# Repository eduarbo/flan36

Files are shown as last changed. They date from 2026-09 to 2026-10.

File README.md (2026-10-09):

# Flan36

**36 keys. Original design. Your keycaps, your frames.**

**[Explore and customize in 3D →](https://eduarbo.github.io/flan36/)** · **[Parts and buying links →](docs/parts.md)** · **[Edit in FreeCAD →](docs/freecad.md)**

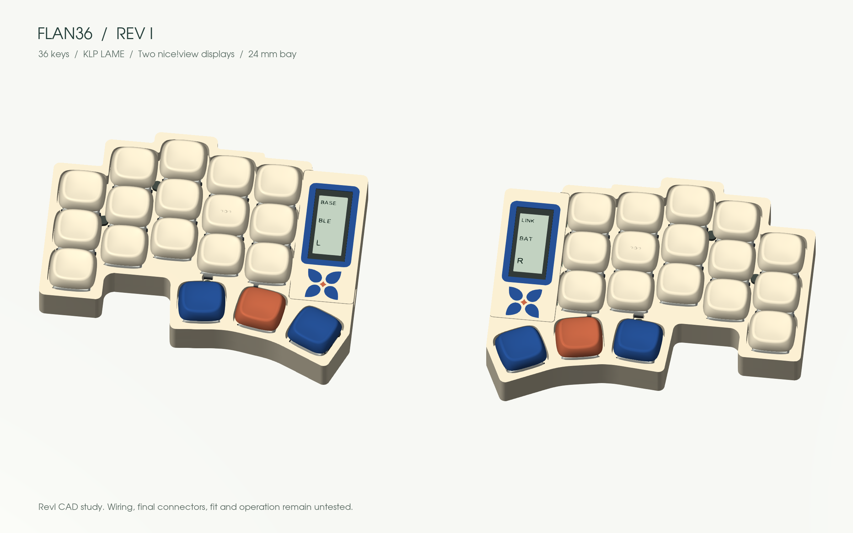
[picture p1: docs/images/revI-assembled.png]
Flan36 revI with interchangeable display frames and original KLP Lamé keycaps


*RevI: key-aligned local curves, four interchangeable cases, optional exposed display stack, magnetic frames and a floor-mounted cell in either battery size. Physical fit untested.*

**[Themes and print kits](docs/themes-printing.md)** — Twenty-eight coordinated themes, personal keycap palettes, linked rim/frame colors and selected STL/3MF parts.

**[Lower, level stack](docs/level-stack.md)** — The frame and removable switch-covering shell reach 13.59 mm; the glass sits 0.20 mm below them. Connector fit remains unqualified.

**[Case variants](docs/cases.md)** — Level, Solid, Color rim and Terrace; actual meshes in the explorer.

Flan36 is a low-profile wireless split keyboard in development by [Eduardo Ruiz](https://github.com/eduarbo). Its original CAD is designed by Eduardo, with five columns and three thumb keys per half.

- **KLP Lamé choices:** all 38 Choc-stem variants catalogued; 28 qualify in at least one position. The viewer checks complete combinations and exports a configuration for FreeCAD.
- **Magnetic frames:** Talavera (default), Game Boy, SNES, 2000s Phone, iPod and Hanafuda. Up to four solid colors in flush inlays, with matching rim and key palettes.
- **Keycap colors:** paint all keys, rows, columns or individual keys; save and share your own palettes.
- **Free tools:** KiCad for electronics, FreeCAD for the case, StepUp for exchange. Editable source, STEP/STL, offline viewer and GLB included.
- **Intended hardware:** Choc v1 hot-swap, two nice!nano controllers and two nice!view displays. One display remains the fallback.

**Status: routed prototype; physical qualification pending.** Both PCBs pass DRC, schematic parity and ERC with no unconnected items. Three [ZMK firmware builds](docs/firmware.md) cover two displays or a left-only display. [Prototype fabrication files and verification](docs/electronics.md) are included. Exact connectors, printed retention, BLE, charging and measured power still need hardware tests.

Measured rim and mirrored case halves

**[Keycaps and frames](docs/customize.md) · [Design](docs/design.md) · [Build](docs/build.md) · [CAD files](docs/cad.md) · [Progress](docs/progress.md)**

[Piantor by beekeeb](https://github.com/beekeeb/piantor) inspired the number of keys. The viewer uses [KLP Lamé by braindefender](https://github.com/braindefender/KLP-Lame-Keycaps). [Credits and licenses](ATTRIBUTION.md). [Contributing](CONTRIBUTING.md).

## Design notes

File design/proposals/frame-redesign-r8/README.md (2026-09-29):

# R8 — historical selected frames + Evangelion

**Subsequent decision:** Evangelion was rejected and removed from the current gallery. [The current selection](../../frame-selection.json) contains only the six approved designs. These frozen R8 sources document the historical proposal, not an active approval request.

Six selected designs retain their exact paths and palettes: Talavera, Game Boy, SNES, Phone, iPod and Hanafuda. The six R7 Mecha/Kumiko candidates were rejected. **E1 / Evangelion Unit 01 is the only new proposal**, retaining M1's exact four-color palette.

`master.json` owns the millimetre paths, HEX values and painter order. SVGs, dimensioned sheets and `Artwork-R8.FCStd` use that same source. The native document contains the seven designs as named, independently visible groups. The E1 top and oblique renders come from actual review meshes.

The existing mechanical blank remains 24 × 56 mm, with a 13.90 × 30.50 mm aperture, 0.10 mm nominal glass clearance, 2.40 mm bezel and Z13.59 mm face. All details are flat color inlays. This is approval geometry, not a print release: slicing, bonding and physical fit are unqualified. No production assembly or main-viewer change is included. Hanafuda integration follows separately; the other five selected designs are already installed.

The reference link is recorded in the master. The Evangelion motif is an original geometric fan-art interpretation; it is not traced commercial artwork or an official collaboration.

## Reproduce

```sh
python3 tools/prepare_frame_redesign_r8.py
python3 tools/render_frame_artwork.py design/proposals/frame-redesign-r8
FLAN36_ARTWORK_REVIEW=frame-redesign-r8 python3 tools/freecad/run_macos.py tools/freecad/prepare_frame_artwork_review.py
FLAN36_ARTWORK_REVIEW=frame-redesign-r8 python3 tools/render_frame_artwork_review.py
python3 tools/build_frame_review_page.py
```

SVG rasterization uses `rsvg-convert`; FreeCAD supplies its runtime; the native renderer uses VTK. Ignored meshes in `build/frame-redesign-r8/geometry/` are reproducible from these commands. Validate exact source hashes, closed geometry, top-face equivalence and saved/reopened native state using `geometry-check.json`, `render-check.json` and `review-check.json`.

After publication: `python3 tools/check_frame_review_public.py --revision R8 --commit <published-commit>` verifies every current public gallery/source file against committed bytes.

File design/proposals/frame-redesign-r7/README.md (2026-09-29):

# R7 — historical Mecha and Kumiko alternatives

**Subsequent decision:** all six R7 candidates were rejected. Hanafuda stays; [R8](../frame-redesign-r8/) contains the current selected collection and one Evangelion proposal. The frozen R7 artwork remains historical.

Hanafuda's R6 paths and palette are retained exactly following the user's selection. **M1–M3 and K1–K3 are proposals, not approved artwork.** Caramelo, Lucha, Cartucho 8 and Terminal were rejected; the old Mecha was rejected for redesign. Their historical files remain in R6, not in the active selection.

| Code | Direction | Family |
| --- | --- | --- |
| H | Hanafuda — selected, unchanged | Retained |
| M1 | Recon — purple scout armor | Mecha |
| M2 | Reactor — pale armor and cyan core | Mecha |
| M3 | Hangar — industrial service hatch | Mecha |
| K1 | Asanoha — radial leaf lattice | Kumiko |
| K2 | Kikko — hexagonal lattice | Kumiko |
| K3 | Kasane — original diagonal lattice | Kumiko |

`master.json` owns millimetre coordinates, solid HEX palettes and painter order. The 1:1 SVGs, dimensioned sheets and `Artwork-R7.FCStd` use these exact paths. Review solids are material partitions of the existing blank: 24 × 56 mm, 13.90 × 30.50 mm opening, 0.10 mm nominal glass clearance, 2.40 mm bezel, face at Z13.59 mm. No mounting, stack, PCB or production viewer change is included.

The native review arranges the six candidates in two rows and selected Hanafuda below. Toggle named groups or material solids to inspect them. `geometry-check.json` validates closed solids, no overlaps or clipping, exact top surfaces and save/reopen. Kumiko strips have 0.80–0.85 mm nominal widths; this is a colored-inlay interpretation, not functional wooden joinery. Slicing and physical fit remain unqualified.

Pattern references are recorded in the master. The geometry is original, not traced from commercial work. Kasane is the name of this original diagonal composition, not a claim that it is a historical pattern.

Reproduce from the repository root:

```sh
python3 tools/prepare_frame_redesign_r7.py
python3 tools/render_frame_artwork.py design/proposals/frame-redesign-r7
FLAN36_ARTWORK_REVIEW=frame-redesign-r7 python3 tools/freecad/run_macos.py tools/freecad/prepare_frame_artwork_review.py
FLAN36_ARTWORK_REVIEW=frame-redesign-r7 python3 tools/render_frame_artwork_review.py
FLAN36_ARTWORK_REVIEW=frame-redesign-r7 python3 tools/build_frame_review_page.py
```

SVG rasterization needs `rsvg-convert`, FreeCAD supplies its runtime, and native rendering needs VTK. Ignored review meshes under `build/frame-redesign-r7/geometry/` are reproduced by these commands. Validate with the geometry receipt, master hashes and visual comparison. After publication, run `python3 tools/check_frame_review_public.py --revision R7 --commit <published-commit>` for exact public readback.

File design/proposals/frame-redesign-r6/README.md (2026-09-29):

# R6 — six new directions

**Historical proposal.** The user selected Hanafuda unchanged, rejected Caramelo, Lucha, Cartucho 8 and Terminal, and requested another Mecha redesign. [R7](../frame-redesign-r7/) retains Hanafuda and presents the new Mecha and Kumiko choices. The original R6 artwork and geometry remain frozen here.

| Proposed design | Deferred slot | Reference |
| --- | --- | --- |
| Caramelo | Flan | Caramel glaze and the existing outline logo |
| Lucha | Tape | Mexican wrestling mask |
| Hanafuda | Orbit | Japanese card landscape, sun and mountain |
| Mecha | Manga | Original robot faceplate |
| Cartucho 8 | NES | Retro game cartridge |
| Terminal | Walkman | Compact terminal and return key |

The 24 × 56 mm blank, 13.90 × 30.50 mm display opening, 0.10 mm nominal glass clearance, 2.40 mm screen bezel and Z13.59 mm face remain fixed. No stack, mounting, assembly, theme or main viewer change is included.

`master.json` owns literal millimetre paths, painter order and HEX colors. The 1:1 SVGs, dimensioned sheets and `Artwork-R6.FCStd` use those exact paths. Each material is a complementary volume with a flush top face. The FreeCAD document arranges six named groups in a grid; each has hidden planar sources and visible review solids. `geometry-check.json` records exact source-to-solid agreement, clipping, save/reopen and display clearance. Native images use actual review meshes. LCD text in flat previews is illustrative.

Approval fixes these shapes and palettes. These files are not a print release: 0.4 mm nozzle / 0.2 mm layers remain a target, with thin tips, bonding, toolpaths and physical fit unqualified.

[Historical public readback](../../../validation/revI-frame-redesign-r6-public.json) verified the then-current gallery and native source against committed bytes. The stable gallery now shows R7.

To reproduce the original R6 gallery, use repository commit `2d4b87a`. The current gallery builder targets R7. Historical commands from the repository root:

```sh
python3 tools/prepare_frame_redesign_r6.py
python3 tools/render_frame_artwork.py design/proposals/frame-redesign-r6
python3 tools/freecad/run_macos.py tools/freecad/prepare_frame_artwork_review.py
python3 tools/render_frame_artwork_review.py
python3 tools/build_frame_review_page.py
```

SVG rasterization needs `rsvg-convert`; FreeCAD supplies its own Python; native image rendering needs VTK. The ignored `build/frame-redesign-r6/geometry/` meshes are reproducible from the committed source using the commands above. Validate regeneration through the geometry receipt, the master binding and visual comparison of the images. Proposal derivation requires the production source hash recorded in `master.json`.

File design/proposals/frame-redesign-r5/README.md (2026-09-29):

# R5 — rejected proposal

This artwork was not approved and was never installed in the main assembly. The user requested different designs. The original files remain frozen as history; see [R6](../frame-redesign-r6/) for the new exact proposals.

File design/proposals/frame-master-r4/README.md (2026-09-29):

# Frame artwork R4

> Historical approval record. The contextual R4 drawings incorrectly filled the entire display opening dark, hiding 0.25 mm beyond the PCB on each side. Use the separate [seam correction](../display-seam-r1/) and [actual-geometry comparison](../display-seam-r1/comparison.png). The six rejected designs now have [R5 proposals](../frame-redesign-r5/). The original proposal text below is preserved as history.

**Revised approval drawings.** The +0.20 mm frame/case height is selected. Artwork and display centering await approval; production CAD, PCB and viewer are unchanged.

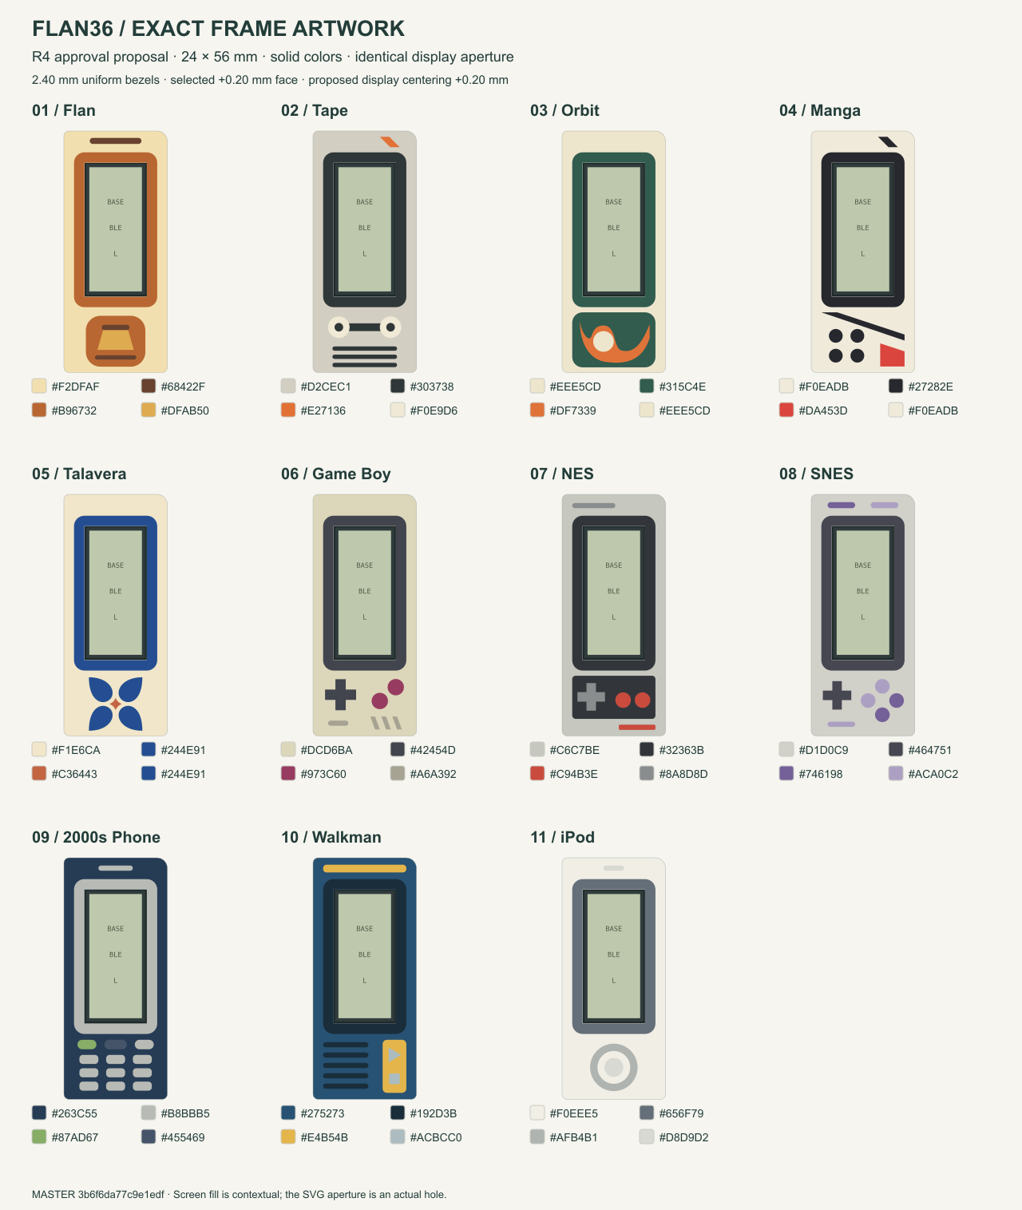
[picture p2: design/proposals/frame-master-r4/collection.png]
Eleven exact frame proposals


## What changed

- All eleven bezels are **2.40 mm wide**: the exact outward offset of the 14.50 × 31.10 mm aperture, including R2.40 outer corners. Decorative features cannot overlap this ring.
- The proposed screen center is **X12.00 mm**, giving **2.35 mm** exterior side margins. This requires moving the **whole display mating chain +0.20 mm X on the left, mirrored on the right**: module, glass, both contacts, relief, service well and PCB header footprint. The battery, MCU and mounting datums stay put. This is a visible proposal, not an already-verified hardware change.
- Talavera has a **12.40 × 12.40 mm** mirrored flower. The other designs use aligned panels, regular spacing, centered controls and separate headers. Nothing is scaled or clipped during transfer.
- Colors are solid sRGB HEX targets. All decoration is flush; no gradients or raised details. Physical filament colors require samples.

The old Talavera bezel was **3.35 / 3.75 / 6.15 / 3.05 mm** on left/right/top/bottom. Exact coordinates alone did not make its composition consistent. R4 adds an explicit equal-width and no-overlap check for every style.

The existing **24 × 56 mm mating envelope** remains: outer shell corners TL/BL/BR R1.20 and TR R2.40. These mechanical corners are distinct from the uniform decorative bezel. Making the shell corners identical would require a separate mating-geometry change; this proposal does not conceal that asymmetry.

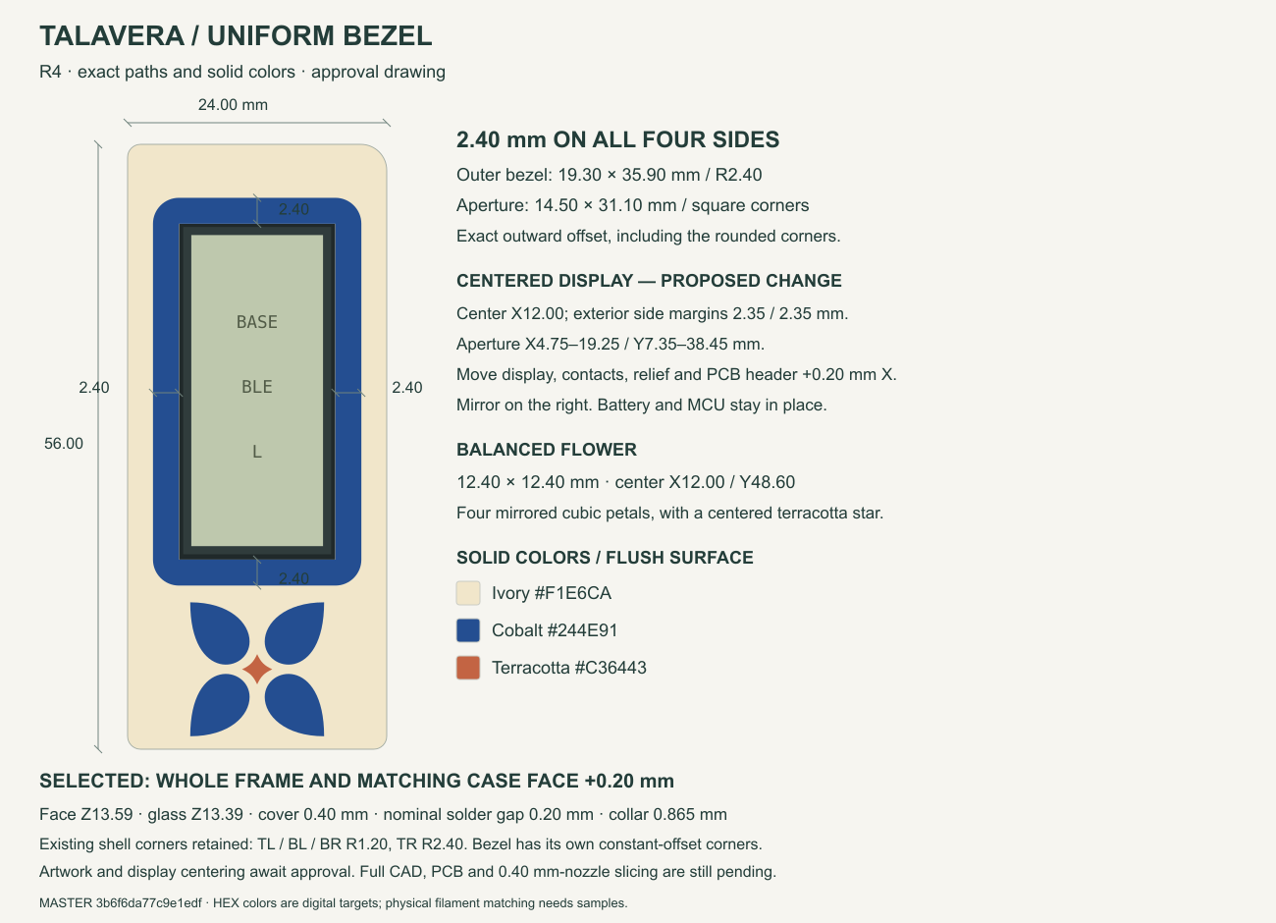
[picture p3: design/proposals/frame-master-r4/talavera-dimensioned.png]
Talavera with four equal bezel dimensions


## Selected height and 0.40 mm nozzle target

| Feature | Proposed value |
|---|---:|
| Whole frame and matching case top | Z13.59 mm (+0.20 mm) |
| Glass top | Z13.39 mm (0.20 mm recessed) |
| Pin cover | Z13.19–13.59 mm, 0.40 mm thick |
| Gap above nominal solder reserve | 0.20 mm |
| Ordinary face inlay | Z13.19–13.59 mm |
| Minimum ordinary backing | 1.00 mm |
| Through-color PCB collar | Z12.725–13.59 mm, 0.865 mm thick |

The target is a **0.40 mm nozzle and 0.20 mm layers**, with the colored frame face down. The cover then occupies two nominal layers. Nozzle diameter controls extrusion in XY; it is not the Z layer height or an exact wall-width rule. See [Prusa's nozzle-profile guidance](https://help.prusa3d.com/article/creating-profiles-for-different-nozzles_127540).

This height increase does **not** establish that every case wall, tapered motif, gap or support prints correctly. Full solids, 0.40 mm-nozzle slicing and a fit coupon remain required. The display translation also needs complete assembly collision checks and PCB route/DRC validation before release.

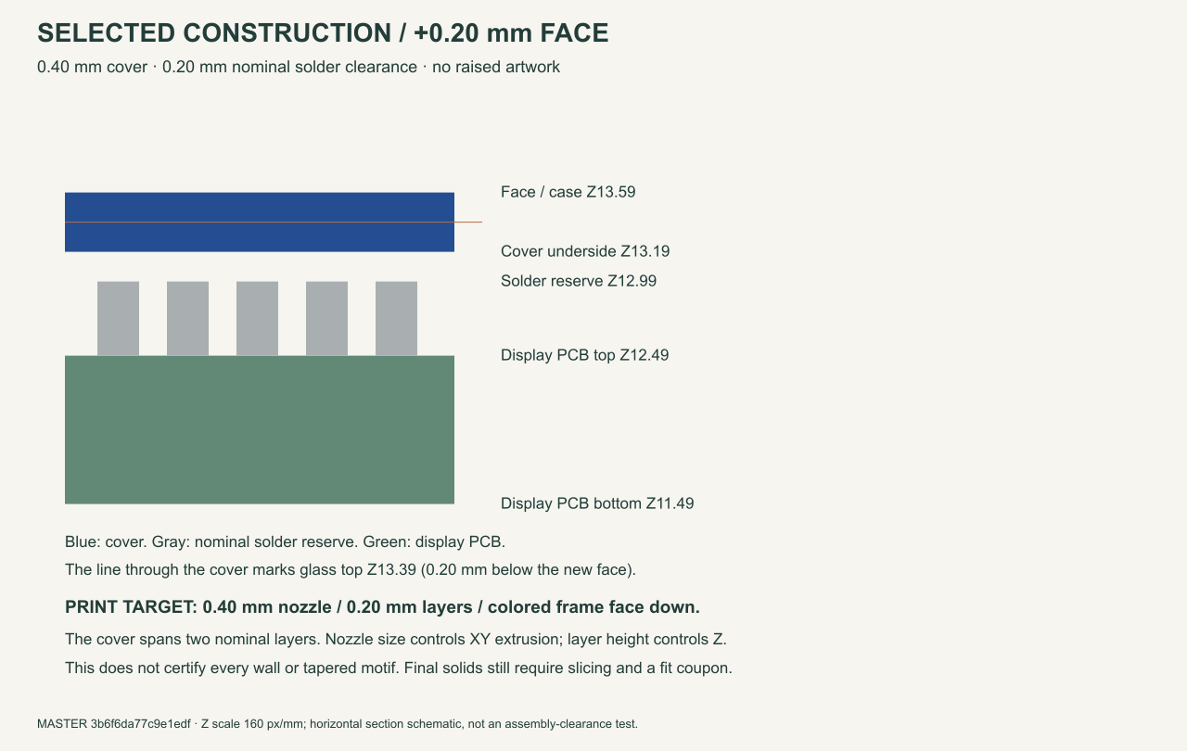
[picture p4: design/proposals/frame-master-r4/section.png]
Selected nominal section


## Exact editable files

- [Master JSON](master.json): millimetre paths, colors, order, aperture, mechanical deltas and Z intervals. This is the transfer source.
- [FreeCAD artwork](Artwork-R4.FCStd): 43 planar color regions in eleven groups, **not printable solids**. Open in FreeCAD, choose Top view and Fit all. Hide other groups with Space. Local geometry is 24 × 56 mm; group placement only lays out the collection.
- [Geometry checks](geometry-check.json): native baseline readback, equal bezel widths/offset area, no decorative overlap, exact SVG paths/colors, disjoint planar regions, complete right-side curve reflection and saved/reopened faces.
- [Review receipt](review.json): scope, findings and remaining acceptance.

| Style | 1:1 SVG | Dimensioned drawing |
|---|---|---|
| Flan | [SVG](flan.svg) | [Drawing](flan-dimensioned.png) |
| Tape | [SVG](tape.svg) | [Drawing](tape-dimensioned.png) |
| Orbit | [SVG](orbit.svg) | [Drawing](orbit-dimensioned.png) |
| Manga | [SVG](manga.svg) | [Drawing](manga-dimensioned.png) |
| Talavera | [SVG](talavera.svg) | [Drawing](talavera-dimensioned.png) |
| Game Boy | [SVG](gameboy.svg) | [Drawing](gameboy-dimensioned.png) |
| NES | [SVG](nes.svg) | [Drawing](nes-dimensioned.png) |
| SNES | [SVG](snes.svg) | [Drawing](snes-dimensioned.png) |
| 2000s Phone | [SVG](phone.svg) | [Drawing](phone-dimensioned.png) |
| Walkman | [SVG](walkman.svg) | [Drawing](walkman-dimensioned.png) |
| iPod | [SVG](ipod.svg) | [Drawing](ipod-dimensioned.png) |

Print SVGs at 100% / actual size; screen millimetres depend on display scaling.

## Transfer after artwork approval

Freeze the approved master SHA-256. Consume its paths directly, subtract the aperture and resolve the stated color order. Extrude the three explicit face domains: ordinary roof, through-color collar and pin cover. Do not trace PNGs, scale motifs, alter colors or clip to the old support mask.

Verify the exported top-face color partitions against the approved master: symmetric difference below **0.002 mm² per stable role**, bounds within **0.01 mm**, no disappearing features and exact digest provenance. Then verify the entire assembly, PCB and print files. If geometry cannot preserve the approved design, return a dimensioned revision rather than silently modifying it.

## Reproduce

From the repository root, using the existing FreeCAD installation and `rsvg-convert`:

```sh
python3 tools/prepare_frame_master_r4.py
python3 tools/freecad/run_macos.py tools/freecad/prepare_frame_master.py --revision R4
python3 tools/render_frame_master_dimensions.py --revision R4
```

The native production file is read but never saved. FreeCAD archive metadata can change its binary hash on regeneration; geometry and color checks verify the regenerated content. R3 remains as historical evidence and is not regenerated by these commands.

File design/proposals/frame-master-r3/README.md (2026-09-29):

# Frame artwork R3 — approval proposal

Superseded by [R4](../frame-master-r4/README.md). Historical correction: R3's mirror check covered the merged envelope and area, not individual decorative roles. R4 verifies each reflected color partition against independently transformed paths. The original R3 artifacts and receipt are retained below.

These are dimensioned vector designs, not generated concept renders. **Proposed, not approved.** Production CAD, PCB, frame recipes and viewer remain unchanged.

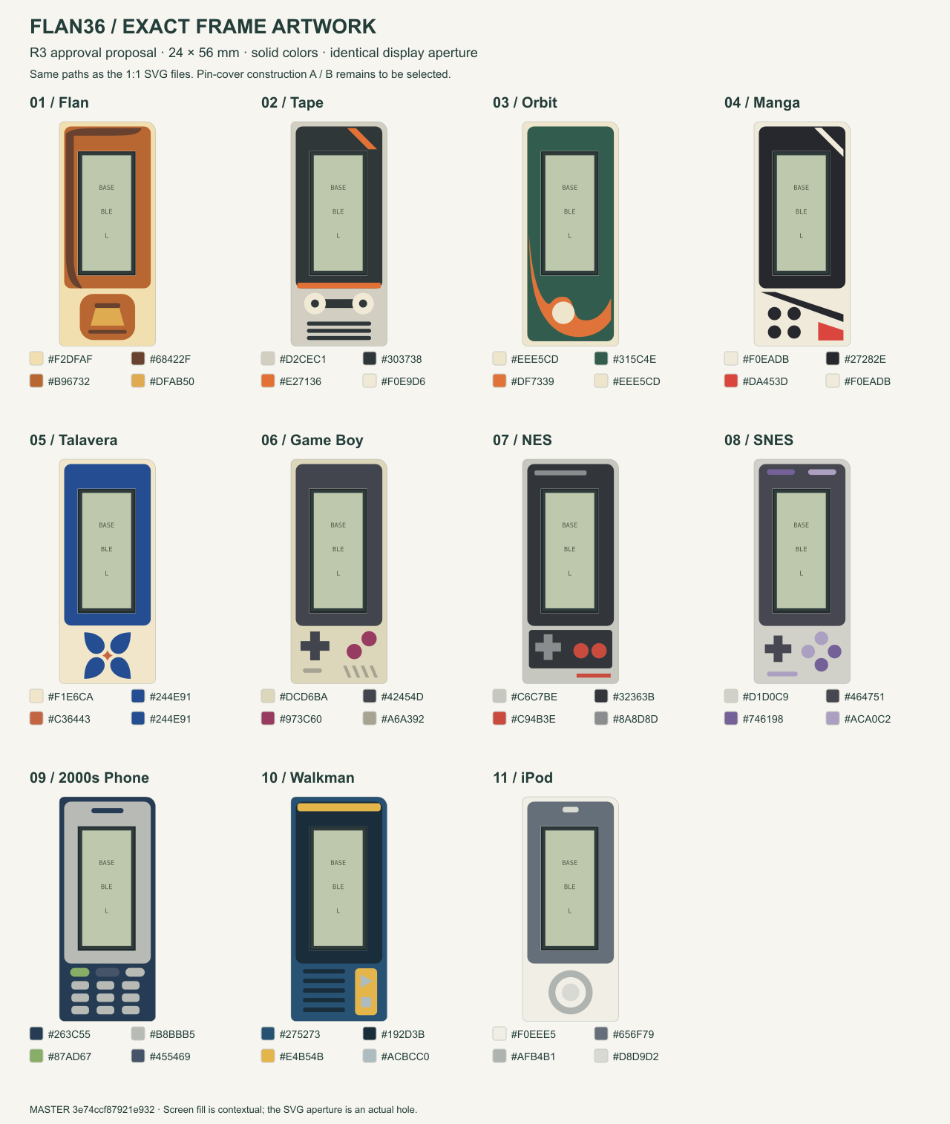
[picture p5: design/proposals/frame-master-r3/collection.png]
Eleven frame designs with exact palettes


## Files

- [Editable FreeCAD artwork](Artwork-R3.FCStd): 44 planar color regions in eleven groups. These are **2D faces, not printable frame solids**. Open in FreeCAD, choose **Top view**, then **Fit all**. Select a group or hide the others with Space. Group placements only arrange the review sheet; each part's local geometry is 24 × 56 mm.
- [Exact master](master.json): millimetre paths, Bézier control points, corner radii, color assignments, color priority and construction alternatives.
- [Talavera drawing](talavera-dimensioned.svg) and [pin-cover sections](section.svg).
- Other dimensioned sheets: [Flan](flan-dimensioned.svg), [Tape](tape-dimensioned.svg), [Orbit](orbit-dimensioned.svg), [Manga](manga-dimensioned.svg), [Game Boy](gameboy-dimensioned.svg), [NES](nes-dimensioned.svg), [SNES](snes-dimensioned.svg), [2000s Phone](phone-dimensioned.svg), [Walkman](walkman-dimensioned.svg), [iPod](ipod-dimensioned.svg). Each includes a feature-by-feature bounds table; exact curves remain in the master.
- Individual 1:1 SVGs: [Flan](flan.svg), [Tape](tape.svg), [Orbit](orbit.svg), [Manga](manga.svg), [Talavera](talavera.svg), [Game Boy](gameboy.svg), [NES](nes.svg), [SNES](snes.svg), [2000s Phone](phone.svg), [Walkman](walkman.svg), [iPod](ipod.svg).
- [Geometry check](geometry-check.json): native source readback, exact SVG paths/colors, feature bounds, disjoint color regions, complete face coverage and saved/reopened FreeCAD checks.

Print SVGs at **100% / actual size**, with no fit-to-page scaling. On-screen millimetres depend on the display; the SVG document units are millimetres.

## Geometry and color

Every design uses the existing **24 × 56 mm** frame perimeter and **14.50 × 31.10 mm** aperture. Local origin is the top-left envelope corner, X right and Y down. The actual existing outer radii are R1.20 at three corners and R2.40 at the upper-right; this proposal does not silently replace the outline.

The Talavera blue region ends exactly at the aperture. The narrow dark line in the contextual preview is the display and open clearance, not an ivory inlay. The 1:1 SVG has a real hole and no decorative screen fill.

The Talavera motif occupies an **11.60 × 11.60 mm square**, centered at **X12.00, Y49.00**. Its four mirrored cubic petals are not squashed to fill the frame width. This is the explicit, compact adaptation to the real lower space; the earlier concept image did not establish usable dimensions. Approve this actual geometry, not the earlier photograph's proportions.

Colors are solid **sRGB HEX** values. They are design targets, not claims of an exact physical filament match. All graphics are flush color regions; controls and motifs add no relief.

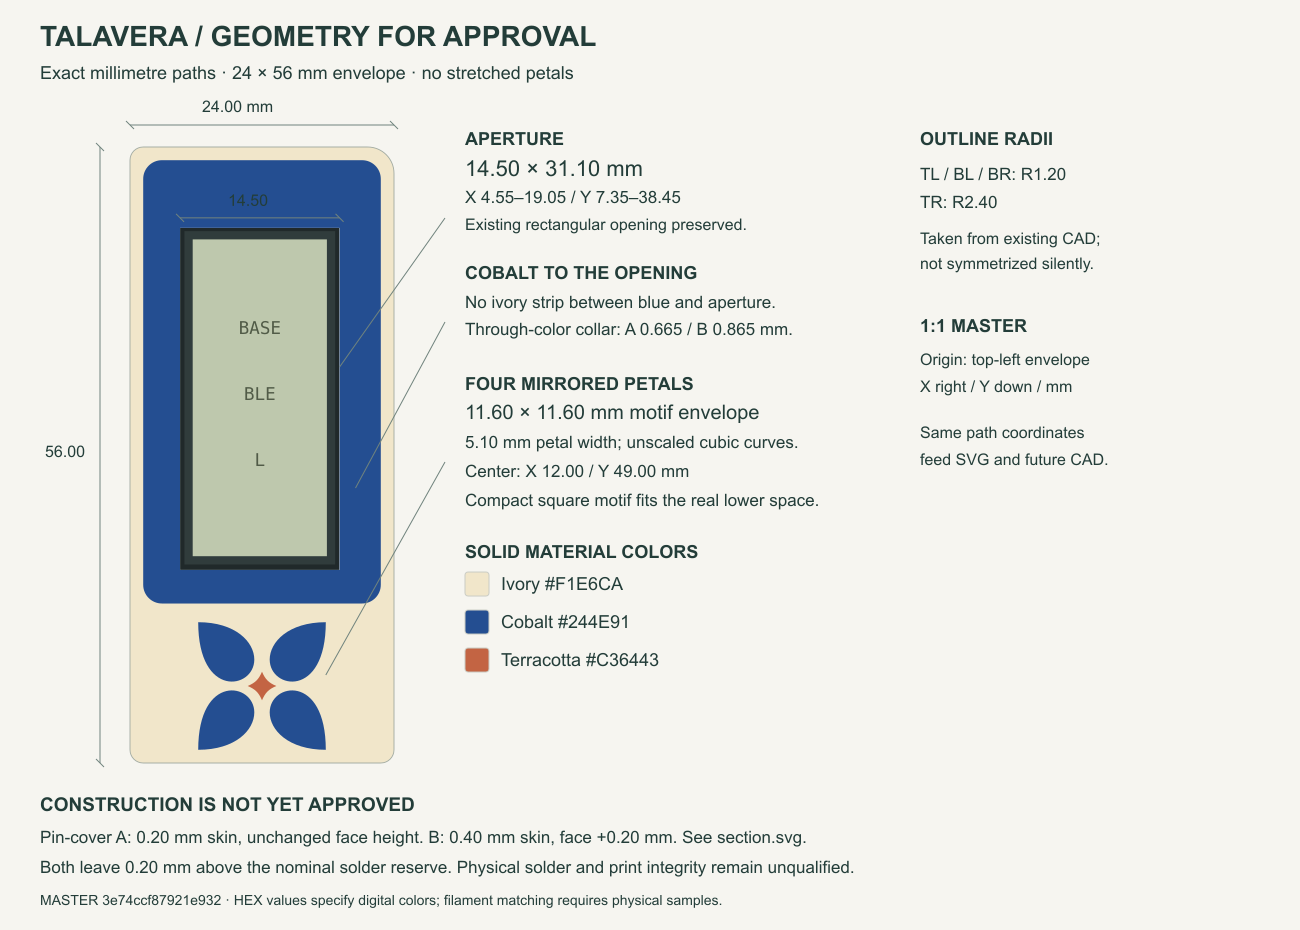
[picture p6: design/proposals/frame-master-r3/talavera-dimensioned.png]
Talavera dimensions


## Cover construction remains a separate choice

The current model puts the face and glass top at **Z13.39 mm**, the nominal solder reserve at **Z12.99 mm**, and the pin tips at **Z12.79 mm**. There is only **0.40 mm** above the solder reserve.

| Option | Cover thickness | Nominal solder clearance | Face height | Consequence |
|---|---:|---:|---:|---|
| A | 0.20 mm | 0.20 mm | 13.39 mm | Experimental thin membrane; frame height unchanged. |
| B | 0.40 mm | 0.20 mm | 13.59 mm | Face rises 0.20 mm; glass recesses 0.20 mm. Matching case height would also need approval. |

Neither option has been selected, printed or qualified on real solder joints. The drawings hide the pins **conditionally on one of these covers**. They do not claim that the current open service well is already covered. The cover is removed with the frame for service.

The proposal colors the PCB collar through its whole depth instead of cutting another recess into it. The master explicitly partitions the face into three disjoint XY domains: ordinary roof, PCB collar, and header cover. The current relief and ordinary roof undersides remain fixed in both options. **B raises the entire face and the matching case top**, not just the cover.

| Domain | Option A Z range | Option B Z range |
|---|---|---|
| Ordinary color inlay | 12.99–13.39 mm | 13.19–13.59 mm |
| Ordinary minimum backing | 0.80 mm | 1.00 mm |
| Through-color PCB collar | 12.725–13.39 mm (0.665 mm) | 12.725–13.59 mm (0.865 mm) |
| Through-color header cover | 13.19–13.39 mm | 13.19–13.59 mm |
| Matching case face | 13.39 mm | 13.59 mm |

These named exceptions must be implemented explicitly and verified after approval; the old support mask must not silently erase the design. Underlying frame walls and mounting datums remain as in the native baseline.

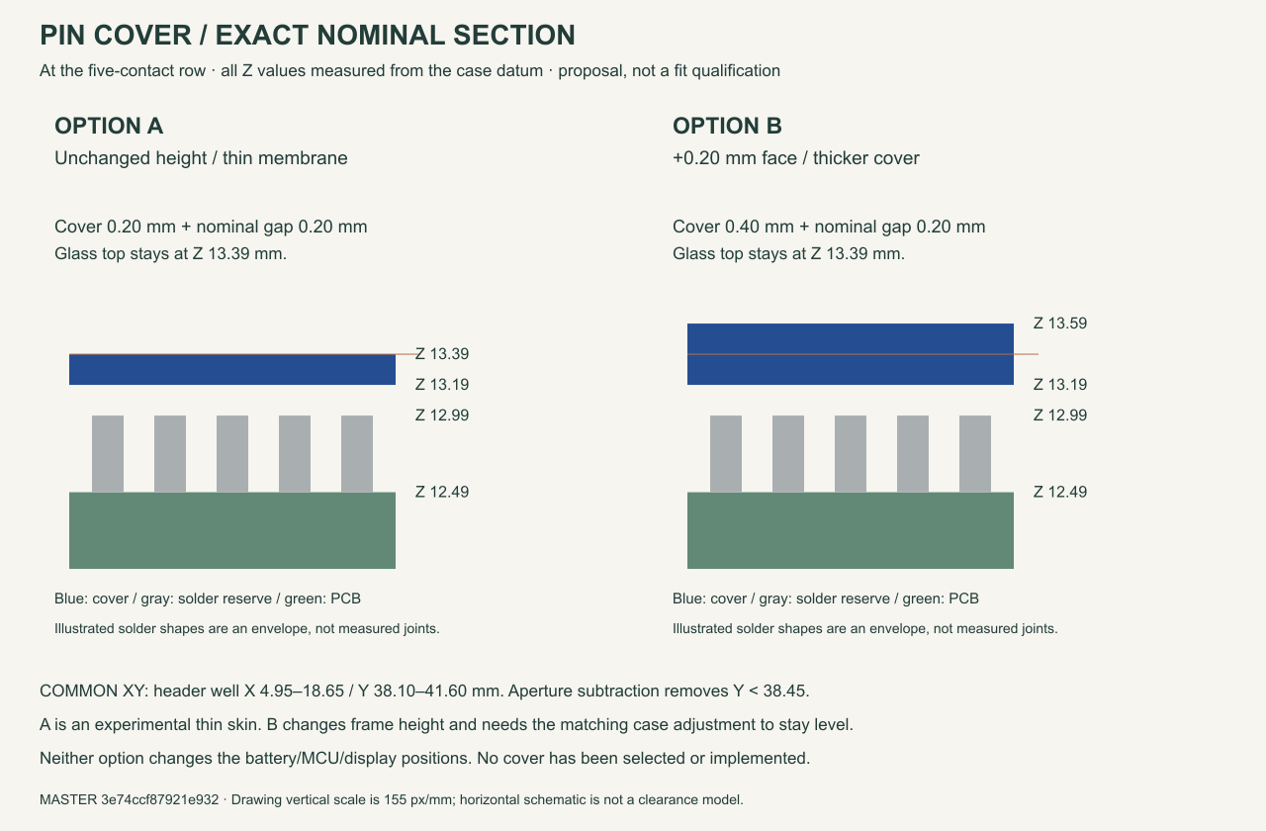
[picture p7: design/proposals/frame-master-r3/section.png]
Pin-cover alternatives


## Literal transfer after approval

1. Record the approved `master.json` SHA-256 and selected cover option. Approval of artwork alone does not approve a height or construction change.
2. Consume its closed M/L/A/C/Z paths directly, in millimetres. Apply the stated aperture subtraction and painter order. The supplied FreeCAD faces demonstrate this exact conversion.
3. Use those disjoint color regions for the approved roof construction. Preserve assembly datums, mounting interfaces and all unrelated components.
4. Compare actual CAD top-face regions against the approved regions. Maximum symmetric-difference area: **0.002 mm² per stable material role**, even when roles share a HEX value. Bound deviations: **0.01 mm**. Transform complete curves on the right half. No disappearing features, fit scaling, repositioning or support-mask clipping.
5. Check complete 3D intersections, minimum local thickness, bridge attachment and service removal. Then verify the exported files and actual viewer against the same approved digest.

If a constraint cannot preserve the approved design, stop that conversion and return a dimensioned change for approval. Do not improvise a different composition.

## Reproduce this proposal

From the repository root, with the existing FreeCAD installation and `rsvg-convert`:

```sh
python3 tools/prepare_frame_master.py
python3 tools/freecad/run_macos.py tools/freecad/prepare_frame_master.py
python3 tools/render_frame_master_dimensions.py
```

The native document is opened read-only for dimension checks and never saved. The proposal document contains no solids. Its archive hash can change on regeneration because FreeCAD stores document metadata; geometry, source digest and color checks establish reproducibility. `geometry-check.json` records the hash of the specific delivered file.

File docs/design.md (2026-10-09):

# Design

Keep Flan36’s key arrangement, a thin key area and serviceable electronics.

| Choice | Reason |
|---|---|
| 3 × 5 + 3 keys per half | Remove the unused outer column without changing the remaining centers or angles |
| Choc v1 hot-swap | Low-profile, replaceable switches |
| Two nice!nano controllers, intended ZMK firmware | Wireless halves and host connection; USB-C for charging/programming |
| Battery below controller, display above | Concentrate electronics in the existing 24 mm bay |
| Independent internal supports | Neither the battery pouch nor display glass carries the stack |
| Interchangeable opaque display frames | Hide the stack and customize its appearance without moving keys |

## The stack

The insulating saddle stays below the PCB. The cell and a narrow removable cage pass through a **12.5 × 34.4 mm opening with a local rear lead notch**. One cavity accepts the nominal Adafruit 1570 and 301230 envelopes; select either in the viewer or FreeCAD. Each battery profile has two continuous nominal 105 mm lead paths with its own cell-end transition. Supplier terminal positions, wire diameter and strain relief still need measurement. [Battery dimensions and sources](parts.md#battery).

The case is **116.75 × 94.57 mm per half**. Five stepped column tops, an orthogonal pinky foot and a shallow rounded recess follow the reference. Straight lower faces remain parallel to each thumb key, joined by **local tangent arcs**. The outside thumb flank stops at the LCD panel edge. The 21 control corners use locally bounded radii, including R2.4 finger corners where space permits. Checked exposed faces retain a **4.75 mm** margin from the switch opening to the plate edge. Fasteners stay within existing material. Both halves are exact mirrors; all 36 switch centers and angles remain unchanged.

Choose [Solid, Color rim or Terrace](cases.md). These are different base/plate geometries, compatible with the same stack and ten display frames. The printed display cover can be omitted while retaining the display and structural supports.

Measured exterior rim

The key plate stays at **7.6 mm**. Plain and decorated frames share one roof height, with no raised decoration. See [current stack dimensions](slim-flush.md). The electronics bay remains **24 mm wide**; illustrative feet add 1.2 mm. The frame ends at Y=67 mm while the low base/plate continue to the thumb. The power-switch reference is now recessed 0.1 mm inside the straight X=135 mm flank.

The frame now shares the case's **R2.4 north/outside corner** beside USB, including its tangency points. The former independent R1.2 frame corner projected about **0.497 mm** beyond that curve. The cavity, plate clearance and beveled lips follow the corrected corner; the case and PCB outlines stay unchanged.

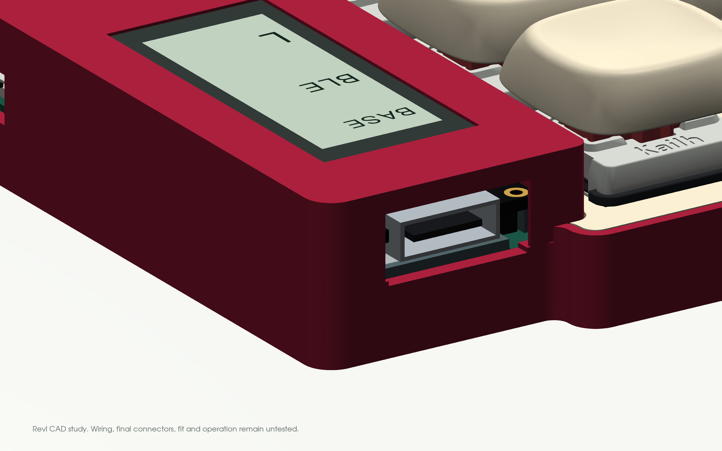
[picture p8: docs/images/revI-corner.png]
Shared corner on the actual Color rim and Smooth frame meshes


### Can the stack be thinner?

The [slim, flush redesign](slim-flush.md) lowers the display and replaces the tall generic battery-connector reserve with a dimensioned side-entry JST PH pair. It also reroutes the leads and moves reset to a recessed underside access.

All decorative colors finish at the same roof height. The selected KLP Lamé caps still reach **17.87 mm**, excluding feet; this update lowers the electronics enclosure rather than the keycap tops. Exact connector engagement, printed fits and real cable behavior remain to be measured.

The [historical support study](slim-mount-study.md) retains its original rejected candidates. Integrating washers or saddles reduces loose parts but gave **zero height reduction**. The current design keeps these supports independently replaceable.

### Magnetic frame, independent structure

Three captive **Ø2 × 3 mm magnets** in the base attract three captive **Ø2 × 4 mm steel pins** in each frame. Shallow guides locate the cover; it lifts vertically. The frame carries no battery or display load. Five internal M2 fasteners per half retain the plate/PCB independently, with no added perimeter lobes. Three use 6 mm shafts; the two hidden under the frame use 4 mm shafts.

The inserts are enclosed by a pause-and-insert print sequence. Force through the nominal **0.9 mm gap**, north-edge peel, print capture and magnet temperature remain physical tests. [Assembly sequence and coupons](build.md#magnetic-frame-and-service).

## One or two displays

The CAD shows two nice!view displays; one on the left remains the fallback if integration becomes impractical. The intended central display shows primary keyboard state. A peripheral display may show its own battery/link state; mirrored layer information is not promised. [nice!view setup](https://nicekeyboards.com/docs/nice-view/getting-started/).

nice!view is a reflective memory LCD. OLED improves dark-room visibility but uses more power; e-paper favors mostly static images and needs different mounting and firmware. These are alternatives to redesign around, not drop-in replacements. [Display specifications](https://nicekeyboards.com/docs/nice-view/).

## Modularity

Switch sockets, removable controller/display connectors, a battery connector, magnetic covers and independent screws allow servicing after initial soldering. The frames are separate from the display support. Service electronics with power off and USB disconnected; removable connectors are not a proposal for live module hot-plugging.

## CAD views

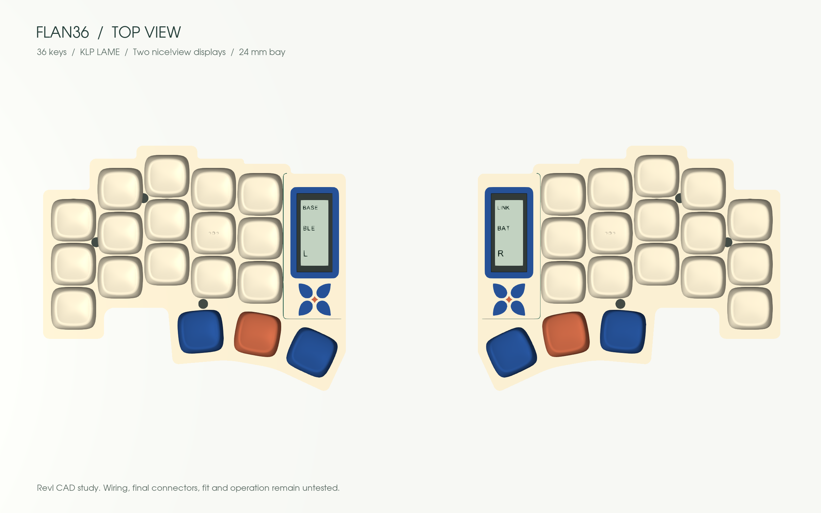
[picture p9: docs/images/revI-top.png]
RevI top view with 36 KLP Lamé keycaps and two display frames


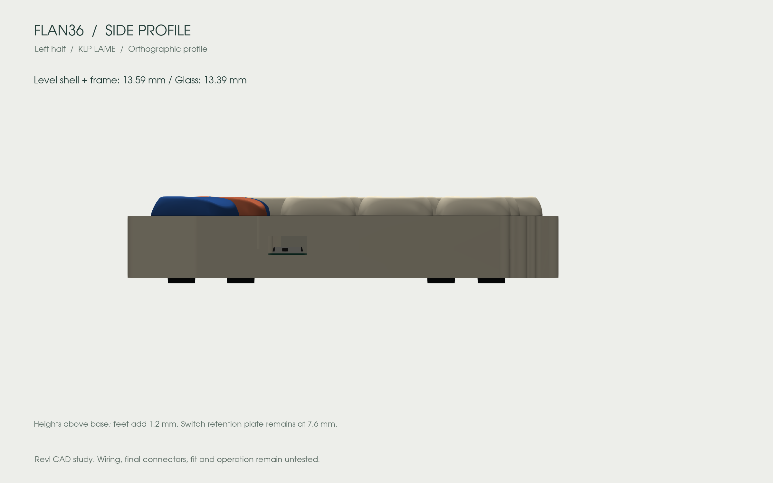
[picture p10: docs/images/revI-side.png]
RevI side profile


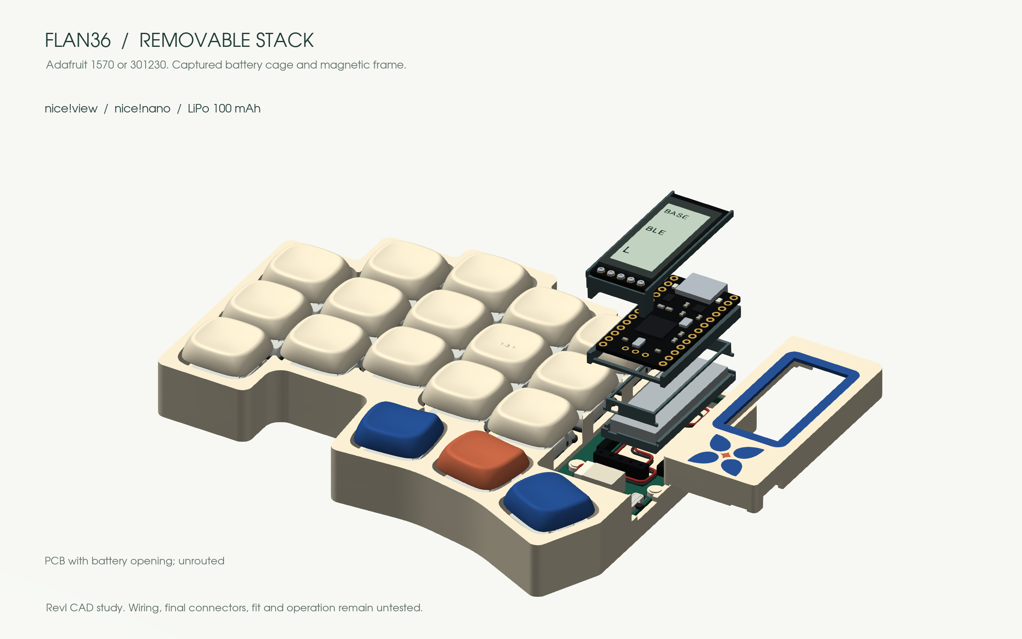
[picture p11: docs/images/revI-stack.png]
RevI exploded stack with removable opaque cover


These views come from the exported geometry. Electronics, switch bodies, keycap seating, screws and feet are nominal references. No physical assembly or functioning keyboard is established by the renders. [Source files and remaining work](cad.md).

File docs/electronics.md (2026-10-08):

# Routed electronics

Both revI boards are now routed. KiCad 10.0.6 reports **0 DRC violations, 0 unconnected items, 0 schematic parity issues and 0 ERC violations** on each serialized board and schematic. All 247 physical pads per half were checked, including duplicate pad numbers in the hot-swap footprints.

These are prototype candidates. Exact connectors, supplied cell fit, printed retention, radio performance and electrical operation remain untested. Use the [parts guide](parts.md), [assembly sequence](build.md) and [firmware](firmware.md) together.

| Half | Editable project | Prototype Gerbers and drills |
|---|---|---|
| Left | [KiCad project](../hardware/revI/flan36-left.kicad_pro) | [Left ZIP](../hardware/revI/fabrication/flan36-left-revI-prototype.zip) |
| Right | [KiCad project](../hardware/revI/flan36-right.kicad_pro) | [Right ZIP](../hardware/revI/fabrication/flan36-right-revI-prototype.zip) |

Download the repository to retain the relative libraries and 3D models. In KiCad, open the project, then PCB Editor; use **Alt+3** for the assembly view. The [FreeCAD workflow](freecad.md) remains the editable mechanical source.

Left PCB — actual copper and contour
Right PCB — actual copper and contour

## Fabrication candidate

- Two copper layers; **1.6 mm FR4**, nominal **1 oz copper**.
- Minimum routed track **0.20 mm**; netclass clearance **0.20 mm**; copper-to-edge **0.50 mm**.
- ZIPs include both copper, mask and silkscreen layers, Edge.Cuts, separate plated/non-plated drills, drill maps, source hashes and a prototype notice. Internal battery/station openings belong to Edge.Cuts.
- Inspect the fabricator's Gerber and drill preview, including internal cutouts and the narrow north bridge. No panelization or assembly service is specified here.

The exact original key angles, all footprint/pad geometry, holes, model references and outer/internal contours were preserved against `fe8c7fd`. The FreeCAD case did not change. The router's sub-micron coordinate rounding was restored before the final checks.

The right MCU uses different GPIOs so signals can escape toward the keys. Its rows use **D21/D20/D19/D18**, and column 0 uses **D15**. The left keeps D2/D3/D4/D5 and D6. All other columns and display pins are unchanged. The same [pin map](../design/pinmap.json) is checked against schematic, every PCB pad and compiled firmware. Do not flash the left file onto the right board.

## Power and assembly checks

Before installing controllers, check BAT+ to GND for shorts and verify J1 polarity against the supplied pack. J1 pin 1 is BAT+; pin 2 is GND. SW1 connects BAT+ to the controller's RAW/B+ input. Opening SW1 disconnects the cell, including from charging; USB can still power the controller. Reset connects RST to GND.

Keep the nice!nano **BOOST jumper open**. The Adafruit reference allows at most 100 mA charging; obtain the actual 301230 pack's permitted charge rate before using that alternative. A matching pouch dimension does not establish charging compatibility.

Check diode cathodes toward row nets, socket solder joints and every key before installing the case. The pin map and zero ERC result do not prove the actual modules, charging, BLE, sleep current or display wake work. Record those observations in the [hardware acceptance checklist](build.md#hardware-acceptance).

## Reproduce the checks and exports

Run from the repository root with KiCad 10.0.6 and its Python module. On macOS:

```sh
KICAD_PY=/Applications/KiCad/KiCad.app/Contents/Frameworks/Python.framework/Versions/Current/bin/python3
"$KICAD_PY" tools/check_routed_pcb.py
python3 tools/export_fabrication.py
python3 tools/check_layout.py
```

On other systems, use a Python runtime that can import `pcbnew`, and pass `--cli /path/to/kicad-cli` when needed. The geometry comparison needs the baseline commit in local Git history; use a full clone. The checker rejects unrouted boards, altered geometry, mismatched physical pads and failed DRC/ERC/parity. It writes [routing evidence](../validation/revI-routing.json); the exporter refuses stale evidence and records [package hashes](../validation/revI-fabrication.json).

`build/routing-validation/` and `build/fabrication/` are ignored, reproducible outputs of these commands. Export timestamps can differ; the receipt identifies the actual generated bytes. The editable routed KiCad boards are the source for future edits. The earlier `prepare_routing.py`, `remap_right_mcu.py` and `complete_pcb_routes.py` are migration helpers, not required to rebuild the fabrication package. Do not run an old placement generator over routed work.

The routing history used Freerouting 2.4.1 with internal cutout routing reserves, followed by local clearance repair and independent KiCad checks. Approval and bounds are recorded in the [build continuation](reviews/2026-10-08-build-continuation.md).

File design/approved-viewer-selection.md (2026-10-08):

# Approved viewer selection

The gallery withdrawal did not update the main viewer's separate frame catalog.
Flan, Tape, Orbit, Manga, NES and Walkman therefore remained selectable, and Flan
remained the fallback. Tape still had its old border; it was not repaired.

The active viewer now derives its catalog from `frame-selection.json`. It delivers
only Talavera (default), Game Boy, SNES, Phone, iPod and Hanafuda, including
previews and print assets. Hanafuda uses its approved R8 paths; the other five
retain their approved R4 artwork. Current geometry and acceptance are recorded
in the [October correction report](../docs/reviews/2026-10-07-corrections.md).

Saved and imported retired shapes resolve directly to Talavera. Explicit colors,
implicit old accent palettes, cases, batteries and caps are preserved. Startup
does not rewrite storage; the first subsequent edit preserves the original saved
JSON before migration. Camera, layer and visibility behavior is unchanged.

The native CAD, its source catalog and historical receipts retain the earlier
collection as provenance. Viewer exports materialize all colors and remain valid
inputs to the native configuration reader. Old hashed print payloads remain for
cached historical pages; the new viewer references only its approved payload.

Two independent read-only reviews agreed on this scope: derive the active catalog,
preserve original configuration bytes and colors, and require actual browser and
print-export readback. Their shared baseline was clean commit
`3e2554982e4dbd80dbc93d65aa09b246d43943b0`; all enumerated file hashes remained
unchanged after review. Their migration, fallback, stale-preset and public-delivery
concerns are covered by the checks below. No material objection remained.

## Reproduce

Use the Python rendering dependencies and the viewer's pinned npm dependencies.
Set `FLAN36_PLAYWRIGHT_MODULE` and `FLAN36_BROWSER` if reusing an installed browser
runtime.

```sh
python tools/build_viewer_revI.py
node viewer/build.mjs
node viewer/config-contract-check.cjs
node viewer/frame-collection-check.cjs
node viewer/reliability-check.cjs
# After publication:
node viewer/public-check.cjs <published-commit>
```

Ignored scenes, screenshots, 3MF/GLB/ZIP examples and test receipts under `build/`
are reproducible with those commands. Validate against the hashes and acceptance
results in [the selection receipt](../validation/revI-approved-selection.json).
The original collection and R4 delivery receipts describe their historical
snapshots and are not acceptance of the current viewer.

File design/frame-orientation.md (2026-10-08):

# Frame artwork orientation

Request: `user:20260929:no-invertir-frames-derechos`.

Both halves must show each installed frame design in the same reading direction.
The right-hand shell, corner radii, window, underside, magnets and mounting geometry
retain their existing handedness. Colors, height, keycaps and the rest of the
assembly remain unchanged.

The correction translates left artwork by −86 mm on X into the right bay. It does
not reflect the artwork or move the shell. The native document records this policy
so earlier documents without the marker still reproduce their original geometry.

Acceptance covers the saved/reopened native source, exact material regions,
STL/STEP exports, the online/offline viewer and its downloaded print kit. Asymmetric
Game Boy and SNES features must match by translation and reject the former mirrored
arrangement. Hanafuda uses the same reading direction; retired shapes stay excluded.

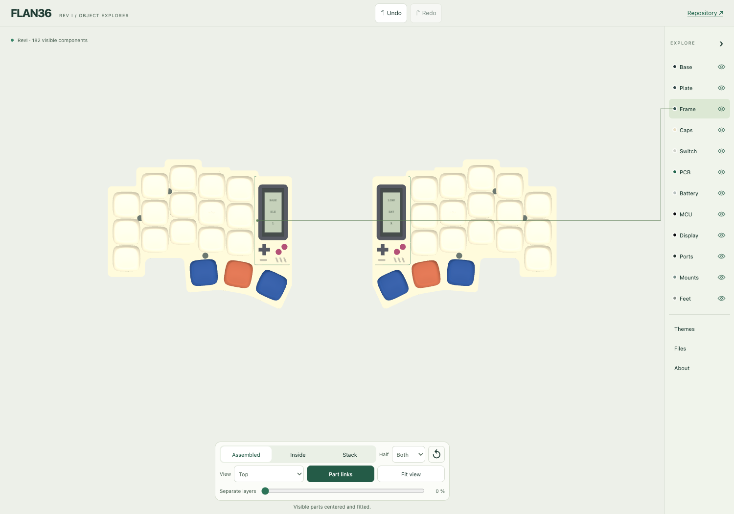
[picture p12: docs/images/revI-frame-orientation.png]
Both Game Boy frames read in the same direction


[Digital acceptance](../validation/revI-frame-orientation.json) includes the
reopened native comparison, unchanged parts, exact material exports and a real
viewer download. Physical fit qualification remains separate.

## Reproduce

Use the source from commit `4b59c1d8cfae7248a2109666ec81350c4c3b0f0c`
in a separate directory. The installer refuses to overwrite an existing candidate.

```sh
mkdir -p build/frame-orientation/source
git show 4b59c1d8cfae7248a2109666ec81350c4c3b0f0c:mechanical/revI/Flan36.FCStd > build/frame-orientation/source/Flan36.FCStd
python3 tools/freecad/run_macos.py tools/freecad/install_frame_orientation.py \
  --source build/frame-orientation/source/Flan36.FCStd \
  --output build/frame-orientation/candidate/Flan36.FCStd
FLAN36_EXPORT_OUT=build/frame-orientation/candidate \
FLAN36_EXPORT_METADATA=build/frame-orientation/candidate/revI.json \
FLAN36_EXPORT_REPORT=build/frame-orientation/candidate/mechanical.json \
python3 tools/freecad/run_macos.py tools/freecad/export_revI.py
python3 tools/adopt_frame_orientation.py build/frame-orientation/candidate
```

Once the accepted candidate and its attributable exports are adopted:

```sh
python tools/build_viewer_revI.py
node viewer/build.mjs
node viewer/finishes-check.cjs
node viewer/frame-collection-check.cjs
node viewer/frame-orientation-check.cjs
```

Browser checks use Playwright and Chromium as described in the CAD guide.
Set `FLAN36_VIEWER_URL` on the orientation check for public readback. The ignored
`build/frame-orientation/` CAD candidates, exports, screenshots and downloaded
print/GLB samples are reproducible with these commands. Historical CAD and STEP
archive metadata may differ; compare actual geometry and recorded mesh hashes.

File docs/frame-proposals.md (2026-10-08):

# Selected frames

[Open the mobile gallery](https://eduarbo.github.io/flan36/frame-proposals/).

The collection contains only **Talavera, Game Boy, SNES, Phone, iPod and Hanafuda**. Their artwork and palettes remain unchanged. No new proposals await approval.

Each gallery card includes an enlarged preview, dimensions and a 1:1 SVG. All designs use solid colors and flush details on the current 24 × 56 mm frame.

All six designs are installed in the current assembly, explorer and print exports. The native archive retains earlier geometry. [Current selection record](../design/frame-selection.json).

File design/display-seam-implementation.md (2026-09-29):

# Display seam correction

The R4 opening was 14.50 mm wide while the modeled PCB is 14.00 mm wide. Each side exposed a 0.25 mm band beyond the PCB. The approval drawing incorrectly painted the whole opening dark, hiding that geometry. Its north/south glass gaps were also unequal: 0.30 / 0.50 mm.

The seam-only correction uses local aperture **[5.05, 7.55, 18.95, 38.05] mm**: 13.90 × 30.50 mm, centered on the existing glass, with 0.10 mm nominal clearance. The five approved ScreenField paths use an exact 2.40 mm outward offset, bounds **[2.65, 5.15, 21.35, 40.45] mm**, R2.40. Every other approved motif and HEX value remains unchanged. The display, PCB, connector chain, battery, MCU, case height and mounting datums do not move.

The original R4 master remains immutable. The [correction master](proposals/display-seam-r1/master.json) records the separate delta. Its old display translation is explicitly historical and already applied. The installer changes only WindowMargin and the glass-window Y datum, then rebuilds the approved color partitions. The six R5 designs remain proposals.

Two independent reviews agreed to the bounded nominal correction after inspecting exact candidate geometry, source hashes and actual mesh renders. Both retained the limitation that 0.10 mm assembly clearance and 0.05 mm projected PCB coverage are not measured manufacturing tolerances or a guarantee of invisibility at every oblique corner. The second-round production checks are acceptance requirements, not worker-certified completion.

The prevention change is a real-footprint display preview plus candidate geometry that rejects clipping, glass interference and color partition drift. The current-versus-candidate render includes normal, 30°, 45° and 60° views. No opaque plane is painted over missing physical material.

## Reproduce

Use the pre-correction source from commit `04e1b4637645c2529e35a5e8c1727a4df1578059`. Do not overwrite production files to reconstruct proposals.

```sh
mkdir -p build/display-seam/source
git show 04e1b4637645c2529e35a5e8c1727a4df1578059:mechanical/revI/Flan36.FCStd > build/display-seam/source/Flan36.FCStd
export FLAN36_REVIEW_SOURCE="$PWD/build/display-seam/source/Flan36.FCStd"
python3 tools/prepare_display_seam_proposal.py
python3 tools/prepare_frame_redesign_r5.py
python3 tools/freecad/run_macos.py tools/freecad/prepare_frame_reviews.py
python tools/render_frame_reviews.py
python3 tools/build_frame_review_page.py
python3 tools/freecad/run_macos.py tools/freecad/install_display_seam.py \
  --source build/display-seam/source/Flan36.FCStd \
  --output build/display-seam/reproduced/Flan36.FCStd
FLAN36_EXPORT_OUT=build/display-seam/reproduced \
FLAN36_EXPORT_METADATA=build/display-seam/reproduced/revI.json \
FLAN36_EXPORT_REPORT=build/display-seam/reproduced/mechanical.json \
python3 tools/freecad/run_macos.py tools/freecad/export_revI.py
python3 tools/freecad/run_macos.py tools/freecad/check_approved_frames.py \
  --source build/display-seam/reproduced/Flan36.FCStd \
  --report build/display-seam/reproduced/geometry.json
```

FreeCAD, VTK and the SVG renderer are required as documented in the CAD workflow. Generated review meshes, logs and candidate exports in ignored `build/display-seam/` are reproducible with these commands. Current review evidence and final delivery receipts live in `design/proposals/` and `validation/`; rebuilding a frozen proposal should be done in a disposable checkout and compared geometrically because native archive metadata can vary.

After exporting the current assembly and rebuilding the viewer, run `node viewer/display-seam-check.cjs` with the Playwright settings in the [CAD guide](../docs/cad.md). It captures the actual frame, glass and support ledges from the front and an oblique angle, and checks the proposal link. Inspect both images in `build/display-seam/viewer/`; the script does not substitute a pixel assertion for visual or physical fit acceptance. Run the collection and 3MF checks in the [frame guide](../docs/frames-extra.md) for camera/configuration continuity and registered print volumes.

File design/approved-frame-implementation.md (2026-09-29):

# Approved R4 implementation

The owner approved Talavera, Game Boy, SNES, 2000s Phone and iPod. Flan, Tape, Orbit, Manga, NES and Walkman remain deferred. Their existing artwork and palettes stay available.

The [scope contract](approved-frame-master-r4.json) binds the exact approved master. The shared shell gains 0.20 mm height and a 0.40 mm pin cover; the glass stays at Z13.39. The whole display mating chain moves 0.20 mm toward the frame center on each half. The native configuration, cap placement, battery, MCU and mount datums remain unchanged.

## Why the transfer changed

The previous generator fitted artwork to a backed-roof mask and resolved overlaps by color-role priority. That could cut motifs and could not represent the approved through-color collar or covered pins. The R4 builder consumes the original curves and painter order directly, with separate ordinary, collar and cover thickness domains. It compares finished material faces against both the JSON and the saved planar approval file.

Inspection also found that the old installer reset configuration. This migration captures the original selection and colors before editing and compares them after saving and reopening. Browser tests separately verify camera and view continuity.

A failed isolated candidate caught a wrong assumption that left and right native drill indices matched. No production CAD was changed by that candidate. J2 drills are now found by their physical centers and radius, and checked against the translated socket pins and the actual KiCad STEP export. Repeating the migration on an already migrated source is rejected before edits.

The final review also caught a stale viewer checker that still required every color volume to fit a uniform 0.4 mm band. Its replacement checks the approved ordinary, collar and cover domains, includes negative controls below each permitted floor, and samples the new motifs. The native geometry and viewer bytes did not change for this checker correction.

## Acceptance boundary

Current receipts cover exact approved faces, preservation of deferred artwork, native save/reopen, nominal assembly collisions, conservative cap travel, registered STEP/STL/3MF geometry, PCB placement and viewer state transitions. Digital acceptance does not establish a working keyboard, physical print fit, connector tolerances or PCB fabrication readiness. Public delivery is checked separately against the published commit.

The earlier proposal and installation receipts retain their original snapshots. They are not rewritten to claim acceptance of the current files.

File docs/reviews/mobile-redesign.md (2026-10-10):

# Mobile viewer redesign and CAD authorship correction

> Historical review: the user subsequently rejected this layout for its small canvas and permanent controls. The [canvas workspace correction](canvas-workspace.md) supersedes its spatial design; earlier technical evidence retains its original scope.

Request: the original 2026-10-09 responsive/design audit, followed by Eduardo's explicit rejection of the first delivery as saturated, hard to navigate and insufficiently redesigned. The second request also corrects CAD authorship. Baseline: `e5c7e0833582fab0f4f55b332cc163cec097f8d2`, clean main.

The original objective remains in scope: usable responsive viewing, a coherent design, preserved functionality and verified delivery. The first responsive measurements remain historical evidence; they did not establish acceptable mobile information architecture.

## Design findings and resolution

| Finding | User-visible result | Acceptance |
| --- | --- | --- |
| Twelve component groups, visibility tools and page navigation competed above every editor. | Persistent **Customize / Parts / Files / About** navigation. Only Parts displays the component directory. | All destinations checked at seven sizes; active destination, heading and navigation remain identifiable. |
| Inspection and editing were conflated. | Customize has Case, Frame, Keys, Colors and Battery categories. Parts shows information, visibility and an explicit **Customize this part** action. | Touch all twelve groups; select, hide, solo, restore and edit; camera and configuration preserved. |
| A long mobile page separated edits from their preview. | Model stays visible while the editor scrolls. **Hide 3D / Show 3D** expands the editor; a short viewport with a focused text field hides the preview until explicitly restored. | One-half color change, short keyboard-sized viewport, navigation and preview restoration. |
| Every setting demanded attention at once. | Style previews lead; colors, finishes, per-key shape and recovery expand on demand. | Review entry states and expanded color/key forms. |
| Files mixed recovery, save and manufacturing into one long disclosure. | Separate Save your design, Print your parts, 3D & offline cards; recovery remains available below them. | JSON, recovery bytes, assembled GLB and exact native print-kit contents. |
| About inherited a parts directory, an editing status and run-together links. | Dedicated authored-product introduction, specifications, original-design credit, optional technical status and separate resource rows. | About after a selection; no editing status, selected-part controls or directory leak into the page. |
| Licenses opened every full text and scrolled away the close button. | Separate source summaries, individually collapsed full texts, persistent title/Close and focus restoration. | Scroll an expanded GPL text, close via button/Escape, return to opener. |
| Blanket “CAD derived from Piantor” misattributed Eduardo's work. | Original CAD credited to Eduardo in About, credits, README, attribution and exported GLB. Piantor is inspiration for key count. | Generated viewer and GLB wording checked; third-party notices and historical coordinate metadata retained. |

The same scene, camera, configuration and history survive navigation; no duplicate canvas or controls were introduced. On mobile, Files/About use the full workspace. On desktop the model and content remain side by side. Borders, spacing, headings and active states distinguish navigation, model, editor categories, previews and supplementary information.

## Independent review and corrections

Two independent read-only reviewers used constructive design and adversarial reliability lenses. Both recommended the same four-destination information architecture and a bounded authorship correction preserving source notices. They inspected the implementation and screenshots across phone, landscape and desktop, including every editor. Both found the new View dialog exposed an old Escape handler that cleared selection; one also identified the residual selected-row attribute. Both are corrected and covered by state assertions. The scrolling directory now clips its links to the inspector viewport as well as the directory; hiding the 3D preview suppresses the link. Stale component instructions were aligned with the explicit Customize action.

Known root edits were compared against recorded before/after hashes; neither reviewer mutated files. Their review was advisory. Screenshots and browser assertions do not represent Eduardo's design approval or testing on a physical iPhone.

## Verification and reproduction

```sh
node viewer/build.mjs
node viewer/config-contract-check.cjs
node viewer/rebrand-check.cjs
FLAN36_PLAYWRIGHT_MODULE=/path/to/playwright FLAN36_BROWSER=/path/to/full-chromium node viewer/responsive-check.cjs
FLAN36_ENGINE=webkit FLAN36_PLAYWRIGHT_MODULE=/path/to/playwright node viewer/responsive-check.cjs
FLAN36_PLAYWRIGHT_MODULE=/path/to/playwright FLAN36_BROWSER=/path/to/full-chromium node viewer/reliability-check.cjs
```

Use full Chromium headless, not the separate headless shell on this Mac. Existing test runtime versions: Chromium 151.0.7922.34 and WebKit 26.5; no project dependencies were changed. If preparing additional Playwright browsers, preserve existing caches with `PLAYWRIGHT_SKIP_BROWSER_GC=1`.

The responsive matrix is 320×568, 390×690, 430×820, 768×1024, 844×390, 1024×768 and 1440×960. It covers 28 destination layouts plus the model after gestures; captures every destination, both dialogs and the five editors, including expanded forms. It checks actual rendered model bounds, persistent navigation, section scroll, camera and saved design invariants, twelve visibility controls, one-half color editing, history, selection, dialog Escape/focus and clipping of links. Keyboard space is simulated by viewport reduction; a physical iOS keyboard was not tested.

`validation/revI-mobile-redesign.json` binds source hashes and results. Generated scene geometry, imported sources, layout metadata and print payload remain unchanged. Browser downloads, logs and full screenshot matrices in ignored `build/mobile-redesign/` and `build/reliability-fix/` are regenerated with these commands. Selected public screenshots under `docs/images/viewer-mobile-*.png` are copied from the 390 px WebKit capture. No user screenshots or browser profiles enter Git.

## Bounded retrospective

The prior audit emphasized framing, overflow and target dimensions while under-sampling information architecture and full user journeys. That allowed a technically responsive but crowded interface, a misleading About page and an unusable license presentation to pass. The prevention is a finite four-destination visual matrix plus editor, dialog and selection flows, not another blanket “responsive passed” claim. Historical receipts are preserved and explicitly superseded for design acceptance. CAD authorship was corrected across current user-facing descriptions and exports without rewriting geometry or third-party provenance.

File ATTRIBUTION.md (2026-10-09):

# Credits and licenses

Flan36 and its CAD are an original design by Eduardo Ruiz. Piantor by beekeeb was an inspiration for the number of keys. Imported reference files and third-party component meshes are credited individually below; their provenance does not make the complete Flan36 CAD a derivative of Piantor. There is no implied affiliation or certification by beekeeb or component manufacturers.

| Material | Author / source | License and changes |
|---|---|---|
| `sources/piantor/*.kicad_pcb` | beekeeb / Leo, [Piantor](https://github.com/beekeeb/piantor), commit `cd847afb4f9a86e8c1c8e36f243140644013afb2` | GPL-3.0; unchanged original copies |
| Choc footprint `keyswitches:Kailh_socket_PG1350_optional` | daprice, [keyswitches.pretty](https://github.com/daprice/keyswitches.pretty) | CC-BY-SA-4.0; notice in [LICENSES/Keyswitches.md](LICENSES/Keyswitches.md) |
| `Keebio-Parts:TRRS-PJ-320A` footprint | [Keebio](https://github.com/keebio/Keebio-Parts.pretty), commit `063565dcba9a8ee807d49772de0ed75ecaedcc26` | MIT; copyright/permission in [LICENSES/Keebio-MIT.txt](LICENSES/Keebio-MIT.txt) |
| `RPi_Pico:RPi_Pico_SMD_TH` footprint | [TPCWare / Nicola Carandini](https://github.com/ncarandini/KiCad-RP-Pico), commit `dc6f9b9f213dc36eebce626aa9ee72a333fa0db3` | [TPCWare license](LICENSES/TPCWare-KiCad.txt): CC-BY-SA-4.0 with design exception |
| Standard KiCad footprints, including `Resistor_SMD:R_1206_3216Metric_Pad1.30x1.75mm_HandSolder` | [KiCad libraries](https://www.kicad.org/libraries/license/) | [CC-BY-SA-4.0 with design exception](LICENSES/KiCad-Libraries.md) |
| `design/layout.json`, layout diagram | Archived coordinate-reference provenance: Piantor source commit and source-coordinate fields | GPL-3.0; existing reference metadata retained unchanged. This is file-level historical provenance, not attribution of the complete CAD |
| `keycaps/*.stl`, `keycaps/variants/*.stl`, KLP meshes in FCStd/viewer/GLB | [KLP Lamé by braindefender](https://github.com/braindefender/KLP-Lame-Keycaps), commit `4a67a824232d3054c61599ea047c56a340faaba2` | CC-BY-SA-4.0; unchanged meshes, placed and colored. RevG catalogs all 38 Choc-stem files, Choc/MX body sizes. [Original three sources](keycaps/sources.json), [complete pinned sources](keycaps/variants-source.json) |
| `docs/images/revE-*.png` through `revI-*.png`, including case screenshots, and `docs/images/viewer-*.png` | Original Flan36 CAD renders incorporating credited KLP Lamé meshes | CC-BY-SA-4.0; calculated from attributed meshes, no image retouching |
| Original CAD, project tools and original documentation | Eduardo Ruiz / Flan36 contributors | GPL-3.0-or-later, except identified materials above |
| Embedded 3D engine | [Three.js](https://github.com/mrdoob/three.js), 0.180.0 | MIT; full [notice](LICENSES/Three-MIT.txt) also embedded in offline HTML |
| External product photos in the parts guide | Typeractive, Adafruit and respective rights holders | Linked/embedded from supplier listings; not copied into the asset tree or relicensed under the repository license |

The viewer retains source notices; exported GLB includes attribution and source/license links. Viewer code is under GPL-3.0-or-later; esbuild is a pinned build dependency. Gzip packaging does not alter the underlying geometry.

The three `docs/images/branding/flan36-*-concept.png` boards were generated with OpenAI's built-in image generation tool for Eduardo's Flan36 identity exploration. They are concept art, not renders of the measured CAD. Four additional Caramel refinements (`flan36-caramel-soft.png`, `flan36-caramel-drop.png`, `flan36-caramel-bold.png`, `flan36-caramel-outline.png`) use the selected Caramel board as their reference. Prompts and provenance are retained in `design/branding-prompts.json`, `design/branding-caramel-prompts.json` and `design/branding.json`; their reuse follows the repository's GPL-3.0-or-later terms to the extent applicable.

Full texts: [GPL](LICENSE), [CC-BY-SA-4.0](LICENSES/CC-BY-SA-4.0.txt). Original upstream hashes: [sources/manifest.json](sources/manifest.json).

Libraries under `hardware/revF/libraries` contain KiCad sources with the design exception, daprice’s Choc footprint under CC-BY-SA-4.0, and Flan36 symbols/footprints. STEP files under `hardware/revF/models` are original nominal envelopes, not manufacturer-certified models.

FreeCAD, StepUp, ZMK, Zephyr, nice!nano and nice!view retain their own names/licenses. FreeCAD/StepUp are installed separately; firmware candidates are distributed with pinned sources and [dependency notices](firmware/NOTICE.md). Supplier links do not imply sponsorship.

## Commercial component representations

KiSwitch Choc v1 source CAD is used under its MIT option (copyright 2019–2022 keyswitch-kicad-library contributors). KiCad PCM12, TL3342 and SOD-123 assets use CC-BY-SA-4.0 with the KiCad library exception. See [per-file sources, transformations and limits](components/README.md) and [asset hashes](components/sources.json). nice!nano v2 is an original nominal reconstruction referenced to official photographs and the Woovie community drawing; no official photograph is embedded or relicensed.

The `docs/branding/outline/flan36-*.svg` artwork is a deterministic vector conversion of the selected Outline board’s monochrome reference. Letterforms are traced paths, not a bundled or substituted font. Source, reference hash and contour checks are recorded in `tools/build_outline_logo.py`, `validation/branding-outline-trace.json` and `design/branding-outline-vectors.json`. The preview and SVG kit follow GPL-3.0-or-later to the extent applicable.

## CAD authorship correction · 2026-10-09

Earlier viewer credits, GLB metadata and project descriptions incorrectly described the whole CAD as derived from Piantor. Eduardo Ruiz clarified that the CAD is his original design and Piantor inspired the key count. Current descriptions and exports reflect that correction. Historical coordinate-reference metadata, archived upstream copies and third-party license notices are preserved; no geometry or license terms changed.

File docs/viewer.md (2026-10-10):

# Using the viewer

[Open Flan36](https://eduarbo.github.io/flan36/) · [Download the complete offline viewer](https://eduarbo.github.io/flan36/offline.html)

Drag to orbit, scroll or pinch to zoom, and right-drag or use two fingers to pan. **Fit view** recenters the visible parts. Open **View** for angle, half, layer separation, part links and reset. Changing a case, frame, keycap, color or battery keeps your camera, hidden parts and layer separation. Resizing or rotating the screen preserves your viewing angle, pan and zoom; the projection adapts to the available canvas so a fitted model stays framed.

The viewer opens with the editor closed. The canvas occupies the workspace above one compact bottom tool strip; there is no header or floating toolbar.

- **Design** opens the editor. Choose Case, Frame, Keys, Colors or Battery from its category selector. **Expand / Compact** changes its size, the grip lets you resize it, and **×** closes it. On portrait screens it opens as a compact bottom panel; on wider screens it opens as a narrow side panel. Secondary colors, finishes and key-shape controls expand on demand.
- **Parts** opens the twelve component groups and visibility controls. Select a part for details, then use **Customize this part** to edit it. Tapping an editable part directly in the model while in Design opens its editor and targets that half/key.
- **View** contains Assembled, Inside and Stack presets, viewing angles, half selection, layer separation, part links and reset. **Fit** is directly available on the tool strip.
- **Files** opens JSON, print kit, GLB, offline download and recovery. **About** contains original design and CAD by Eduardo Ruiz, dimensions, resources and credits. Full license texts expand individually; their close button remains visible.

Selecting the already-open destination closes its panel. Closing and reopening preserves the current category, scroll position and panel size for this session. Destinations, resizing and orientation changes preserve the camera, design, visibility and history. Files and About initially open larger on portrait screens and can be compacted or closed. A short text-entry viewport temporarily enlarges the editor while retaining the canvas.

The resize grip also works with arrow keys and Home/End. Escape first dismisses an open dialog, then closes an open editor while preserving selection; with both closed it clears selection. Closing restores focus to the opener. Hover or focus a component in Parts to highlight it; its connection line hides when its entry is clipped or its panel is closed.

The eye controls affect visibility. Open **Individual parts** to toggle one piece. **Show all** restores the assembly. **Solo** isolates the selected component. Case, frame and battery controls have explicit **Both / Left / Right** targets; the battery target follows the component you select.

**Undo / Redo** keeps 40 design steps during the current session. Ctrl/Cmd Z and Ctrl/Cmd Shift Z work outside text fields. One continuous color gesture is one step. View changes are separate from design history.

In **Files**, give your design a name and save its JSON. Load that file to return to the same shapes, per-key colors, frames and batteries. JSON also transfers selections to FreeCAD.

## Saved data and recovery

Opening the viewer never overwrites saved data. If an older or damaged value cannot be read, it stays intact and a **Save warning** links to recovery.

Two current viewer tabs cannot silently replace one another's changes. A stale tab keeps a separate recovery draft. **Files → Saved data & recovery** lets you download the original values and those drafts. You can load the saved version, export your current design separately, or explicitly use it as the saved version; replacement keeps a recovery copy first. Palette conflicts use the same protection. Import recovered palette files through **My palettes**.

If browser storage is unavailable, the design remains editable and exportable in that tab. Export before closing. Session undo does not survive a reload.

## Online and offline

The online viewer loads print files only when you request a print kit. A failed download can be retried without changing the design. Files are matched to the viewer version before use.

Use the **Download offline viewer** link for a complete, single-file copy. It opens without a server or network and includes configuration, GLB and print-kit export. The smaller online `index.html` alone is not the offline download.

GLB exports all installed parts assembled, regardless of hidden layers or exploded offsets. Its units are meters; use FreeCAD/STEP for solid editing.

Both use the same full-resolution geometry. Print kits preserve the exact native STL files; 3MF retains the registered material volumes. These checks do not qualify physical fit, electronics or a print process.

## Reproduce the checks

With the locked viewer dependencies installed:

```sh
node viewer/build.mjs
node viewer/config-contract-check.cjs
node viewer/rebrand-check.cjs
FLAN36_PLAYWRIGHT_MODULE=/path/to/playwright FLAN36_BROWSER=/path/to/chromium node viewer/responsive-check.cjs
FLAN36_ENGINE=webkit FLAN36_PLAYWRIGHT_MODULE=/path/to/playwright node viewer/responsive-check.cjs
FLAN36_PLAYWRIGHT_MODULE=/path/to/playwright FLAN36_BROWSER=/path/to/chromium node viewer/reliability-check.cjs
FLAN36_PLAYWRIGHT_MODULE=/path/to/playwright FLAN36_BROWSER=/path/to/chromium node viewer/loading-check.cjs
```

Outputs under `build/reliability-fix/` are ignored, reproducible test artifacts. The [execution plan](reviews/reliability-plan.md) and [reliability receipt](../validation/revI-reliability.json) record scope and results at their stated revision. Historical delivery receipts retain their original hashes and scope.

After publication, pass the exact published commit to both readbacks:

```sh
python3 tools/check_public_delivery.py <published-commit>
FLAN36_PLAYWRIGHT_MODULE=/path/to/playwright FLAN36_BROWSER=/path/to/chromium node viewer/public-check.cjs <published-commit>
```

The first matches the anonymous source archive and served viewer assets against Git. The second checks the actual public scene, camera continuity, configuration export and native print-kit hashes in a disposable browser profile. `python3 tools/restore_reliability_review.py` restores the ignored advisory review artifacts from their committed receipt.

Save serialization uses the browser [Web Locks API](https://developer.mozilla.org/en-US/docs/Web/API/Web_Locks_API). Without it, the viewer preserves a separate recovery draft and offers JSON export instead of overwriting shared saved state.

## Responsive design verification

The [canvas workspace audit](reviews/canvas-workspace.md) supersedes the earlier mobile layout, which the user rejected for reserving too little space for the model. `responsive-check.cjs` measures unobstructed canvas area and rendered model pixels, panel close/reopen/resize, focus and scroll continuity, five editor categories, dialogs, editing, visibility, undo/redo and touch gestures through seven viewport sizes. Outputs under `build/canvas-review/` and `build/reliability-fix/` are ignored and reproducible with the commands above. Browser emulation is not a physical iPhone test.

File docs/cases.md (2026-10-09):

# Pick a case

[Open the 3D explorer](https://eduarbo.github.io/flan36/) → **Base** or **Plate** → choose a thumbnail. Apply a design to both halves or mix them.

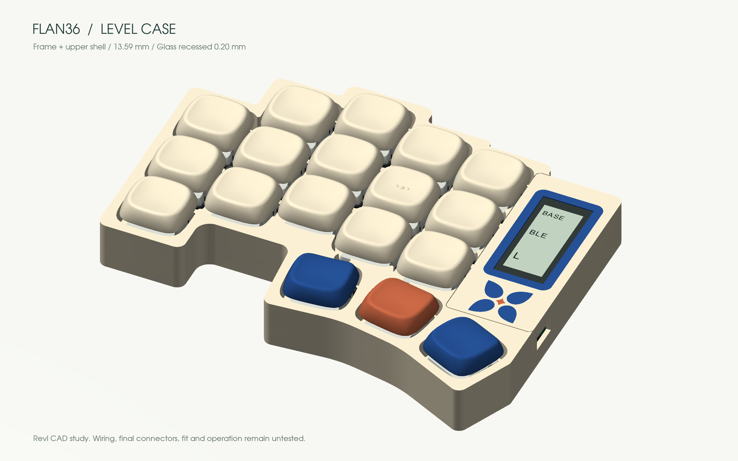
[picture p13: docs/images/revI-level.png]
Level case with flush glass and frame


| Solid | Color rim | Terrace |
|---|---|---|
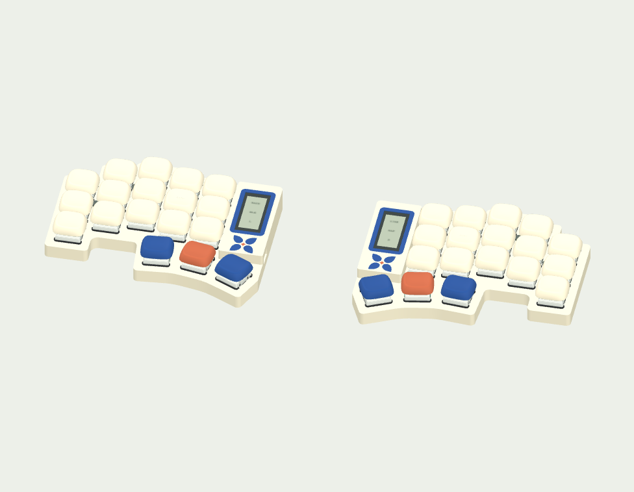
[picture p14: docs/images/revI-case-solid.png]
Solid
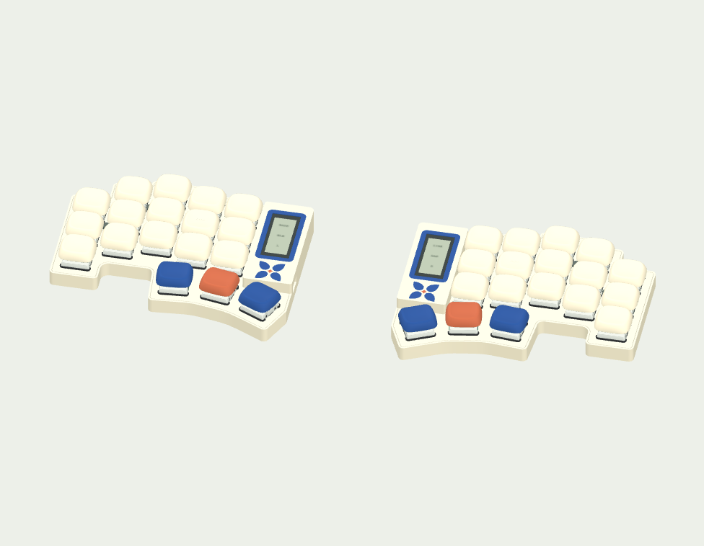
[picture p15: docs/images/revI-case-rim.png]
Color rim
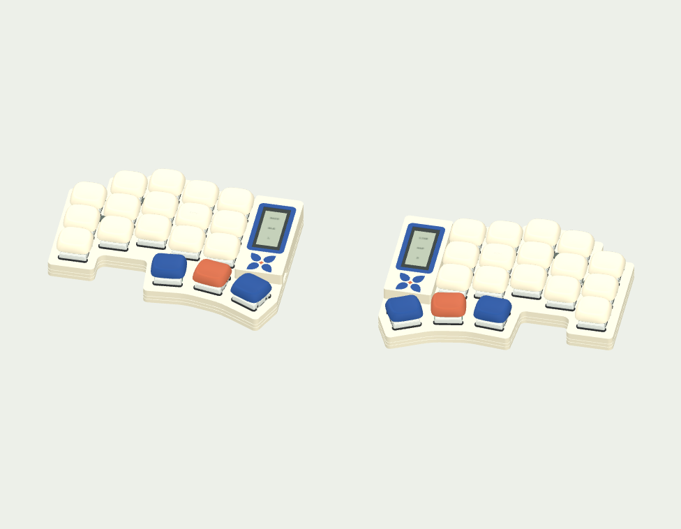
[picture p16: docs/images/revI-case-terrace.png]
Terrace
|  |  |  |

| Design | Geometry | Suggested finish |
|---|---|---|
| **Level** | Switch-covering removable upper shell at the 13.39 mm frame plane | Match upper shell and frame |
| **Solid** | Full plate over a continuous sidewall | Deep teal |
| **Color rim** | 0.9 mm wide rim flush with the plate, 1.1 mm plate inset, 0.2 mm joint | Red base + black plate |
| **Terrace** | Two 0.25 mm deep, 0.6 mm high recessed side bands | Sage base + dark plate |

All four follow the same Flan36 key positions. Straight thumb faces stay parallel to their keys; tangent arcs soften their joins. Finger corners use up to R2.4, reduced locally at short steps. The pinky backbone remains 90°. No screw adds an outward bulge, and the thumb flank stays within the display-panel edge.

The shared outline is **116.75 × 94.57 mm per half**. Its 4.75 mm straight-face allowance protects the existing pads on both boards. The Color rim changes the visible plate edge without reducing that PCB budget. Terrace leaves at least 1.05 mm nominal sidewall away from intentional service openings; the 1.4 mm floor stays unchanged.

The **Level** upper shell, frame and display glass share the **13.39 mm** plane. Its original 1.3 mm switch-retaining plate is incorporated into the same removable part, using the three existing screws. Remove the caps to reach them. Upper openings are sized from the admitted KLP travel envelopes; the selected caps still reach about 17.87 mm. [Stack dimensions and connector qualification](level-stack.md).

## Open or covered

Uncheck **Printed display cover** to expose the current stack. The display, controller, battery and structural supports remain; the printed cover and its three steel targets are omitted. Choose any display frame to reinstall it. This is the wireless nice!nano/nice!view stack, not the Raspberry Pi Pico arrangement in the inspiration photo.

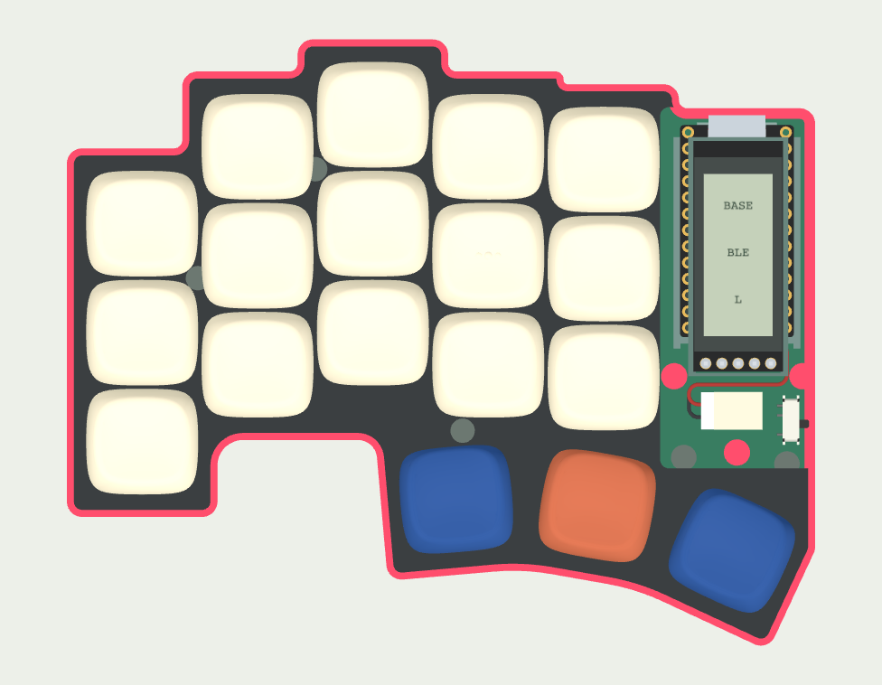
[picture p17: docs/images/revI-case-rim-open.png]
Color rim with the display stack exposed


**Eye / Solo** only change visibility. **Printed display cover** changes the saved assembly. Both choices are reversible, but only the assembly choice affects exported GLB and FreeCAD configuration.

## Edit and print

Download [Flan36.FCStd](../mechanical/revI/Flan36.FCStd) and use the [FreeCAD guide](freecad.md). `ActiveTray` and `ActivePlate` link to native `Case_solid`, `Case_rim`, `Case_terrace` or `Case_level` bodies. Edit their source sketches and boolean operations under **Construction**. No custom Python proxy is needed to reopen the document.

[All case parts](../mechanical/revI) use `left-case-{solid,rim,terrace,level}-{base,plate}.{step,stl}` and matching `right-` names. Exported parts retain assembly coordinates. The viewer saves per-half case and cover choices in JSON; import that JSON with the configuration macro. JSON without case settings inherits the current default with covers installed. The assembled GLB includes the selected meshes, including when view layers are hidden.

Print the base and plate separately for contrasting colors; a multicolor printer is optional. Use the existing [fit coupons and rebuilding commands](cad.md) before a full shell. The raised rim and recessed bands are real geometry. Nominal CAD checks do not qualify their printed strength, snap or thread fit, magnetic holding force or actual electronics clearances.

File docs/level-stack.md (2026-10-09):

# Floor-mounted battery and level case

**Current R4 adjustment:** the frame and Level upper shell now reach **13.59 mm**. Glass remains at **13.39 mm**, recessed **0.20 mm**. A **0.40 mm** cover hides the display pins; the whole display mating chain moves 0.20 mm toward the frame center. [Approved frames and current verification](frames-extra.md).

The following dimensions describe the earlier Level installation and are retained as its history.
This prototype brings the **frame, display glass and Level upper shell to the same 13.39 mm plane**, lowering the frame by **1.41 mm** from the previous 14.8 mm design. Heights start at the case underside and exclude feet. The selected flat KLP caps still reach about **17.87 mm**, so overall keyboard height is unchanged; the switches and key positions have not moved.

Current R4 Level assembly; historical dimensions follow below

| Part | Previous Z | New Z |
|---|---:|---:|
| Battery underside | 2.00 mm | 1.40 mm, directly on the case floor |
| Battery cage roof | 6.20–6.80 mm | 5.60–6.20 mm |
| nice!nano PCB underside | 8.80 mm | 8.20 mm |
| nice!view PCB underside | 12.40 mm | 11.49 mm |
| Display glass top | 14.30 mm | 13.39 mm |
| Frame and Level upper shell | 14.80 mm frame | 13.39 mm |
| Selected flat KLP keycap top | 17.87 mm | 17.87 mm, unchanged |

The battery locator now has an open bottom. Its walls locate the cell; they add no layer below it. The cage feet stay captured under the PCB. Both Adafruit 1570 and 301230 retain their own cell and cable geometry. The stored cable loops descend with the cell and rise back to the unchanged battery connector.

## Level case

Choose **Level** in the case explorer. Its upper shell hides the switch housings from the sides and meets the display frame at the same height. The Flan36 key centers, angles and outer silhouette remain unchanged.

The shell and original 1.3 mm switch-retaining plate form one removable part. It uses the same three plate screws, reached from above after removing the caps. The magnetic display frame remains independently removable. There are no new perimeter bosses or raised decorations.

The upper openings reserve all 28 currently admitted KLP variants and their allowed rotations over the full 3.5 mm travel envelope. The configurator still checks the chosen cap-to-cap and cap-to-frame arrangement. Thin intervening webs are merged into larger openings.

When **Match frame** is enabled, the Level upper shell, base and frame share a color. Turn it off to color them separately. Existing Solid, Color rim and Terrace options remain available.

## What makes the lower display possible

The nominal connector pair is **Samtec SLW-105-01-L-S + TLW-105-06-G-S**: a 4.57 mm socket and 1.52 mm header insulator create 6.09 mm board separation. The 2.67 mm mating post falls within the socket's published 2.16–2.92 mm insertion range. See the [SLW drawing](https://suddendocs.samtec.com/catalog_english/slw.pdf) and [TLW drawing](https://suddendocs.samtec.com/catalog_english/tlw_th.pdf).

The display's solder tails are modeled trimmed to 0.3 mm above its PCB, with a 0.5 mm solder envelope. A small open service well exposes that recessed contact row; it avoids a fragile roof directly over the joints. Local underside relief clears the display PCB. Decorative inlays retain their original backing requirement and stop where that backing is unavailable.

The [nice!view drawing](https://nicekeyboards.com/docs/nice-view/pinout-schematic/) places the contact row 1.3 mm from the end. The model now uses that datum, correcting the previous 2.4 mm misalignment with the socket.

**This is not a hardware-qualified connector substitution.** The finished nice!view hole diameter is not dimensioned in the available drawing. CAD retains its explicitly unmeasured 0.9 mm hole; the nominal 0.025-inch square post has a 0.898 mm diagonal, leaving no useful tolerance allowance. Measure actual hole and pin tolerances before choosing this pair. Do not enlarge or drill a purchased display based on this model. The stock 7 mm connector pair belongs to the previous taller stack.

13.39 mm was the initial Level prototype target, not a claim of an absolute physical minimum. Further reductions require a different qualified connector or module arrangement. Actual socket engagement, soldering, printed strength, battery insulation, cable flex and service forces still need a physical prototype. The [current PCBs are routed](electronics.md); this geometry is still not a physically qualified build kit.

[Level geometry delivery](../validation/revI-level-delivery.json) is a historical receipt for the floor/Level installation. Its hashes identify that historical snapshot; the R4 adjustment supersedes its native and derived files. [Cap direction checks](../validation/revI-cap-rows.json) cover the subsequent orientation fix. [Earlier viewer reliability checks](../validation/revI-reliability.json) retain their original HTML hashes; the [approved-frame delivery](../validation/revI-approved-frames.json) binds the current viewer. Openings preserve cap travel, so parts of the switches can still be visible from above between keys; the Level perimeter conceals their bodies from the sides.

## Reproduce

Start from the preserved pre-level source at commit `9ab4b181f77d0f3ffc28bda0cb3c059006713c89`. Export that file into an ignored build directory, then run:

```sh
python3 tools/freecad/run_macos.py tools/freecad/install_level_stack.py \
  --source build/level-case/source/Flan36.FCStd \
  --output build/level-case/candidate/Flan36.FCStd
python3 tools/freecad/run_macos.py tools/freecad/check_level_stack.py \
  --source build/level-case/candidate/Flan36.FCStd \
  --output build/level-case/candidate/geometry-check.json
```

Use a new output directory. The installer preserves the input and checks native save/reopen, unchanged key meshes and transforms, and idempotence. A saved candidate alone is not acceptance. The delivery receipt records the subsequent collision, travel, service, export and viewer checks.

Follow the [CAD export and viewer commands](cad.md#rebuild-the-reference) after adopting an accepted candidate. Run `node viewer/level-check.cjs` before `python tools/check_print_kit.py` to include the Level shell kit alongside the nine existing kit checks. `python tools/check_level_delivery.py` reproduces the historical Level delivery binding only at that snapshot; newer viewer changes require their own scoped receipt. Use `node viewer/reliability-check.cjs` for the current viewer state transitions. After publication, `python tools/check_public_delivery.py COMMIT` checks the anonymous source archive and live viewer against that exact commit.

`build/level-case/` holds ignored, reproducible candidates, diagnostic logs and browser test output. The committed installer/checkers above recreate the delivery artifacts; the installation and review receipts preserve the decisions and superseded candidate findings.

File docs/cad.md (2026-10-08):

# Editable CAD and 3D files

**[Editing guide](freecad.md)** · **[3D configurator](https://eduarbo.github.io/flan36/)** · **[Configuration format and examples](customize.md)**

The current mechanical source is [`mechanical/revI/Flan36.FCStd`](../mechanical/revI/Flan36.FCStd). It contains both halves, native sketches/operations, editable parameters and 36 original KLP meshes. Commercial modules use [nominal component models](../components/README.md); some connectors remain dimensional reserves. The matching revI KiCad studies use the chosen contour and internal battery/magnet clearances. The specified auxiliary/mounting footprints move, J1 uses a 2 mm side-entry PH footprint, and SW2 moves to the underside; all key transforms and nets are preserved.

| Nominal measure | Revision I |
|---|---:|
| Frame and Level shell height | 13.59 mm, including flush decoration |
| Display glass | 13.39 mm; recessed 0.20 mm |
| Display opening | 13.90 × 30.50 mm; 0.10 mm nominal glass clearance |
| Battery underside / case floor top | 1.4 mm |
| Selected flat KLP keycap top | About 17.87 mm, unchanged |
| Key plate top | 7.6 mm |
| Electronics bay | 24 mm |
| Case width × depth, each half | 116.75 × 94.57 mm |
| Case control corners / radius | 21 / locally bounded tangent arcs |
| Exposed finger switch-to-rim margin | 4.75 mm |
| Battery aperture | 12.5 × 34.4 mm plus local rear lead notch |
| North overhang past adjacent cap | 0 mm nominal |

The frame is **1.21 mm lower** than the previous 14.8 mm design; this does not reduce the selected keycaps' overall height. The [Samtec display connection](level-stack.md#what-makes-the-lower-display-possible) remains a dimensional candidate with unmeasured nice!view hole tolerances. Heights exclude the illustrative 1.2 mm feet. USB is only 0.045 mm behind the adjacent keycap’s north edge: this is a nominal alignment, not a physical tolerance guarantee.

The local H3 support relief provides **0.25 mm nominal K30 socket clearance** on both halves while preserving the outer contour, floor and stack height. Remaining pilot material measures **1.336 mm left / 1.248 mm right**. [Saved/reopened geometry evidence](../validation/revI-socket-clearance.json); physical fit remains unqualified.

## Files

- `mechanical/revI/Flan36.FCStd`: editable assembly.
- `mechanical/revI/*-case-{solid,rim,terrace,level}-{base,plate}.{step,stl}`: [four real case variants](cases.md).
- `mechanical/revI/*-assembly.step`: installed solid parts per half; no KLP mesh bodies.
- `mechanical/revI/*-frame-{talavera,gameboy,snes,phone,ipod,hanafuda}.{step,stl}`: the six selected cover styles. Retired native exports remain historical evidence and are excluded from the current configurator and print kits.
- `mechanical/revI/*-frame-*-{body,detail,accent,secondary}.{step,stl}`: registered flush color volumes.
- `mechanical/revI/*.step`, `*.stl`: individual prototype parts and identified envelopes.
- `mechanical/revI/*-battery-{adafruit-1570,301230}.stl`: selectable nominal cell envelopes.
- `mechanical/revI/coupon-*.{step,stl}`: actual magnetic/thread interface samples.
- `keycaps/variants/`: all 38 unchanged Choc-stem KLP files, including unqualified study variants.
- `keycaps/catalog.json`: provenance, actual stem axes, convex envelopes and qualification.
- `design/configurations/`: default and two sculpted preset examples.
- `hardware/revI/`: two routed KiCad projects, matching schematics, local libraries and models.
- `docs/images/revI-*.png`: renders calculated from exported meshes.
- Viewer: lighter online page, complete self-contained offline HTML, active-configuration GLB and JSON downloads. See the [viewer guide](viewer.md).

Parts retain assembly coordinates. Screw envelopes and nominal engagement are modeled; physical fits, printing orientation and final slicing settings are not qualified. Historical revE/revF/revG/revH sources and receipts remain available for comparison. To rebuild an older viewer, use its historical Git commit; the current shared viewer code targets revI.

## Rebuild the reference

For the isolated migration from the preserved source, use the [floor/level reproduction commands](level-stack.md#reproduce). This keeps manual edits and the published source intact.

For the current parametric repairs, component registration, local H3 socket relief and approved Hanafuda integration, use the [October correction recipe](reviews/2026-10-07-corrections.md#reproduce). Its staged installer chain preserves the baseline and validates the final `clearance/` candidate before adoption. All six current designs are selected; historical proposals remain provenance.

To refresh exports from the saved reference without rebuilding or overwriting its FCStd, run `python3 tools/freecad/run_macos.py tools/freecad/export_revI.py`, then rebuild the renders and viewer below. The exporter records current provenance separately from the preserved historical export record.

These commands overwrite generated revI reference files. **Do not run them over a source you edited by hand.** Use a separate checkout for reconstruction and keep custom FCStd files elsewhere.

Tested tooling: FreeCAD 1.1.3, KiCad 10.0.6, StepUp 13.1.7 (package metadata 11.09.6), Python with `tools/requirements-render.txt`, and Node dependencies fixed in `viewer/package-lock.json`.

```sh
python -m pip install -r tools/requirements-render.txt
npm ci --prefix viewer
python3 tools/freecad/run_macos.py tools/freecad/export_revI.py
python3 tools/freecad/run_macos.py tools/freecad/export_hotswap_visual.py --directory mechanical/revI
python3 tools/freecad/run_macos.py tools/freecad/check_audit_repairs.py \
  --source mechanical/revI/Flan36.FCStd --report build/current-parameters/result.json
python3 tools/freecad/run_macos.py tools/freecad/check_revI.py
python tools/render_revI.py
python tools/render_frames.py
python tools/build_viewer_revI.py
node viewer/build.mjs
node viewer/config-contract-check.cjs
node viewer/finishes-check.cjs
node viewer/flush-print-check.cjs
node viewer/frame-collection-check.cjs
node viewer/reliability-check.cjs
```

Browser checks need Playwright and its Chromium runtime; set `FLAN36_PLAYWRIGHT_MODULE` and `FLAN36_BROWSER` when using an existing installation. The resulting ignored `build/frame-collection/` files are reproducible with the commands above. Checks must pass and their recorded source hashes must match the generated artifacts. The active viewer is filtered by `design/frame-selection.json`; its frame check verifies six designs and twelve multipart assemblies. `tools/check_approved_3mf.py` and `tools/check_approved_frames.py` bind the earlier eleven-design delivery. Historical delivery scripts and receipts describe their pinned snapshots, not the current collection.

To reconstruct the pre-R4 PCB without replacing existing work, use `python3 tools/build_revI_pcb.py --output build/lcd-curve/hardware` with a new empty destination and compare its two PCB files. The source remains the immutable revH placement. The approved R4 J2 translation is a separate guarded migration in `tools/update_approved_display_pcb.py`; its receipt records the final coordinates.

For a fresh PCB reconstruction, run `python3 tools/build_revI_pcb.py` only when `hardware/revI/` does not exist. Run KiCad CLI DRC for both boards with JSON outputs at `build/revI/drc-left.json` and `drc-right.json`, then run `tools/check_revI_pcb.py` with KiCad Python on that historical unrouted reconstruction. Use `tools/check_routed_pcb.py` for the current routed boards. It checks the explicitly allowed footprint changes, preserved keys/nets and exact new outline, and writes the actual pad polygons. Then run `python tools/check_revI_outline.py` to measure every pad-to-edge clearance. Run these PCB checks before the final delivery check.

The macOS helper uses an existing FreeCAD installation. It disables optional `flatmesh` only in its subprocess because that installed extension crashes on import; it does not modify application preferences. The helper defaults to offscreen Qt. Current checks use offscreen GUI support to preserve native appearance without showing a window. On other systems, run the scripts through the equivalent installed FreeCAD Python environment.

After an authorized publication, `python3 tools/check_public_delivery.py COMMIT_SHA` checks an anonymous full source ZIP against every Git blob and compares public Pages with that commit. Its ZIP and receipt are reproducible under `build/revI/`; it does not publish anything.

The current parameter check inspects twelve approved frame assemblies at reference, moved-display, expanded-window, raised-roof and combined settings, including save/reopen and unsupported-edit rejection. The exporter also checks retained historical frame bodies. The earlier height and service studies retain their historical scope. The R4 readback checks the translated contacts, PCB drills and guides; the exporter checks nominal assembled collisions and cap travel. Neither study qualifies a physical assembly. `build/corner-stack/` contains ignored regenerable logs and staging for these commands.

The browser check needs Playwright and a Chromium-compatible browser. Set `FLAN36_PLAYWRIGHT_MODULE` and `FLAN36_BROWSER` if they are not on the usual path. It tests the generated file with HTTP(S) requests blocked; `FLAN36_VIEWER_URL` instead selects the published URL.

The native configuration test also uses the scoped subprocess exit after its assertions, file writes and save/reopen readback to avoid the same Qt teardown crash. It does not suppress failed assertions or change installed FreeCAD.

The catalog build verifies SHA-256 and Git blob hashes of every pinned upstream STL. The geometry exporter checks closed printable solids, pair intersections, all four case pairs, both cell variants and the six active cover variants and retained historical covers against components and a nominal USB plug corridor. The case checker measures the actual saved solids at the side bands, floor and raised-rim joint. The separate keycap checker includes complete-configuration envelopes and a travel/plate bound. The service checker samples frame lift, checks closed insert capture, cage capture and the cell-motion bound against lead paths. These tests do not measure force or print tolerances. Source hashes and results are under `validation/revI-*`.

`build/` is ignored and reproducible: native save/reopen trials come from `check_revI.py`; screenshots, test GLB/JSON and UI receipts from `viewer/check.cjs`; the viewer scene from `build_viewer_revI.py`. Source generations should be compared geometrically because STEP/FCStd metadata may vary. DRC JSON and pad polygons regenerate with the PCB checks above; service coupons regenerate with `check_revI_service.py`. The rim checker rejects the retained former contour, measures 216 preserved finger/outer-thumb normal samples, verifies native local tangent arcs and LCD-aligned flanks in the actual plate solids, and compares mirrored tray/plate volumes. `tools/check_revI_fasteners.py` clips actual KLP triangles to each screw-height travel slab for all 756 qualified reference choices. `build/case-variants/`, `build/lcd-curve/` and `build/uniform-contour/` contain reproducible logs/staging from these commands; review decisions are retained in the public receipt. The disposable contour study and reference copy in `build/case-variants/` are removed after acceptance; case screenshots and selected JSON/GLB regenerate with `viewer/check.cjs`. `viewer/performance.cjs` regenerates the current interaction timing receipt under `build/viewer-sidebar/`; `viewer/finishes-check.cjs` checks triangle/material identity. The native finish checker saves its current readback under `build/viewer-multicolor/freecad.json`. On macOS offscreen Qt, it verifies native face colors and save/reopen without calling OpenGL screenshot capture; the receipt marks that capture as unavailable. VTK renders and browser material checks provide separate visual QA.

## PCB exchange

The relative STEP references in `hardware/revI/models/` use the current nominal nano, display, connector, power/reset switch, Choc switch, diode and hot-swap socket geometry. The original 11 models retain their export/reimport check; the added 36 diodes and 36 sockets have separate actual KiCad STEP registration checks in the [audit evidence](reviews/2026-10-07-corrections.md#evidence). The bottom reset uses an explicitly flipped component transform, verified against actual KiCad CLI assembly exports. [Bottom-side registration](../validation/revI-bottom-reset-step.json) · [Model readback](../validation/revI-pcb-component-models.json).

RevI updates the board contour, battery opening and magnetic-station cutouts. `tools/build_revI_pcb.py` copies the historical unrouted source and refuses to overwrite existing work. Readback permits the specified H1/H3/H4/H5, J1, SW1 and SW2 changes, including the explicit PH pad geometry and bottom reset flip. It checks preserved nets, UUIDs, relative model references and all 36 locked keys. The verified StepUp procedure and coordinate alignment are described in [the editing guide](freecad.md#3-inspect-the-pcb-with-stepup). To rerun the historical exchange test on temporary copies:

```sh
python3 tools/freecad/run_macos.py tools/freecad/check_stepup.py
```

Then run `tools/check_stepup_readback.py` with KiCad’s Python. The StepUp harness exits its own GUI subprocess after saving because that runtime crashes during Qt teardown; independent KiCad readback is required. The test must change only the example opening edge, without altering key positions, pads, connectivity or the outer contour.

`tools/sync_pcb_study.py` resets reference placement; it is not an automatic synchronizer for hand-edited designs. Never use it to discard routing. The current routed-board receipt is [revI-routing.json](../validation/revI-routing.json). The pre-routing contour receipt remains historical [revI-electrical.json](../validation/revI-electrical.json); the full schematic/netlist validation is retained as historical [revF-electrical.json](../validation/revF-electrical.json).

## Remaining hardware work

The routed boards pass the configured 0.5 mm copper-to-edge rule. Both have **zero DRC/ERC/parity violations and zero unconnected items**. The [prototype fabrication guide](electronics.md) explains the per-half GPIO map and remaining hardware acceptance.

Exact cable terminals, sockets/contact lengths, magnetic retention, printed fits, keycap insertion, screw access with real tools, RF, charging and consumption still need verification. [Revision review](revI-review.md).

The historical `tools/check_rebrand.py` command applies only to its identity-only snapshot. The September 23 identity migration preserves the original geometry. Native metadata and current filenames use Flan36; previous generation receipts keep their original source hashes. [Rename checks](../validation/rebrand-file-map.json) bind the previous snapshot to the current files.

## Color and frame update checks

The isolated [floor/Level installer](level-stack.md#reproduce) preserves its source and verifies the permitted changes before adoption. The color and print checks run after rebuilding the viewer:

```sh
node viewer/keycolors-check.cjs
node viewer/capture-customization.cjs
node viewer/customize-check.cjs
node viewer/hex-check.cjs
node viewer/finishes-check.cjs
node viewer/battery-leads-check.cjs
node viewer/flush-print-check.cjs
node viewer/performance.cjs --smoke
python3 tools/freecad/run_macos.py tools/freecad/check_keycolors.py
python3 tools/freecad/run_macos.py tools/freecad/export_hotswap_visual.py --directory mechanical/revI
python3 tools/freecad/run_macos.py tools/freecad/check_audit_repairs.py \
  --source mechanical/revI/Flan36.FCStd --report build/current-parameters/result.json
python3 tools/freecad/run_macos.py tools/freecad/check_revI.py
```

`build/keycolors/` and `build/themes-print/` are ignored, reproducible test outputs: JSON/GLB downloads, palette collections, print ZIPs, screenshots and a native save/reopen copy. Native frame comparisons are included in `install_level_stack.py`; the earlier slim/flush installer and raised-frame sources are historical. The [mount study](slim-mount-study.md) produces separately named experimental geometry and a measured report under `build/`.

The [approved R4 frame implementation](frames-extra.md) supersedes the 13.39 mm shared-roof snapshot. The [slim/flush delivery receipt](../validation/revI-slim-flush.json) records the previous 14.8 mm stack and its nine print kits. It does not establish acceptance of the current 13.59 mm R4 update; use the current installation, geometry and export/viewer readbacks in the [approved-frame guide](frames-extra.md). The older `check_frame_collection.py`, `check_level_stack.py` and `check_print_kit.py` describe their historical geometries and palettes. Previous [customization](../validation/revI-customization.json) and [Label-only identity](../validation/revI-document-label.json) receipts retain their historical hashes. These digital checks do not qualify the keyboard for manufacturing.

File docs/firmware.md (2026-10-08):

# Firmware

Flan36 uses **ZMK v0.3.0**, pinned to `edf5c0814fd3ea202e43aad2d68fd32e882a518c`, on genuine **nice!nano v2** controllers with the standard UF2 bootloader. These files have been compiled and checked against the electrical matrix; flashing, radio operation and power use still need hardware tests.

| Download | Role | Display |
|---|---|---|
| [Left UF2](../firmware/uf2/flan36-left.uf2) | Central: connects to the computer | nice!view |
| [Right UF2](../firmware/uf2/flan36-right.uf2) | Peripheral: connects to the left half | nice!view |
| [Right UF2 without display](../firmware/uf2/flan36-right-no-display.uf2) | Peripheral, optional single-screen build | None |

Use one right-hand file. Both right variants use the same PCB pinout. USB on the right supports charging and bootloader access; the left half provides the keyboard's USB connection to the computer.

## Keymap

The [editable keymap](../firmware/config/flan36.keymap) has four layers. The physical order is left-to-right across the complete keyboard, including the six thumb keys. F and J correspond to the homing caps in the CAD.

- **Base:** QWERTY; left thumbs Ctrl/Esc, Numbers, Shift/Space; right thumbs Shift/Enter, Symbols, GUI/Backspace. Slash-separated keys tap the second function and hold the first.
- **Numbers:** digits, navigation, F1–F10.
- **Symbols:** punctuation, Alt/Delete, F11/F12 and volume.
- **Settings:** hold Symbols, then the Numbers thumb. Top row selects Bluetooth profiles 1–5, clears the active profile, selects BLE or USB, enters bootloader, or resets.

Sleep starts after 15 minutes; idle begins after 30 seconds. The scan matrix uses interrupts and supports waking by keypress. RGB, backlight and USB logging are disabled. Each display uses ZMK's official nice!view driver and status widget. The right display reports its local peripheral status; the left is not configured to proxy the right battery level.

## Wiring contract

| Function | Pro Micro labels | nRF52840 pins |
|---|---|---|
| Left rows 0–3 | D2, D3, D4, D5 | P0.17, P0.20, P0.22, P0.24 |
| Right rows 0–3 | D21, D20, D19, D18 | P0.31, P0.29, P0.02, P1.15 |
| Left column 0 / right column 0 | D6 / D15 | P1.00 / P1.13 |
| Both columns 1–5 | D7, D8, D9, D10, D16 | P0.11, P1.04, P1.06, P0.09, P0.10 |
| Display MOSI / SCK / CS | D1 / D0 / D14 | P0.06 / P0.08 / P1.11 |

The matrix has 18 populated positions per half. Electrical column 0 holds one thumb; it is not a sixth physical finger column. Diode cathodes connect to rows (`col2row`). The halves use different MCU pins to route around the battery opening without changing the case. The right transform reverses the visual key order. The [per-half pin map](../design/pinmap.json) is checked against both compiled firmware and PCB pads.

Flan36 defines its own `nice_view_spi`; **do not add `nice_view_adapter`**, whose default pins conflict with this matrix. Display CS is active high. UART and competing I²C/SPI controllers are disabled. The standard nice!nano bootloader configures the two NFC-capable pins used by columns 4/5 as GPIO; a clone or different bootloader must establish that independently.

## Build locally

The verified environment uses west 1.5, CMake, Ninja, Python build dependencies and the existing macOS GCC ARM 15.2.0 toolchain. The builder requires the compiler SHA-256 `7528680ad6078c1d2dd67a414fca656e5d78e56e7bc31f422a849bb15a7db04a`; another platform/compiler needs separate qualification. [west-frozen.yml](../firmware/west-frozen.yml) fixes all dependency revisions. Binary identity across different paths or machines is not promised.

The build expects the ZMK checkout **at the workspace root**, with its `app/` and the dependency `zephyr/` beside it. For a new, empty workspace, use this layout:

```sh
export FLAN36_REPO=/absolute/path/to/flan36
export FLAN36_ZMK_WORKSPACE=/absolute/path/to/new-zmk-workspace
git clone --no-checkout https://github.com/zmkfirmware/zmk.git "$FLAN36_ZMK_WORKSPACE"
git -C "$FLAN36_ZMK_WORKSPACE" checkout --detach edf5c0814fd3ea202e43aad2d68fd32e882a518c
west init -l "$FLAN36_ZMK_WORKSPACE/app"
cd "$FLAN36_ZMK_WORKSPACE"
west config manifest.file "$FLAN36_REPO/firmware/west-frozen.yml"
west manifest --validate
west update
west zephyr-export
cd "$FLAN36_REPO"
```

The external frozen-manifest selection and resolved paths were checked with west 1.5; builds reused an existing clean pinned workspace. The three binaries were rebuilt there with all 39 active dependency repositories checked. The conventional config-repository manifest in `firmware/config/west.yml` uses a different directory layout; it is not the initialization recipe for this builder.

```sh
export FLAN36_ZMK_WORKSPACE=/absolute/path/to/west-workspace
export CROSS_COMPILE=/absolute/path/to/arm-none-eabi-
# Activate the Python environment with west and Ninja on PATH.
# Optional: FLAN36_WEST=/absolute/path/to/venv/bin/west
sh tools/build_firmware.sh
python3 tools/check_firmware.py --zephyr "$FLAN36_ZMK_WORKSPACE/zephyr" --publish
```

The script expects the pinned ZMK checkout at `app/` and Zephyr at `zephyr/`, both clean. All active dependencies must match the pinned list and be clean. This version uses target `nice_nano_v2`; newer ZMK targets differ. The checker reads the actual compiled devicetrees, all 36 mappings, GPIO assignments, roles, sleep settings and every UF2 block. Before and after each build, the script records and compares sources, dependencies and compiler inputs. The checker requires that build-time attestation and verifies every output hash before copying any file. It records [source and binary hashes](../validation/revI-firmware.json).

`python3 tools/test_firmware_binding.py --zephyr "$FLAN36_ZMK_WORKSPACE/zephyr"` checks, in an isolated copy, that a changed key binding or altered binary is rejected without changing published files. Build products in `build/firmware-*` regenerate with these commands. [Dependency notices](../firmware/NOTICE.md).

## First hardware test

1. Verify battery connector polarity and inspect the assembled PCB for shorts before applying power. Keep the nice!nano **BOOST jumper open**: the selected small cells must not use its 500 mA charge mode.
2. Connect a USB data cable, double-tap reset and copy the matching UF2 to the bootloader drive. Do each half separately.
3. Power both halves, select profile 1 and pair **Flan36** with the computer. Verify all 36 keys and layer/thumb functions, including simultaneous presses and releases.
4. Check both displays, reset recovery, BLE reconnection, sleep/wake and measured current with the final assembled case. Repeat wake testing with both displays installed.
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

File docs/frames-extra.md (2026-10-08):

# Frame collection

Choose **Frame** in the [3D explorer](https://eduarbo.github.io/flan36/) and click a preview. Each thumbnail uses the actual native material geometry. **Talavera** is the default; switching designs preserves the camera, colors and other selections.

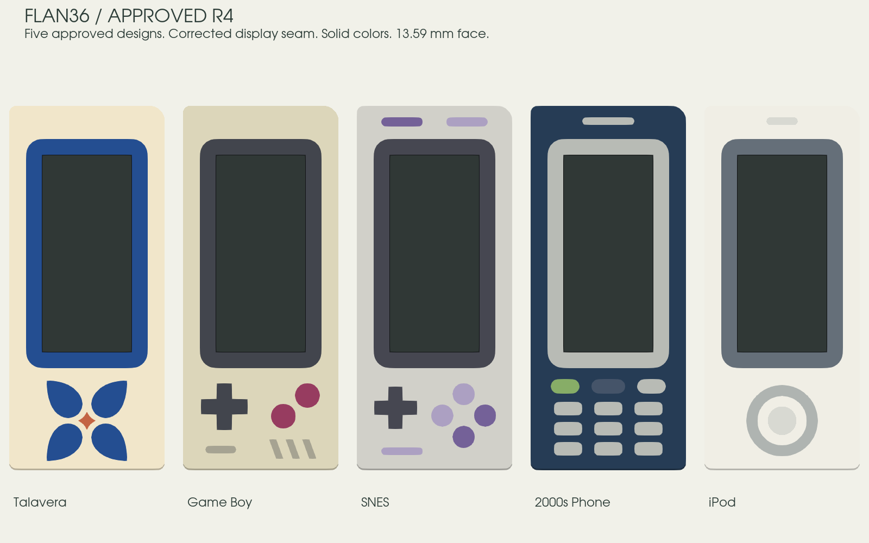
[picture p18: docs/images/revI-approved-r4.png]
Approved native frame designs rendered from native meshes

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

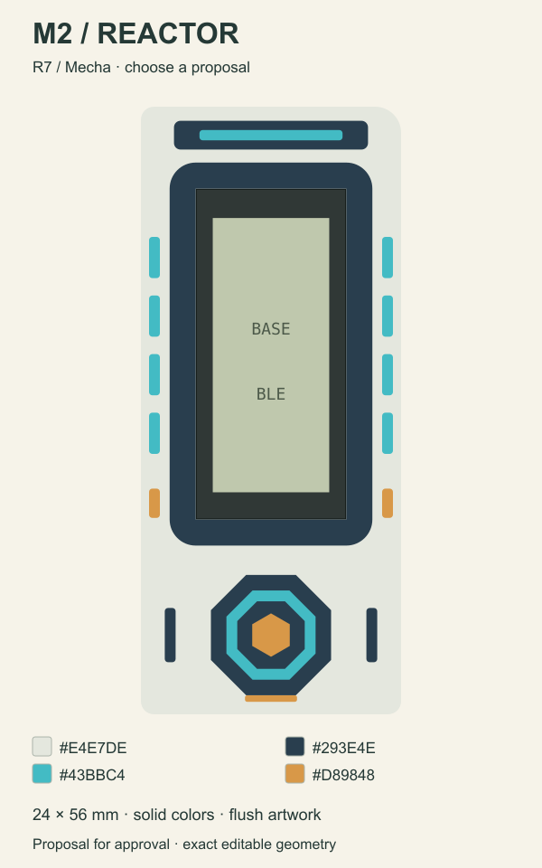
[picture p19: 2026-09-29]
docs/frame-proposals/r7/mecha-reactor-card.png

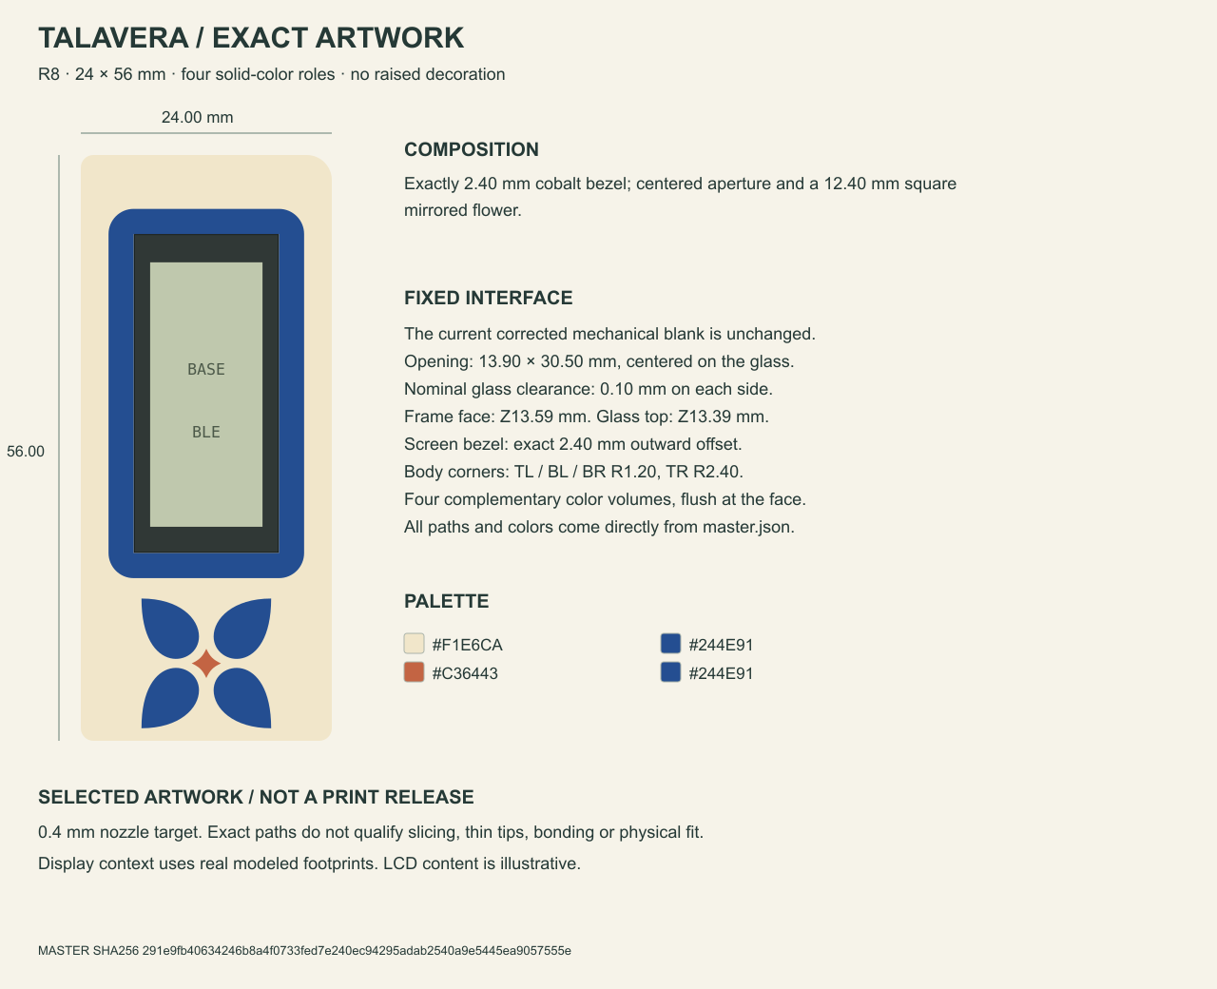
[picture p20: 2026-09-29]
docs/frame-proposals/r8/talavera-dimensioned.png

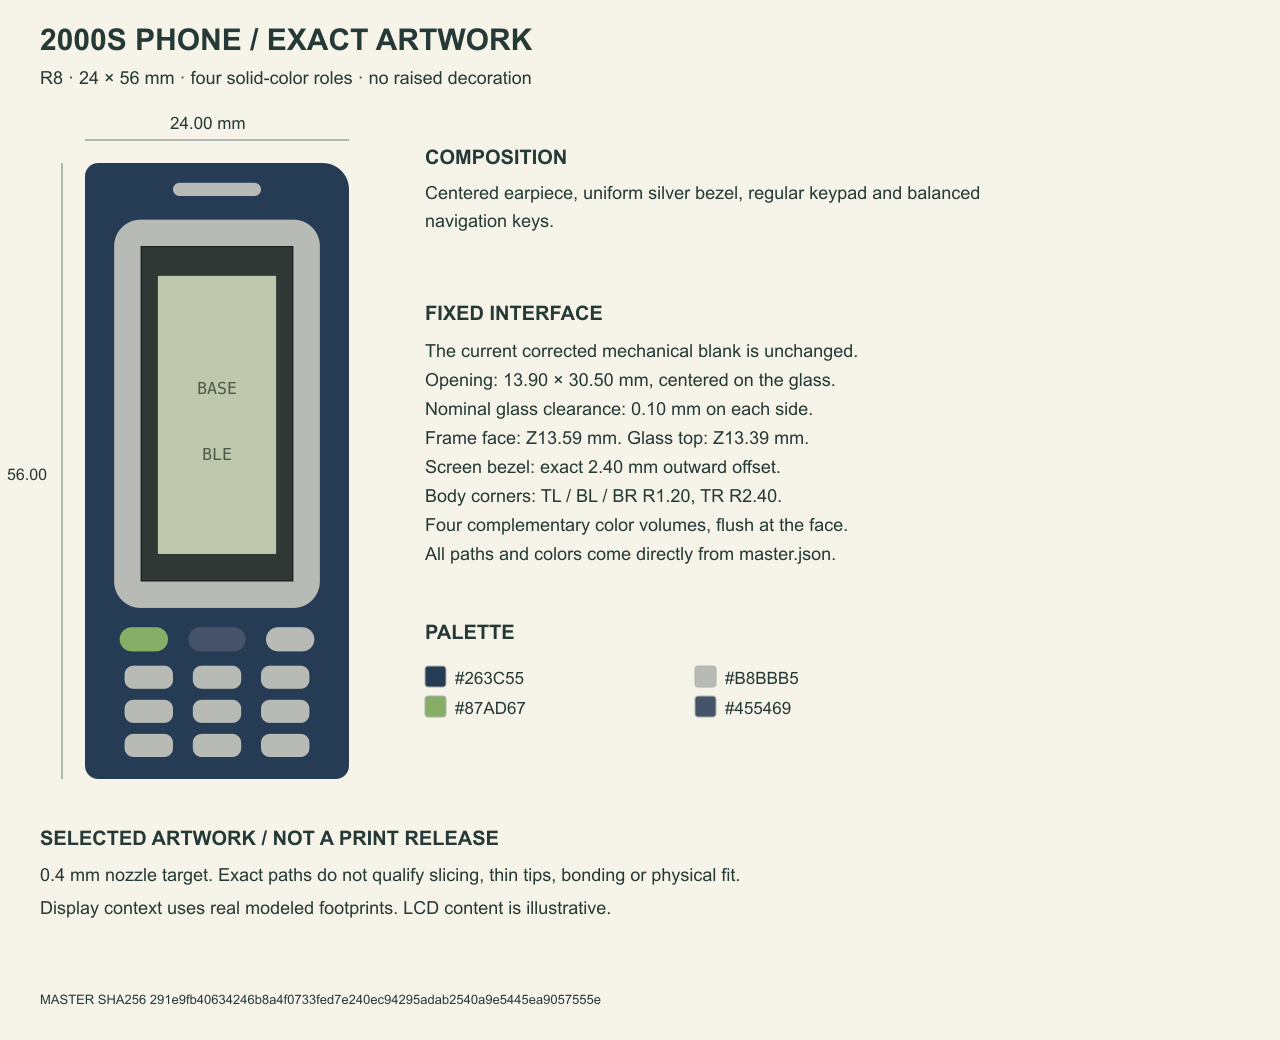
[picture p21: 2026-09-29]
docs/frame-proposals/r8/phone-dimensioned.png

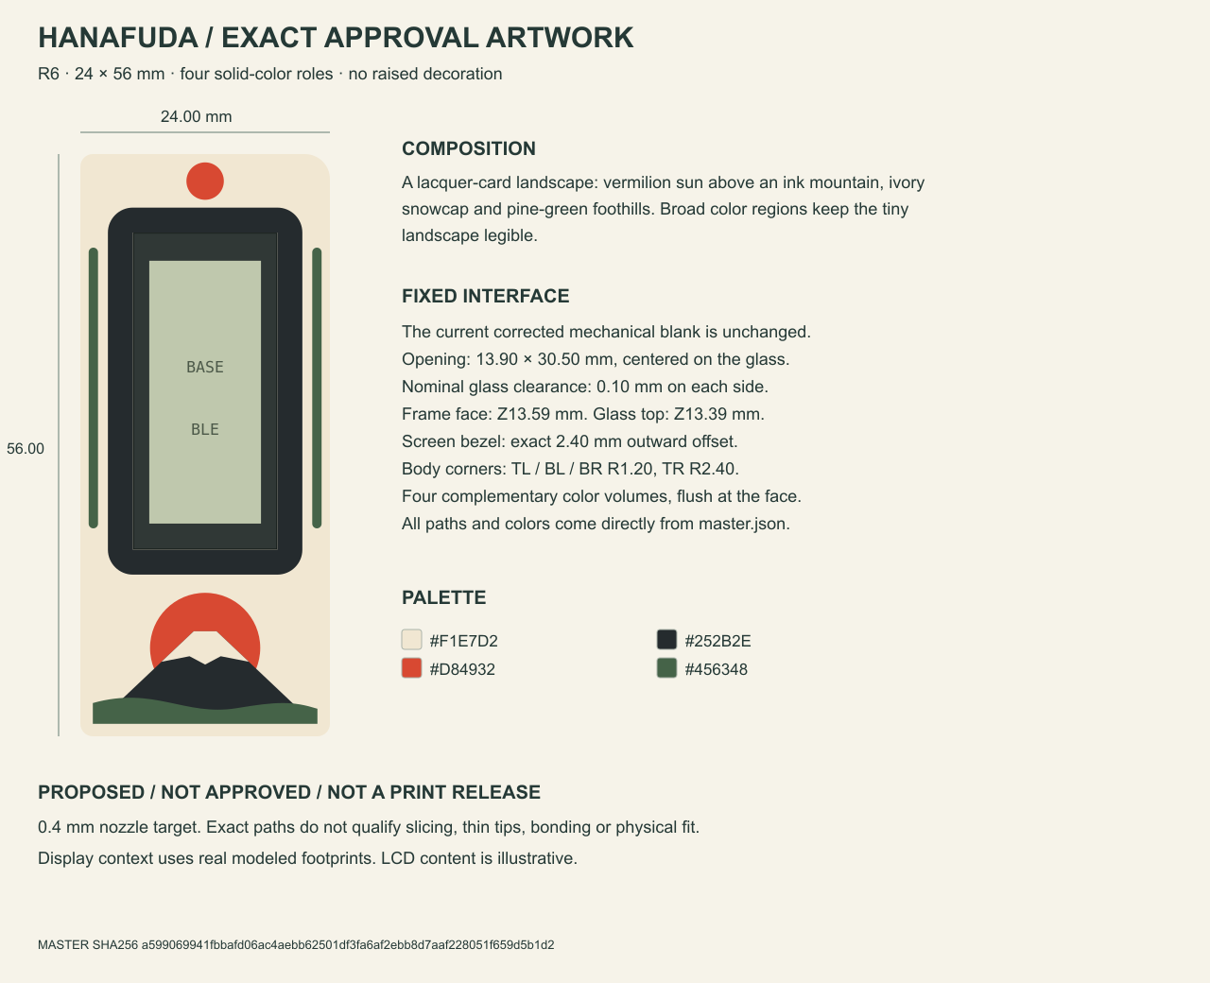
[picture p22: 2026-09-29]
docs/frame-proposals/orbit-dimensioned.png

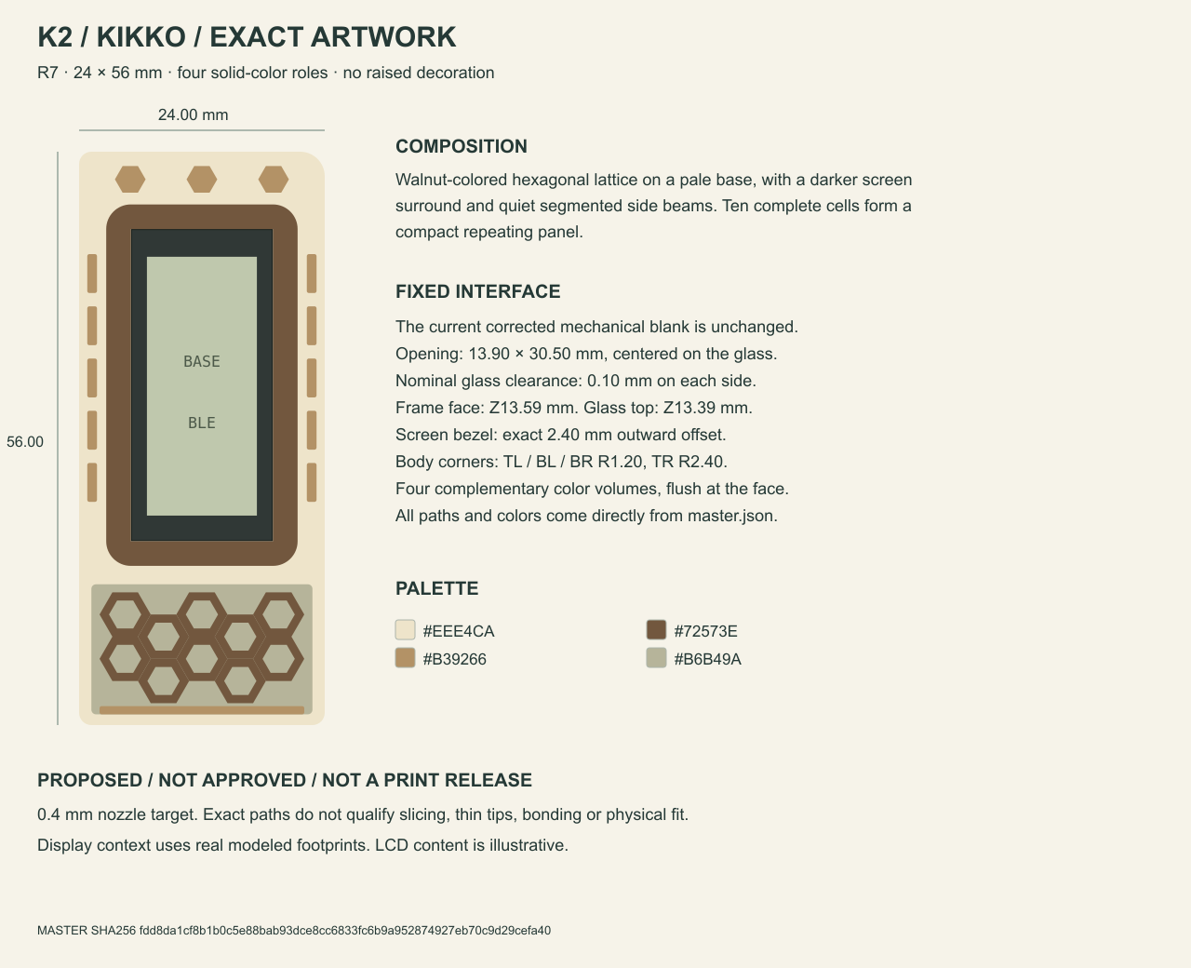
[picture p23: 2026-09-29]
docs/frame-proposals/r7/kumiko-kikko-dimensioned.png

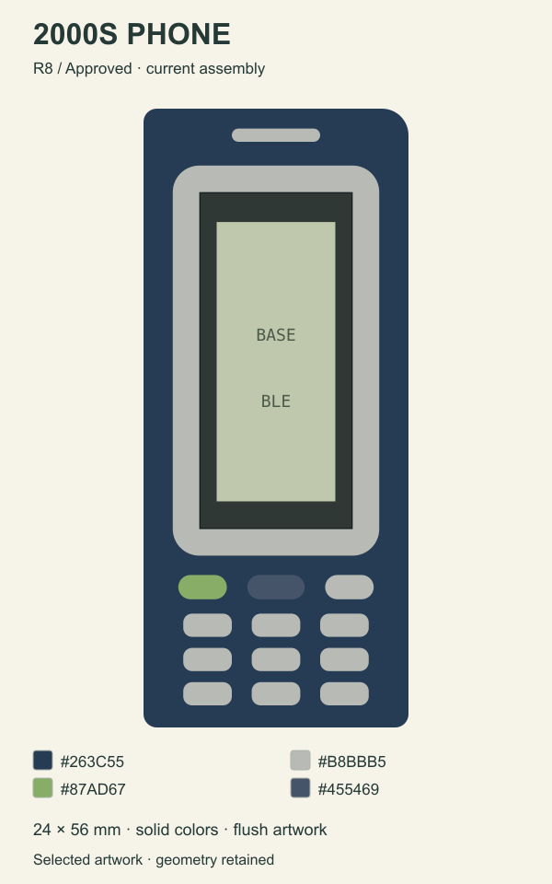
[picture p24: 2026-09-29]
docs/frame-proposals/r8/phone-card.png

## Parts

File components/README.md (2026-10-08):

# Component models

These models make the assembly easier to inspect. They are **nominal representations**, not a claim of measured fit or manufacturer CAD.

| Part | Geometry and appearance | Evidence / remaining limit |
| --- | --- | --- |
| nice!nano v2 | Black rounded PCB, ENIG contacts, mid-mount USB-C shell and tongue, separate ICs, crystals, passives and LEDs | Official identity, 3.2 mm overall thickness and mid-mount USB. PCB 17.78 × 33.1 mm and total length 34.624 mm use a community drawing. Individual package placement/heights are reconstructed from photographs. |
| nice!view | 14 × 36 × 2.9 mm stack, five contacts, glass and backing; 10.744 × 25.28 mm active image | Official module drawing and Sharp panel specification. Preserve the 14.2 × 36.2 mm V-cut reserve for fit. Glass/flex assembly positions remain nominal. |
| Choc v1 | KiSwitch housing, pins and moving stem; original geometry, recolored | Generic Choc v1 community CAD; not a measured Pro Red specimen. KLP insertion and travel are not physically verified. |
| 36 SOD-123 diodes | Pinned KiCad source geometry, 18 per underside at the actual footprint poses | Nominal package dimensions; solder thickness remains unmeasured. |
| PCM12 / TL3342 | KiCad STEP geometry and original face materials | Registered to the existing KiCad footprints. Library models, not toleranced manufacturer assemblies. |
| Choc hotswap socket | 36 pinned KiSwitch sockets, registered to the actual footprint bores and solder-contact planes | Nominal bottom Z1.95 mm, 0.55 mm above the floor. The relieved internal H3 support has a measured K30 gap of 0.2500001 mm on both halves; minimum material around its pilot is 1.336281 mm left / 1.247739 mm right. [Clearance evidence](../validation/revI-socket-clearance.json). Actual KiCad STEP registration and native collisions are checked. Purchased variant, solder thickness and physical fit remain unqualified. |
| Batteries, MCU sockets and leads | Nominal cell profiles, socket reserves and continuous lead routes | Finished pouch seams, contacts, solder, wire diameter, terminations and strain relief still require measurement. |
| JST PH connector | Dimensioned side-entry header and mated housing envelope | Original reconstruction from the public catalog; internal mating and supplied plug dimensions are unmeasured. |

The right half uses the **same** commercial nano/display geometry, translated into place. The power switch is rotated to its footprint. Neither module is mirrored.

FreeCAD, the web viewer and the revI KiCad relative STEP models share this nominal geometry. The STEP export is reimported and compared with the native solids at each existing footprint datum; relative model references are preserved. The slim update changes J1 and moves the reset to the underside; actual KiCad STEP exports verify the resulting registration. [Readback](../validation/revI-pcb-component-models.json).

The controller support has scalloped upper ledges. These keep clear of a 1.05 mm radius reserve around the underside pads. They do not establish solder tolerance or retention force.

The lowest modeled nice!view PCB sits 6.09 mm above the main PCB using a nominal Samtec SLW/TLW pair. The row follows the official 1.3 mm end offset. Commercial finished-hole/post fit, actual mating and solder tolerances remain unqualified. The stock 7 mm pair belongs to the preceding taller reference. [Stack dimensions and limits](../docs/level-stack.md).

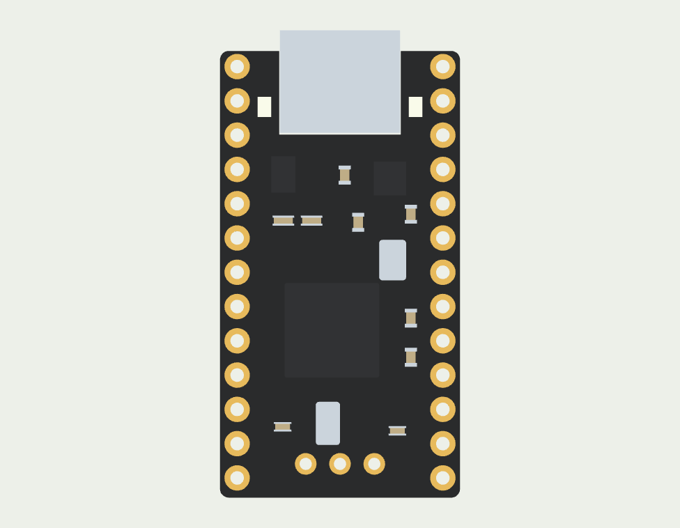
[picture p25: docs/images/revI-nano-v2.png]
Nominal nice!nano v2 reconstruction in the explorer


## Sources

- [nice!nano product specifications](https://nicekeyboards.com/nice-nano/) and [official v2 pinout, both faces](https://nicekeyboards.com/docs/nice-nano/pinout-schematic/).
- [Jordan Banasik / Woovie nominal v2 drawing](https://github.com/Woovie/nicenano-v2-model/tree/88099bcecdf2b60a0ec73131b132a182da03302b), CC0. Used as a dimensional reference; no recolored Pro Micro model is used.
- [nice!view mechanical drawing](https://nicekeyboards.com/docs/nice-view/pinout-schematic/) and [Sharp LS011B7DH03 catalogue](https://global.sharp/products/device/catalog/pdf/sharp_device202109_e.pdf).
- [KiSwitch source revision](https://github.com/kiswitch/kiswitch/tree/aefcf65038d48d2666ff14530d482be3c350fa6e), under its [MIT option](sources/KiSwitch-MIT.txt).
- [KiCad library license and exception](https://www.kicad.org/libraries/license/). Imported STEP files are CC-BY-SA-4.0 with the library exception. Original colors are preserved; only placement changes.

Exact asset URLs, hashes and licenses: [sources.json](sources.json). Official photographs are references, not images relicensed by this project. Parametric reconstruction: [components.py](../tools/freecad/components.py).

### PH battery connector

The slim stack uses an original nominal reconstruction of a **JST S2B-PH-K-S**
side-entry header and **PHR-2** housing. The public [JST PH catalog](https://www.jst-mfg.com/product/pdf/eng/ePH.pdf)
gives the side-entry mated assembly reserve as **9.6 mm long × 4.8 mm high**, with
2 mm pin pitch. The header body is 5.9 × 7.6 × 4.8 mm and the housing is
5.8 × 6.85 × 4.5 mm. Internal engagement, wire-port positions, plastic tolerances
and the purchased battery polarity remain unmeasured. No downloaded JST CAD is
redistributed. See `tools/freecad/slim_stack.py` and the bundled original footprint.

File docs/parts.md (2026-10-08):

# Parts and buying guide

**One complete 36-key split. Quantities cover both halves.**

This is a planning BOM for the revI mechanical study and PCB outline. **It is not a verified build kit:** the PCBs are routed and digitally checked, but exact connectors, magnetic retention and printed threads still need physical tests. Store links identify actual products; they do not certify interchangeability.

[Custom PCBs](electronics.md) · [Typeractive shopping list](#typeractive-shopping-list) · [Controllers](#controllers) · [Displays](#displays) · [Switches](#switches-and-hot-swap) · [Battery](#battery) · [Connectors](#removable-connectors) · [Small parts](#small-electrical-parts) · [Printed parts](#printed-parts)

**Custom PCBs: 1 left + 1 right**, two layers, 1.6 mm FR4, nominal 1 oz copper. Use the [matched prototype fabrication packages](electronics.md), after checking the exact connector and battery fit. The supplied pin maps differ between halves; neither board is interchangeable with Piantor or the historical placement studies.

## Typeractive shopping list

| Item | Quantity / store selection | Fit status |
|---|---|---|
| [nice!nano v2](https://typeractive.xyz/products/nice-nano) | **2 units** | Selected controller; final socket height pending |
| [nice!view](https://typeractive.xyz/products/nice-view) | **2 units**, or 1 for the fallback | Selected display; included connector does not establish stack fit |
| [Choc v1 switches](https://typeractive.xyz/products/choc-switches) | **4 packs of 10**; Pro Red baseline | 36 required, 4 spares |
| [Kailh hot-swap sockets](https://typeractive.xyz/products/hotswap-sockets) | **4 packs of 10; select Choc** | Do not select MX |
| [1N4148W SMD diodes](https://typeractive.xyz/products/smd-diodes) | **4 packs of 10** | SOD-123 family; verify supplied marking/footprint |
| [Machine sockets and pins](https://typeractive.xyz/products/machine-sockets-and-pins) | **2 kits** | Store uses Mill-Max **310**, study references **315**; substitution needs height/pin check |
| [EZ-Solder sockets/headers](https://typeractive.xyz/products/ez-machine-sockets-and-headers) | **2 kits**, instead of the preceding kits | Easier header handling; taller, not qualified in this stack |
| [5-pin sockets](https://typeractive.xyz/products/5-pin-sockets) | Optional **1 pack of 2** | Extras; nice!view includes sockets/pins. Stock alternative for the previous taller stack; the current prototype uses the Samtec candidate below |
| [110 mAh battery](https://typeractive.xyz/products/lithium-battery-110mah) | **2**, connector variant to resolve | Supported nominal envelope in the shared 12.5 mm aperture; physical pack fit pending |
| [Battery jack](https://typeractive.xyz/products/battery-jack) | **1 pack of 2** | JST S2B-PH-K-S side-entry reference; 2 mm nominal footprint |
| [Power switch](https://typeractive.xyz/products/power-switch) | **1 pack of 2** | Alps part differs from the C&K reference; footprint change/check required |
| [Reset button](https://typeractive.xyz/products/reset-button) | **1 pack of 2** | Panasonic part differs from the E-Switch reference; not a drop-in approval |

The selected Adafruit battery, custom PCB and printed parts are outside this store list. Prices, stock and shipping eligibility can change; check the selected variant and delivery destination at checkout. No purchases have been made.

## Controllers

<a href="https://typeractive.xyz/products/nice-nano">nice!nano v2.0 — supplier product photo</a>

**2 × nice!nano v2.** nRF52840 wireless controllers with USB-C and battery charging. They provide the intended BLE link between halves and to the host.

**Technical reference:** [v2 pinout and schematic](https://nicekeyboards.com/docs/nice-nano/pinout-schematic/). **Full documentation:** [nice!nano](https://nicekeyboards.com/docs/nice-nano/). **Buy:** [Typeractive](https://typeractive.xyz/products/nice-nano).

Alternatives: clones require independent pinout, charger and idle-current checks. XIAO or other controller formats require a PCB and mounting redesign. No alternative is approved as a direct replacement.

## Displays

<a href="https://typeractive.xyz/products/nice-view">nice!view — supplier product photo</a>

**2 × nice!view**, with a single left display as the fallback. Reflective memory LCD; selected for low power. Each cover leaves the glass visible and hides the surrounding electronics.

**Technical reference:** [dimensions, pinout and schematic](https://nicekeyboards.com/docs/nice-view/pinout-schematic/). **Full specifications/setup:** [nice!view documentation](https://nicekeyboards.com/docs/nice-view/). **Buy:** [Typeractive](https://typeractive.xyz/products/nice-view).

A separate board PDF datasheet is not linked by the manufacturer; its dimensioned drawings and schematic are the authoritative board references. OLED offers dark-room visibility at a power cost. E-paper needs a different mount and firmware. Neither fits this design as a drop-in alternative.

## Switches and hot-swap

<a href="https://typeractive.xyz/products/choc-switches">Kailh Choc v1 Low Profile Switches — supplier product photo</a>

**36 × Kailh Choc v1; 40 provides spares.** Pro Red 35 gf is the baseline; Pink 20 gf is lighter, Red 50 gf firmer, Brown tactile and White clicky. Silent Ambients are another Choc-family option to measure before adopting.

**Technical information:** [Kailh PG1350 family](https://www.kailhswitch.com/info/kailh-kl-switches-pg1350-series-23772219.html). **Variant specifications and purchase:** [Typeractive Choc v1](https://typeractive.xyz/products/choc-switches). **Silent alternative:** [LowproKB Ambients](https://lowprokb.ca/products/ambients-silent-choc-switches).

An exact Pro Red manufacturer PDF has not been verified here; the family page is not a substitute for a variant-specific drawing. Choc v2/MX-stem switches are outside this build.

<a href="https://typeractive.xyz/products/hotswap-sockets">Kailh Hotswap Sockets — supplier product photo</a>

**36 × Kailh CPG135001S30 Choc sockets; 40 provides spares.**

**Datasheet/drawing:** [Kailh CPG135001S30 PDF](https://www.kailhswitch.com/Content/upload/pdf/202115927/CPG135001S30-data-sheet.pdf). **Info and purchase:** [Typeractive — select Choc](https://typeractive.xyz/products/hotswap-sockets). The product photo includes both families; the **MX** variant is incompatible.

All 36 sockets are represented in the nominal assembly and registered to their PCB mounting bores and solder-contact planes. The case includes a local H3 support relief, measured at **0.25 mm nominal clearance** from thumb socket K30 on both halves. [Component geometry and clearance evidence](../components/README.md) do not qualify a purchased variant, solder thickness or printed fit.

## Battery

<a href="https://www.adafruit.com/product/1570">Adafruit 1570 battery — supplier product photo</a>

**CAD reference: 2 × Adafruit 1570, protected 1S LiPo, sold as 100 mAh.** The model uses the product page’s **11.5 × 31 × 3.8 mm** envelope; two continuous nominal 105 mm lead paths include cell-end bends and plug interfaces. Their 0.6 mm insulation diameter and terminal positions remain assumptions.

**Datasheet:** [supplier-linked PKCELL PDF](https://cdn-shop.adafruit.com/product-files/1570/1570datasheet.pdf). **Full information and purchase:** [Adafruit 1570](https://www.adafruit.com/product/1570). The linked PDF names a **401230 / 105 mAh** cell, while the listing says 100 mAh: confirm the actual supplied pack and its dimensions before closing the cradle. The product page limits charging to **100 mA or less**; the nice!nano charger configuration must respect the actual cell’s limit.

<a href="https://typeractive.xyz/products/lithium-battery-110mah">Lithium Battery 110mAh — supplier product photo</a>

**Typeractive alternative: 301230, 110 mAh, 3 × 12 × 30 mm.** [Product and connector variants](https://typeractive.xyz/products/lithium-battery-110mah). The black PH connector version has shorter leads; the white version includes a mating wired jack. No cell-specific datasheet is linked on the listing.

**Both profiles use the same case, PCB opening, open-bottom locator and cage.** The cell rests at **Z = 1.4 mm** on the case floor; there is no printed saddle beneath it. Select the battery in **Battery** in the sidebar in the viewer; configuration JSON and FreeCAD retain the choice per half.

| Profile | Nominal W × L × H | Aperture side gap | Gap below rigid cage roof |
|---|---|---:|---:|
| Adafruit 1570 | 11.5 × 31 × 3.8 mm | 0.50 mm per side | 0.40 mm |
| 301230 | 12 × 30 × 3 mm | 0.25 mm per side | 1.20 mm |

These are nominal clearances, not maximum finished-pack tolerances. Confirm protection-board wrapping, insulation at PCB edges, lead exit, connector polarity and charging limits on the delivered pack. The smaller pack can move within the cage; delivered-pack retention and lead strain still need a physical check. No autonomy estimate is promised.

## Removable connectors

<a href="https://typeractive.xyz/products/machine-sockets-and-pins">Machine Sockets and Pins — supplier product photo</a>

**Controller study reference:** 4 × 12-position Mill-Max **315-43-112-41-003000** strips and 48 compatible round pins, plus spares. [Manufacturer-authored datasheet, distributor mirror](https://static6.arrow.com/aropdfconversion/2e225be7d9212620894362dafa7ce735623fe9ca/315-43-112-41-003000.pdf).

**Store alternative:** [Typeractive machine sockets/pins](https://typeractive.xyz/products/machine-sockets-and-pins), **2 kits**, each for one controller. The listing specifies Mill-Max **310**; do not treat it as the modeled 315 part. [EZ-Solder](https://typeractive.xyz/products/ez-machine-sockets-and-headers) trades loose pins for headers and a slightly taller assembly. Exact mating height and pin selection remain open for both alternatives. Do not force square pins into turned sockets.

<a href="https://typeractive.xyz/products/5-pin-sockets">5-Pin Sockets — supplier product photo</a>

**Current low-stack display connector candidate:** 2 × Samtec **SLW-105-01-L-S** sockets and 2 × **TLW-105-06-G-S** headers. Their 4.57 + 1.52 mm bodies give a nominal **6.09 mm** board separation. Manufacturer drawings: [SLW](https://suddendocs.samtec.com/catalog_english/slw.pdf) and [TLW](https://suddendocs.samtec.com/catalog_english/tlw_th.pdf). This is a dimensional candidate, not a purchasable qualified BOM: stock was not checked, and the toleranced square post must be matched against measured nice!view holes. The display solder tails require trimming. [Exact assumptions and service well](level-stack.md).

**Stock alternative:** [Typeractive 5-pin sockets](https://typeractive.xyz/products/5-pin-sockets), included with nice!view and sold separately in pairs. Their stated 5 + 2 mm installed height belongs to the previous taller stack; they cannot simply replace the Samtec candidate inside the lowered frame.

[No-solder spring headers](https://typeractive.xyz/products/no-solder-spring-headers) require the supplier’s specified **0.8–0.9 mm holes** and different installed heights. They are not qualified for the current Flan36 hole/contact geometry. Do not buy them as an assumed shortcut.

## Small electrical parts

<a href="https://typeractive.xyz/products/smd-diodes">SMD Diodes — supplier product photo</a>

**36 × 1N4148W, SOD-123; four 10-packs give spares.** [Typeractive info/buy](https://typeractive.xyz/products/smd-diodes) · [Semtech datasheet](https://cdn.shopify.com/s/files/1/0618/5674/3655/files/Semtech-1N4148W.pdf?v=1670451309). Match package and cathode orientation to the final PCB.

<a href="https://typeractive.xyz/products/battery-jack">Battery Jack — supplier product photo</a>

**2 × battery jacks.** [Typeractive JST PH 2.0 mm](https://typeractive.xyz/products/battery-jack) · [JST S2B-PH-K drawing](https://cdn.shopify.com/s/files/1/0618/5674/3655/files/JST-S2B-PH-K.pdf?v=1670451309). The PCB study now uses a 2 mm side-entry footprint and the CAD uses a nominal mated header/PHR-2 envelope. Check the purchased pack's polarity and terminal dimensions before assembly.

<a href="https://typeractive.xyz/products/power-switch">Power Switch — supplier product photo</a>

**2 × power switches.** CAD/PCB reference: **C&K PCM12SMTR**, [manufacturer datasheet](https://www.ckswitches.com/media/1424/pcm.pdf). Typeractive sells **Alps SSSS811101**, [product information](https://typeractive.xyz/products/power-switch) · [Alps datasheet](https://cdn.shopify.com/s/files/1/0618/5674/3655/files/ALPS-SSSS811101.pdf?v=1670451309). The photo is the **Alps alternative**. Different part/footprint; not approved as interchangeable.

<a href="https://typeractive.xyz/products/reset-button">Reset Button — supplier product photo</a>

**2 × reset buttons.** Reference: **E-Switch TL3342F160QG**, [full product information](https://www.e-switch.com/product/tl3342-series-low-profile-smt-tactile-switch/) · [datasheet](https://configured-product-images.s3.amazonaws.com/2D/specs/TL3342F160QG.pdf). Typeractive sells **Panasonic EVQPUC02K**, [product information](https://typeractive.xyz/products/reset-button) · [Panasonic datasheet](https://cdn.shopify.com/s/files/1/0618/5674/3655/files/PANASONIC-EVQPUC02K.pdf?v=1670451309). The photo is the **Panasonic alternative**. The E-Switch reference is mounted below the PCB with recessed tool access through the case floor. Footprint, actuation height and underside clearance must be reviewed before substituting the Panasonic part.

## Printed parts

Flan36 revI case CAD and KLP Lamé reference assembly

| Part | Quantity | Files / options |
|---|---:|---|
| KLP Lamé keycaps | 36 | [Variant guide](customize.md); [38 source STLs](../keycaps/variants); original preset: 28 Normal + 2 Homing + 6 Thumb |
| Case bases and key plates / upper shells | 2 each | Level, Solid, Color rim or Terrace; [editable CAD, STEP and STL](cad.md) |
| Display frames | 2 | Six selectable approved designs; 13.59 mm shared roof, separate color per half |
| Battery locators and retainers | 2 each | Open-bottom locator and rigid cage; cell on the floor, cage feet captured under PCB |
| Controller supports and display sleds | 2 each | Independent from the cover |
| Printed spacers/washers | 6 | Check printed dimensions and screw fit |

**Technical source for keycaps:** [KLP Lamé files and print guidance](https://github.com/braindefender/KLP-Lame-Keycaps). No commercial datasheet applies to the custom printed parts; the FCStd and dimensioned parameters are their design source. PLA Basic, PETG HF and ABS are candidate materials, not validated print profiles. Start with a fit coupon and three caps.

## Fasteners, cable and tools

- **6 × M2 × 6 low-head screws:** nominal NBK SLH envelope, Ø3.8 × 1.3 mm head. [Drawing](https://static.nbk1560.com/images/en/product/lowsmallheadscrew/SLH-TZB/SLH-TZB_1.pdf). **4 × M2 × 4:** NBK SSH envelope, Ø4 × 1.1 mm head. [Drawing](https://static.nbk1560.com/images/en/product/lowsmallheadscrew/SSH/SSH_1.pdf). Tap the printed Ø1.7 mm pilots M2; engagement is 2.2–2.4 mm. Thread strength remains untested.
- **6 × Ø2 × 3 mm neodymium magnets:** S-02-03-N reference, N45. [Full product information](https://www.supermagnete.de/stabmagnete-neodym-rund/stabmagnet-2mm-3mm_S-02-03-N) · [Datasheet](https://www.supermagnete.fr/data_sheet_S-02-03-N.pdf). Three stay in each base. Test the capture process without exceeding the specified 80°C magnet temperature.
- **6 × Ø2 × 4 mm ferromagnetic steel pins:** three per frame. The exact supplier/grade is still open; nonmagnetic stainless is unsuitable. Every additional pair of frames needs six more pins; the base magnets stay in place.
- **8 adhesive rubber feet:** approximately 1–1.5 mm. Their height adds to the case.
- **Insulation and removable retention:** small quantity; avoid loading the battery pouch. The rigid cage and captive inserts are digitally modeled; printed retention is untested.
- **1–2 USB-C data cables:** charging and firmware transfer. [Typeractive’s silicone cable](https://typeractive.xyz/products/silicone-usb-c-cable) is listed for power; its page does not establish data support. Do not assume it can flash firmware. Check plug dimensions against the opening.
- Fine-tip soldering iron, solder, flux, tweezers, cutters and a multimeter. The printer makes mechanical parts; the custom PCB needs fabrication. [Routed prototype files and remaining checks](electronics.md).

## Sources and images

Original store links and pack quantities were checked on **2026-09-21**; battery specifications and magnetic hardware sources were revisited on **2026-09-22**. The current automated link check could not read the Arrow socket PDF (timeout) or the C&K PDF (403); those historical technical references remain listed, not freshly verified. Manufacturer/supplier documentation takes precedence over approximate CAD envelopes. Missing exact datasheets and unresolved substitutions are explicitly identified above.

Product photos are embedded from Typeractive/Adafruit and linked to their original listings. They remain the property of their respective owners; they are not relicensed under this repository’s license. They need internet access and are not bundled in the offline 3D viewer. Flan36 renders have separate [attribution](../ATTRIBUTION.md).

## What the component models represent

The explorer now distinguishes commercial model sources from fit reserves. See [component fidelity and dimensions](../components/README.md) for the nice!nano v2 reconstruction, nice!view drawing, licensed library models and the remaining connector/measurement gaps.

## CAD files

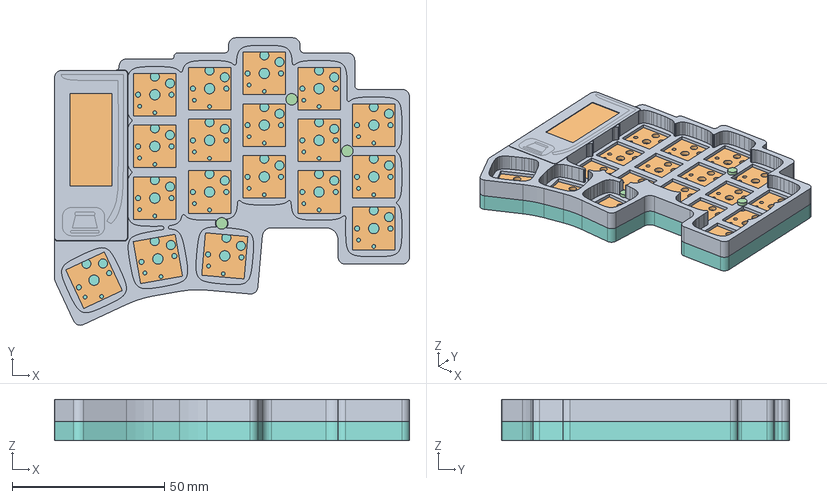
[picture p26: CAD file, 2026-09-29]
mechanical/revI/right-assembly.step
116.8 x 94.6 x 13.6 mm

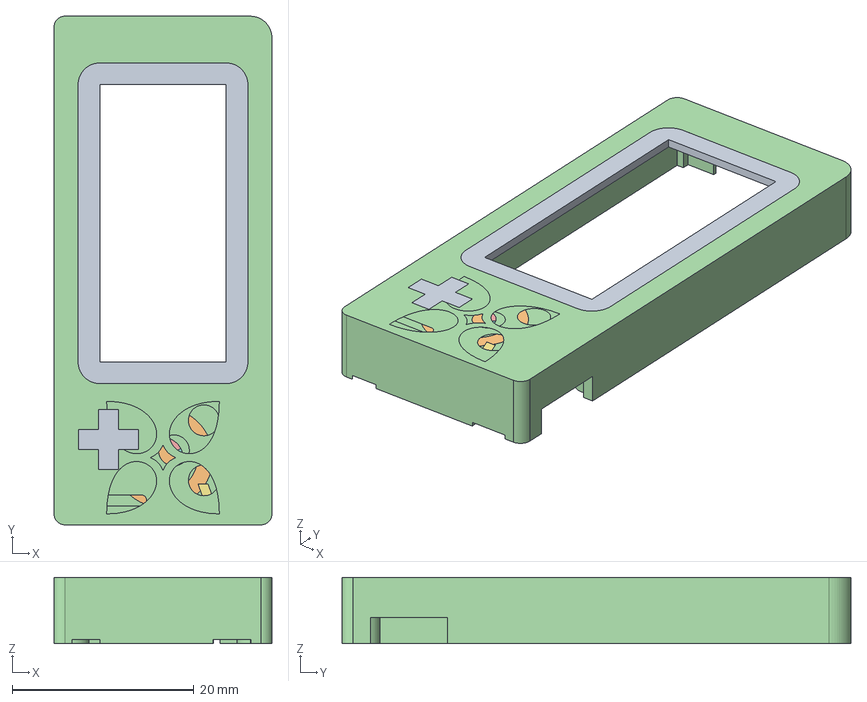
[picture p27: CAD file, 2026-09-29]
design/proposals/display-seam-r1/Seam-candidate.FCStd
24.0 x 56.0 x 7.29 mm
talavera_detail_ReviewSolid
talavera_accent_ReviewSolid
talavera_secondary_ReviewSolid
talavera_body_ReviewSolid
gameboy_detail_ReviewSolid
gameboy_accent_ReviewSolid
gameboy_secondary_ReviewSolid
gameboy_body_ReviewSolid
snes_detail_ReviewSolid
snes_accent_ReviewSolid
snes_secondary_ReviewSolid
snes_body_ReviewSolid
phone_detail_ReviewSolid
phone_accent_ReviewSolid
phone_secondary_ReviewSolid
phone_body_ReviewSolid
ipod_detail_ReviewSolid
ipod_accent_ReviewSolid
ipod_secondary_ReviewSolid
ipod_body_ReviewSolid

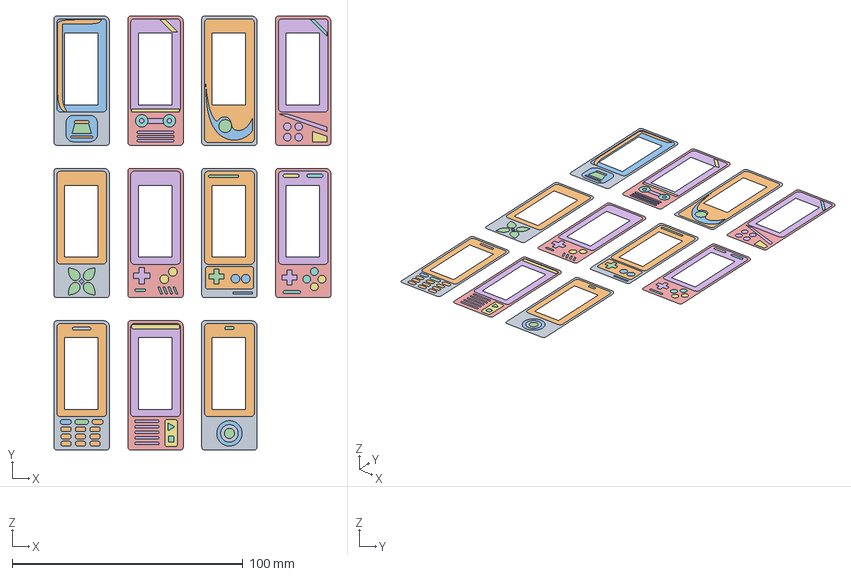
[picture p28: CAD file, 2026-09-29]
design/proposals/frame-master-r3/Artwork-R3.FCStd
120.0 x 188.0 x 0 mm
body / #F2DFAF
detail / #68422F
accent / #B96732
secondary / #DFAB50
body / #D2CEC1
detail / #303738
accent / #E27136
secondary / #F0E9D6
body / #EEE5CD
detail / #315C4E
accent / #DF7339
secondary / #EEE5CD
body / #F0EADB
detail / #27282E
accent / #DA453D
secondary / #F0EADB
body / #F1E6CA
detail / #244E91
accent / #C36443
secondary / #244E91
body / #DCD6BA
detail / #42454D
accent / #973C60
secondary / #A6A392
body / #C6C7BE
detail / #32363B
accent / #C94B3E
secondary / #8A8D8D
body / #D1D0C9
detail / #464751
accent / #746198
secondary / #ACA0C2
body / #263C55
detail / #B8BBB5
accent / #87AD67
secondary / #455469
body / #275273
detail / #192D3B
accent / #E4B54B
secondary / #ACBCC0
body / #F0EEE5
detail / #656F79
accent / #AFB4B1
secondary / #D8D9D2

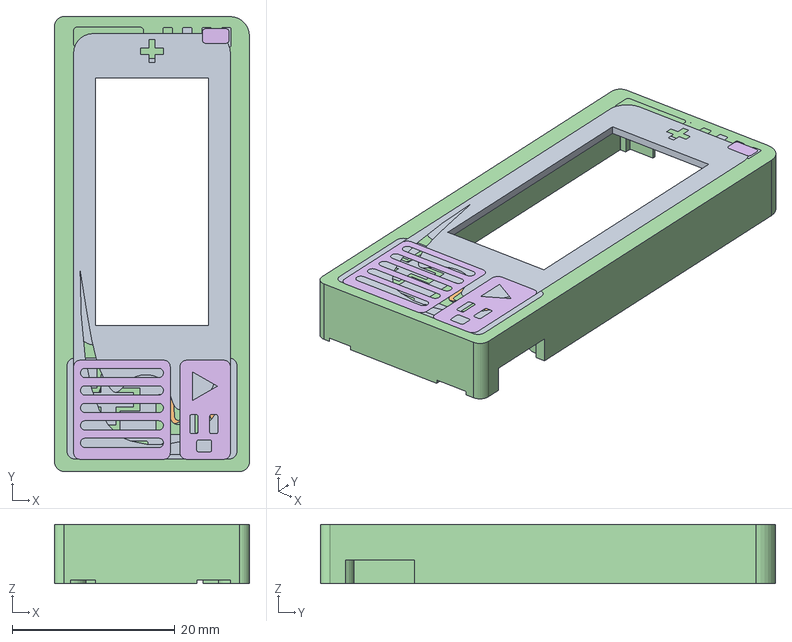
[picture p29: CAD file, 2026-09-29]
design/proposals/frame-redesign-r5/Artwork-R5.FCStd
24.0 x 56.0 x 7.29 mm
flan_detail_ReviewSolid
flan_accent_ReviewSolid
flan_secondary_ReviewSolid
flan_body_ReviewSolid
tape_detail_ReviewSolid
tape_accent_ReviewSolid
tape_secondary_ReviewSolid
tape_body_ReviewSolid
orbit_detail_ReviewSolid
orbit_accent_ReviewSolid
orbit_secondary_ReviewSolid
orbit_body_ReviewSolid
manga_detail_ReviewSolid
manga_accent_ReviewSolid
manga_secondary_ReviewSolid
manga_body_ReviewSolid
nes_detail_ReviewSolid
nes_accent_ReviewSolid
nes_secondary_ReviewSolid
nes_body_ReviewSolid
walkman_detail_ReviewSolid
walkman_accent_ReviewSolid
walkman_secondary_ReviewSolid
walkman_body_ReviewSolid

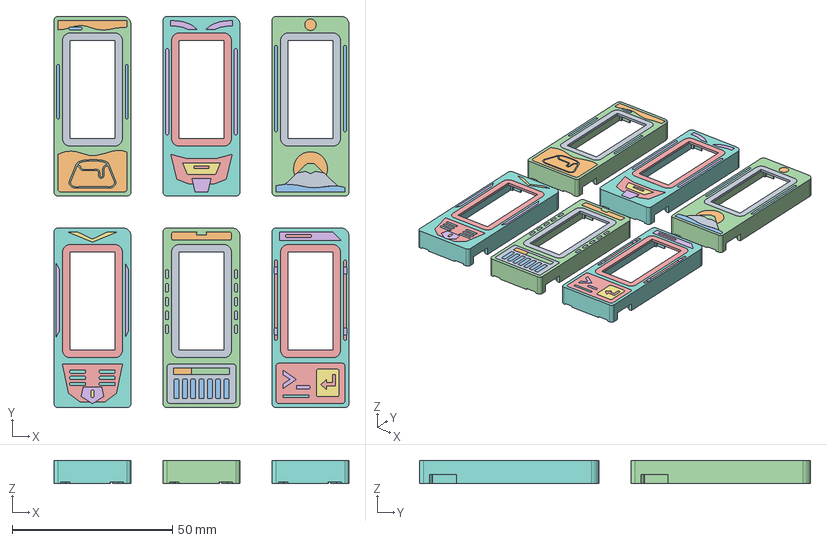
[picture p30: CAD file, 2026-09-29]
design/proposals/frame-redesign-r6/Artwork-R6.FCStd
92.0 x 122.0 x 7.29 mm
flan_detail_ReviewSolid
flan_accent_ReviewSolid
flan_secondary_ReviewSolid
flan_body_ReviewSolid
tape_detail_ReviewSolid
tape_accent_ReviewSolid
tape_secondary_ReviewSolid
tape_body_ReviewSolid
orbit_detail_ReviewSolid
orbit_accent_ReviewSolid
orbit_secondary_ReviewSolid
orbit_body_ReviewSolid
manga_detail_ReviewSolid
manga_accent_ReviewSolid
manga_secondary_ReviewSolid
manga_body_ReviewSolid
nes_detail_ReviewSolid
nes_accent_ReviewSolid
nes_secondary_ReviewSolid
nes_body_ReviewSolid
walkman_detail_ReviewSolid
walkman_accent_ReviewSolid
walkman_secondary_ReviewSolid
walkman_body_ReviewSolid

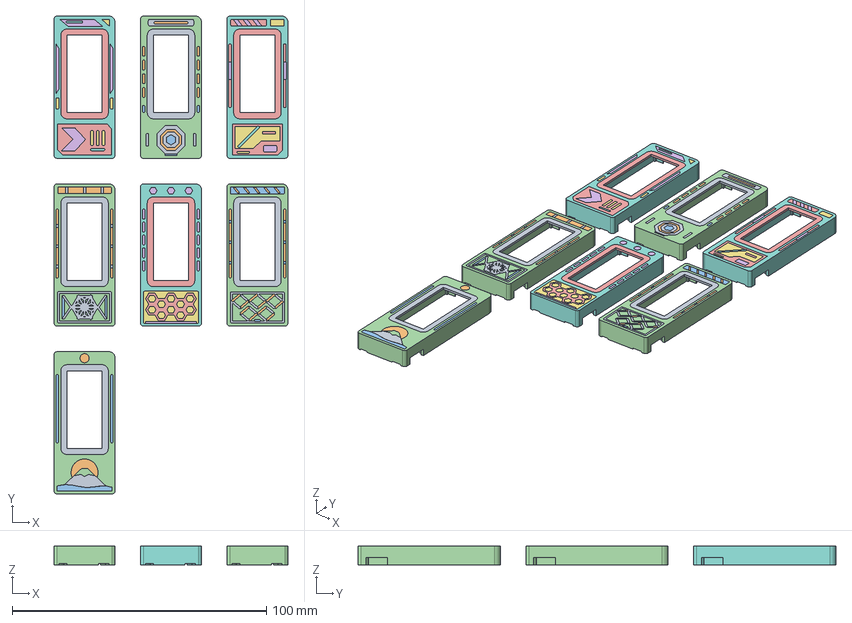
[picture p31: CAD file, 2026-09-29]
design/proposals/frame-redesign-r7/Artwork-R7.FCStd
92.0 x 188.0 x 7.29 mm
hanafuda_detail_ReviewSolid
hanafuda_accent_ReviewSolid
hanafuda_secondary_ReviewSolid
hanafuda_body_ReviewSolid
mecha_recon_detail_ReviewSolid
mecha_recon_accent_ReviewSolid
mecha_recon_secondary_ReviewSolid
mecha_recon_body_ReviewSolid
mecha_reactor_detail_ReviewSolid
mecha_reactor_accent_ReviewSolid
mecha_reactor_secondary_ReviewSolid
mecha_reactor_body_ReviewSolid
mecha_hangar_detail_ReviewSolid
mecha_hangar_accent_ReviewSolid
mecha_hangar_secondary_ReviewSolid
mecha_hangar_body_ReviewSolid
kumiko_asanoha_detail_ReviewSolid
kumiko_asanoha_accent_ReviewSolid
kumiko_asanoha_secondary_ReviewSolid
kumiko_asanoha_body_ReviewSolid
kumiko_kikko_detail_ReviewSolid
kumiko_kikko_accent_ReviewSolid
kumiko_kikko_secondary_ReviewSolid
kumiko_kikko_body_ReviewSolid
kumiko_kasane_detail_ReviewSolid
kumiko_kasane_accent_ReviewSolid
kumiko_kasane_secondary_ReviewSolid
kumiko_kasane_body_ReviewSolid

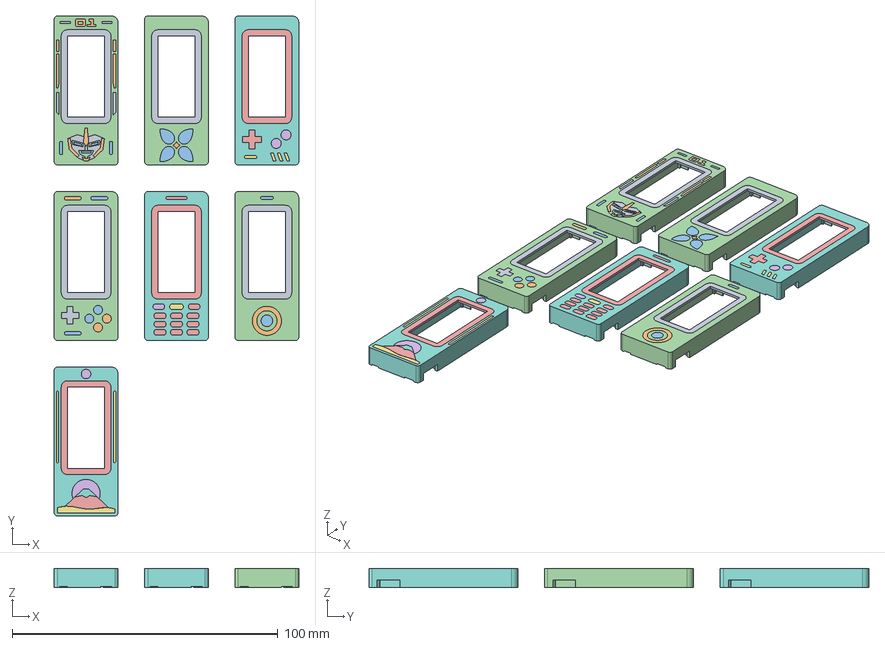
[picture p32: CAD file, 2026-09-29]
design/proposals/frame-redesign-r8/Artwork-R8.FCStd
92.0 x 188.0 x 7.29 mm
talavera_detail_ReviewSolid
talavera_accent_ReviewSolid
talavera_secondary_ReviewSolid
talavera_body_ReviewSolid
gameboy_detail_ReviewSolid
gameboy_accent_ReviewSolid
gameboy_secondary_ReviewSolid
gameboy_body_ReviewSolid
snes_detail_ReviewSolid
snes_accent_ReviewSolid
snes_secondary_ReviewSolid
snes_body_ReviewSolid
phone_detail_ReviewSolid
phone_accent_ReviewSolid
phone_secondary_ReviewSolid
phone_body_ReviewSolid
ipod_detail_ReviewSolid
ipod_accent_ReviewSolid
ipod_secondary_ReviewSolid
ipod_body_ReviewSolid
hanafuda_detail_ReviewSolid
hanafuda_accent_ReviewSolid
hanafuda_secondary_ReviewSolid
hanafuda_body_ReviewSolid
evangelion_detail_ReviewSolid
evangelion_accent_ReviewSolid
evangelion_secondary_ReviewSolid
evangelion_body_ReviewSolid

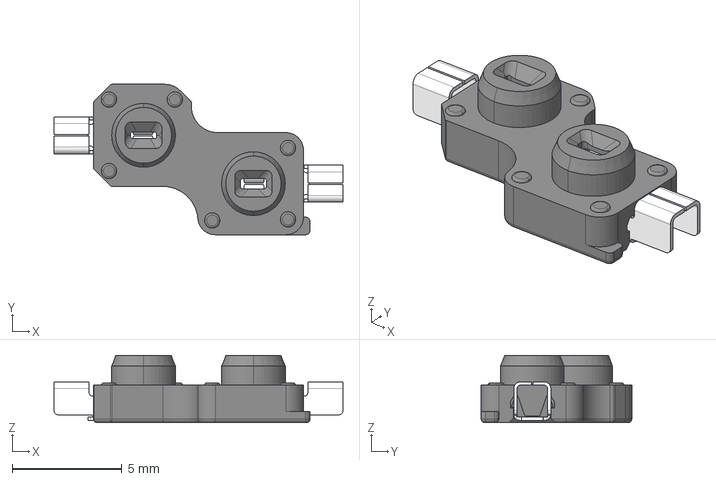
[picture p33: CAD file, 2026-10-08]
hardware/revI/models/choc-hotswap.step
13.2 x 6.85 x 3.05 mm

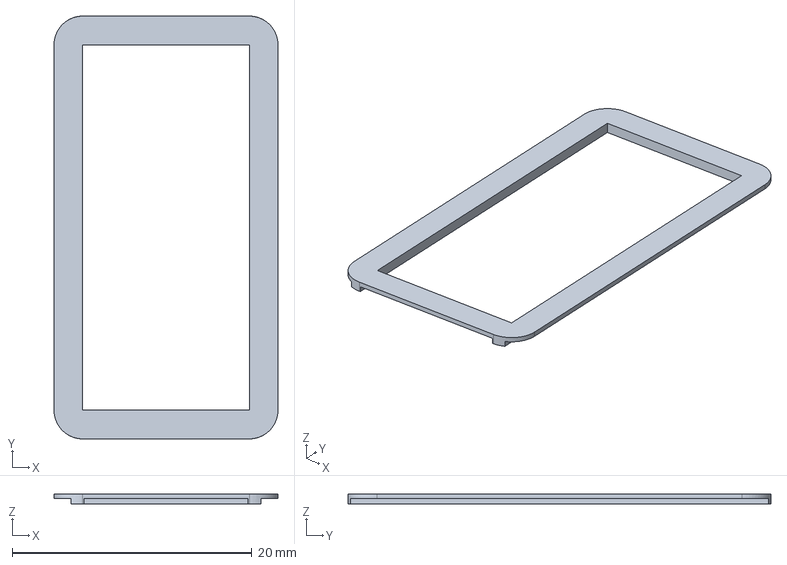
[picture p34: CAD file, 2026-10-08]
mechanical/revI/left-frame-talavera-detail.step
18.7 x 35.3 x 0.865 mm

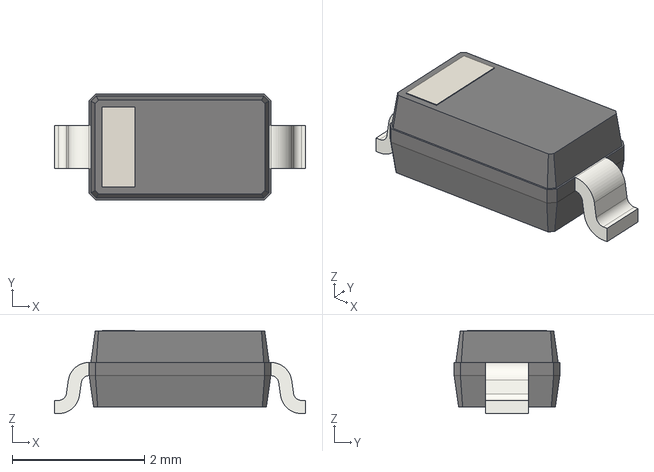
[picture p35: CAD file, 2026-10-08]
hardware/revI/models/diode-sod123.step
3.80 x 1.60 x 1.26 mm

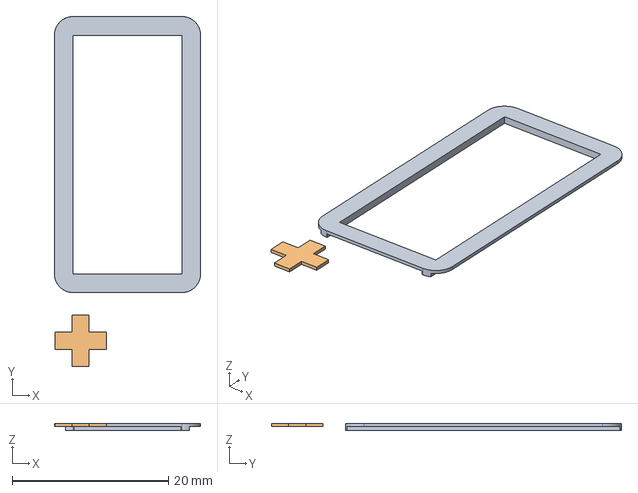
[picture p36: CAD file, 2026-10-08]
mechanical/revI/right-frame-snes-detail.step
18.7 x 44.8 x 0.865 mm

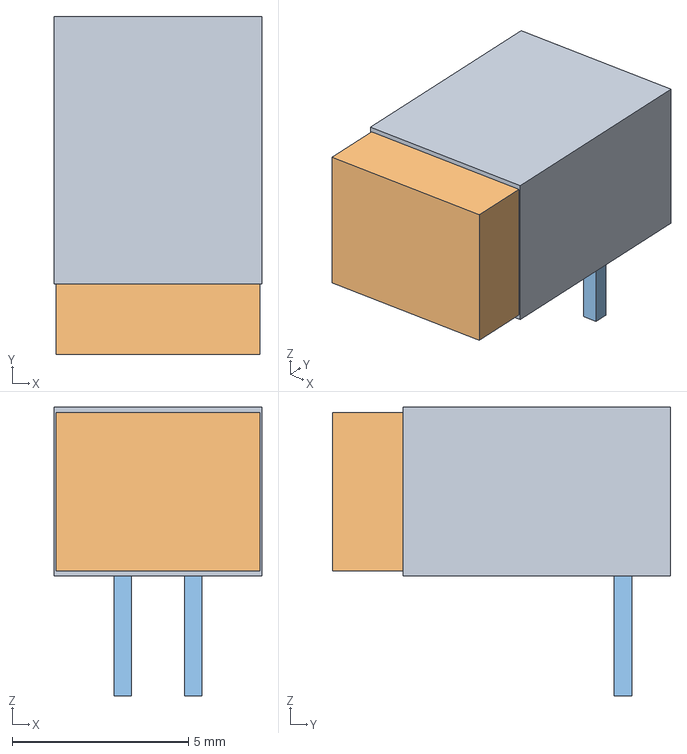
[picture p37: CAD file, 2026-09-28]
hardware/revI/models/right-jst.step
5.90 x 9.60 x 8.20 mm

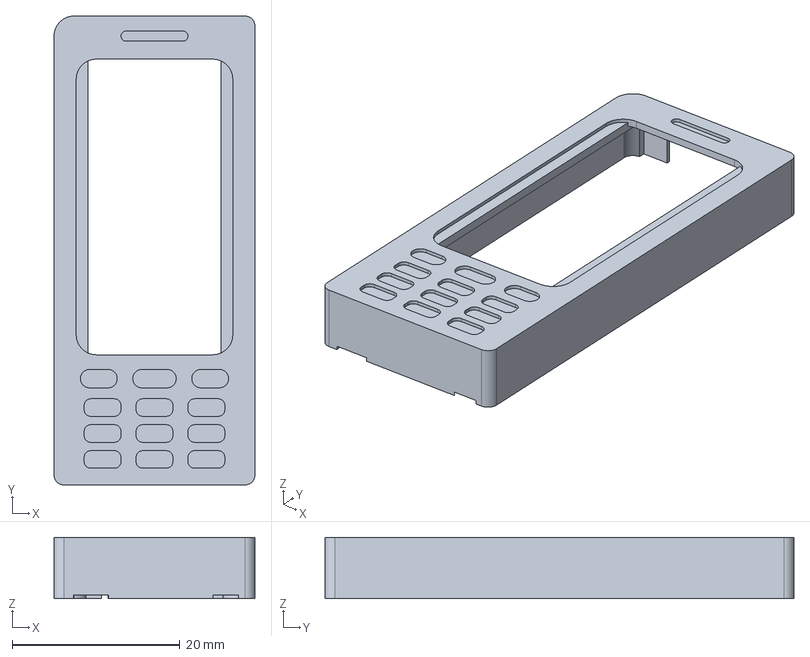
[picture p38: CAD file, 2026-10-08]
mechanical/revI/right-frame-phone-body.step
24.0 x 56.0 x 7.29 mm

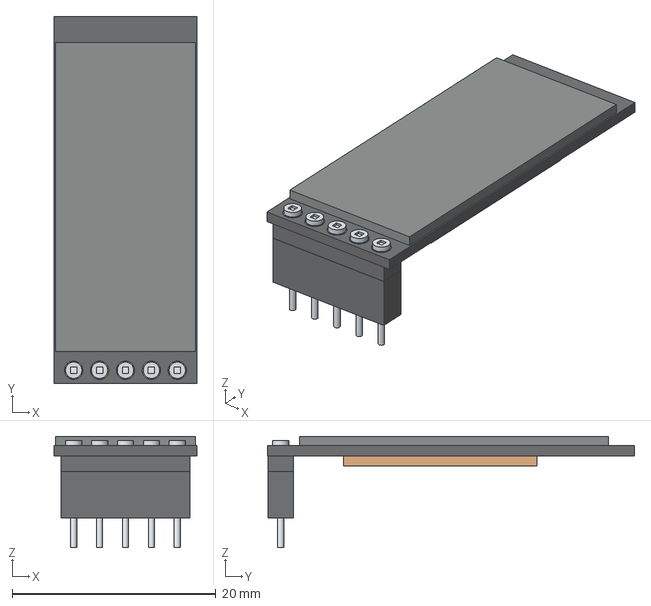
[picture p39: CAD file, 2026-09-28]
hardware/revI/models/right-display.step
14.0 x 36.0 x 10.9 mm

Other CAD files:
mechanical/revI/left-assembly.step
design/proposals/frame-master-r4/Artwork-R4.FCStd
mechanical/revI/right-frame-hanafuda-detail.step
hardware/revI/models/left-display.step
hardware/revI/models/choc-envelope.step
hardware/revI/models/left-jst.step
hardware/revI/models/left-mcu.step
hardware/revI/models/left-reset.step
hardware/revI/models/left-slider.step
hardware/revI/models/right-mcu.step
hardware/revI/models/right-reset.step
hardware/revI/models/right-slider.step
mechanical/revI/component-hotswap-0.stl
mechanical/revI/component-hotswap-1.stl
mechanical/revI/coupon-m2-thread.step
mechanical/revI/coupon-magnet-base.step
mechanical/revI/coupon-magnet-frame.step
mechanical/revI/coupon-magnet-frame.stl
mechanical/revI/left-battery-301230.stl
mechanical/revI/left-battery-adafruit-1570.stl
mechanical/revI/left-battery-lead-0.stl
mechanical/revI/left-battery-lead-1.stl
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

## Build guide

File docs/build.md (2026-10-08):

# Build status

The current design is a routed digital prototype. [Gerber/drill packages](electronics.md) and [compiled UF2 firmware](firmware.md) are available. Both boards pass DRC, ERC and schematic parity with no disconnected nets. Connectors, printed fit, retention and operation have not been physically qualified; the BOM remains a candidate until supplied parts are measured.

The intended sequence is:

1. Close the BOM and measure the actual components.
2. Print a Choc fit coupon and three KLP Lamé samples. Check stem fit, return and comfort before printing the full set.
3. After confirming the actual connector/pack fit, use the matching prototype PCB package. Solder the small parts, then sockets/connectors; check continuity and polarity before fitting either controller.
4. Follow the [firmware guide](firmware.md) to flash each half and test all 36 keys, combinations, layers and key releases.
5. Install the supported battery, controller, display and frames without loading the pouch or glass.
6. Verify BLE, charging, sleep/wake and measured power use.

PLA Basic and PETG HF are available for prototype trials; ABS is another case material. No filament/profile is qualified for the final parts yet. Print orientation and stem tolerances need physical tests. [Parts and alternatives](parts.md).

## Inspect the layout now

`design/layout.json` contains each half’s 18 key centers and angles in millimeters. The original Piantor boards and provenance are under `sources/` and [ATTRIBUTION.md](../ATTRIBUTION.md).

```sh
python3 tools/check_layout.py
python3 tools/render_layout.py
```

The checker compares all 36 positions/rotations with the original boards. The renderer regenerates the layout diagram. `sources/piantor/` contains the original **wired** reference boards, not Flan36’s wireless PCB designs.

## Magnetic frame and service

The frame is cosmetic and removable. The five internal structural screws per half keep the PCB and battery cage secured when the frame is lifted. Its three small locator lips resist sliding; magnets provide attraction. Do not use the frame as a carrying handle before retention is measured.

1. **Print the coupons first:** [magnet base](../mechanical/revI/coupon-magnet-base.stl), [frame target](../mechanical/revI/coupon-magnet-frame.stl), and [M2 thread](../mechanical/revI/coupon-m2-thread.stl). These are cropped production interfaces, at assembly coordinates. Orient the broad face on the bed and inspect every layer in the slicer.
2. **Pause and insert:** the base pocket is Ø2.3 × 3.2 mm for the Ø2 × 3 mm magnet; the frame pocket is Ø2.2 × 4.2 mm for the steel pin. Insert before the pocket closes and confirm the insert sits below the next nozzle path. The top coupon can print with its broad top face on the bed. Choose pauses from the actual sliced layer, not an assumed layer number.
3. **Qualify capture and heat:** enclosed inserts must stay captive after flexing and repeated removal. The reference magnet is rated to 80°C; verify its actual thermal exposure during printing. A low bed setting alone does not establish that. PLA Basic is the first coupon material to investigate; PETG HF and ABS remain alternatives to qualify.
4. **Check attraction and sliding:** reproduce the nominal 0.9 mm magnetic gap (pocket float allows roughly 0.7–1.1 mm before print tolerances). Check north-edge peel on a complete frame; a single-station coupon cannot establish whole-frame retention.
5. **Tap and test the M2 pilot:** use an M2 tap in the Ø1.7 mm printed hole, then test the specified screw without bottoming or stripping. Do not assume the screws are self-tapping.

For the nominal assembly, seat the open-bottom locator, cell directly on the **1.4 mm case floor**, and cage before lowering the PCB over the cell. The cage’s wider feet remain below the board. Install the three plate spacers and structural screws, then the removable modules and frame. Do not compress the pouch. Actual lead exit and strain relief remain to be qualified.

For service, power off and disconnect USB first. Lift the magnetic frame and use the [inherited nominal removal sequence](slim-flush.md) to expose and unplug the battery connector. Remove the caps, then the three plate screws and plate/Level upper shell, then the two short PCB screws and PCB before withdrawing the captured cage. The magnetic cover alone does not release the battery. Cable flex, connector grip and actual removal still need a physical trial. Reset is operated from the underside with a small tool through the recessed access hole.

The [historical support study](slim-mount-study.md) records why the earlier closed cable tunnels prevented display/sled removal. The [current Level stack](level-stack.md) retains the open-bottom support relief and lowers both battery-specific cable routes with the cell. Its glass remains at 13.39 mm beneath the 13.59 mm frame/shell plane and relies on an unqualified Samtec connector substitution; the stock display connector belongs to the previous taller stack. Digital checks do not qualify bending forces or real terminal tolerances.

## Hardware acceptance

No item below has been physically accepted. Record the supplied part number, measurement or observation rather than checking an item from a CAD image.

| Test | Acceptance evidence |
|---|---|
| Actual parts | Cell envelope, protection wrapping, lead exit and polarity; 301230 charge limit; controller/display connector fit and installed height |
| Printed interfaces | Choc stem/return, screw engagement, captive magnet/pin retention, frame peel/sliding and battery service without pouch or glass loading |
| Bare assembly | Continuity, no power short, diode orientation and 36 unique switches without stuck/reversed keys |
| Firmware and displays | Correct half images, four layers, simultaneous keys, both screens or selected single-screen option, reset and wake recovery |
| Wireless operation | Pairing, reconnect after power cycle, sleep/wake and usable range in the complete case |
| Charging and power | Correct cell charge limit and polarity, SW1 behavior, measured active/idle/sleep current and no abnormal heating |

The next physical step is to measure the exact connector pair and supplied cell, then print the small fit/retention coupons. The source and firmware candidates can be revised from those results without changing the key layout.

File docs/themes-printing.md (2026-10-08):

# Make it yours

Open [the 3D explorer](https://eduarbo.github.io/flan36/), choose **Themes**, and pick a starting palette. Twenty-eight presets coordinate the case, frame and keycaps. Their previews use your selected shapes.

All five finger columns share the same base color. Each thumb gets its own coordinated accent, mirrored between halves. In **Caps → Colors**, eight independent palettes follow the same approach: **Sunset rows** colors whole finger rows and **Arcade thumbs** puts its bright accents on the three thumbs. **Original** keeps matching green thumbs.

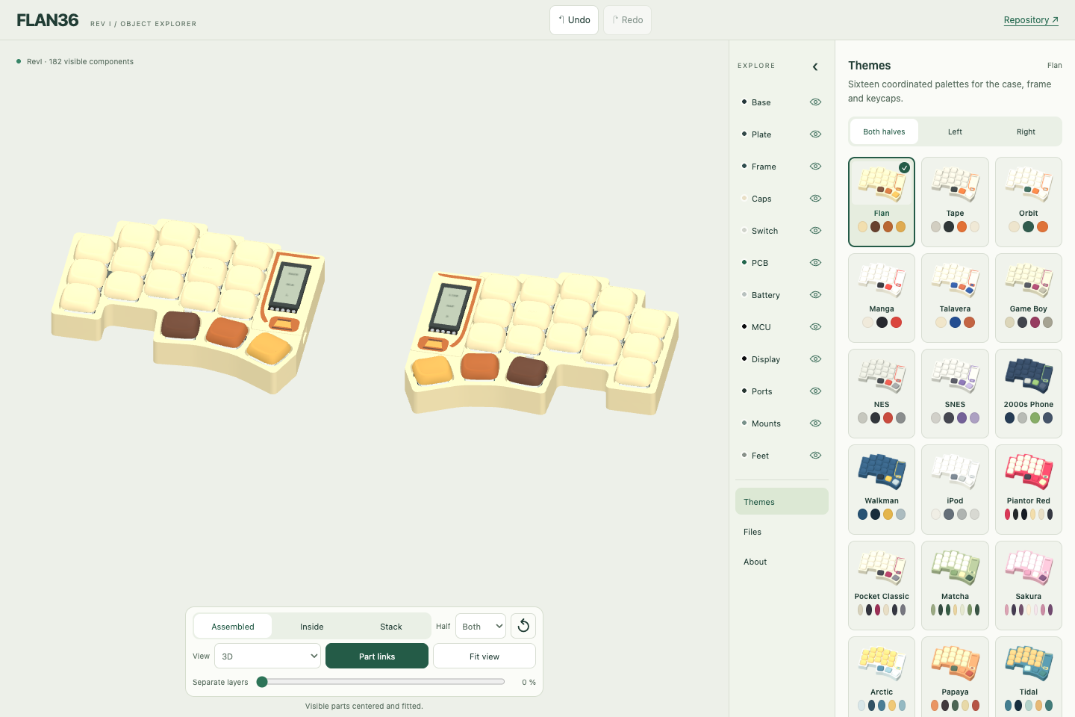
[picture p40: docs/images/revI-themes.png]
Theme gallery and coordinated rim/frame colors


1. Choose **Both halves**, **Left** or **Right**.
2. Pick a theme. It changes colors while preserving shapes, keycap geometry and installed covers.
3. In **Base**, edit the base/rim and key plate. In **Frame**, edit the body and flush inlays. Every color also has a HEX field and **Copy** button.
4. Enable **Match frame and rim** for continuous color. Editing either linked color updates the other; with Level, the upper shell joins the linked base and frame color.
5. Use **Files → Download print kit** for the selected parts.

The [six installed approved frames](frames-extra.md) have four solid-color regions. Talavera is the default. Each design has a matching global palette; **Restore design colors** restores the selected frame palette.

Changing shapes preserves customized colors. An untouched original design adopts the new shape's original palette. Frame and theme changes preserve cover visibility and the current inspection.

## Keep your configuration

Selections save automatically on this device. **Save configuration** downloads JSON for another browser or the FreeCAD configuration macro. JSON carries explicit colors, shapes and cover installation, so a preset name never changes an old saved design. Legacy JSON still loads.

To update an existing design to these colors, select its theme or cap palette again. Custom colors remain editable per key, row or column.

The [current collection checks](../validation/revI-approved-selection.json) cover native material exports, configuration migration and viewer behavior. The earlier [thumb-palette receipt](../validation/revI-thumb-themes.json) records the previous palette set.

Eye, Solo, camera and exploded views are inspection controls. They do not remove parts from the print kit. Unchecking **Printed display cover** does remove that cover and its targets from the selected assembly.

## Printable parts and joining

**Shells** exports each selected case, key plate and installed frame. For Level, the switch-retaining plate and raised upper shell export as one removable part. **Complete printed set** also includes the open-bottom battery locator, cage, controller support, display support and three printed washers per half. Commercial parts and KLP keycaps are excluded; [keycap sources and fit guidance](customize.md#klp-lamé) remain separate.

The [historical support study](slim-mount-study.md) includes experimental plates with integrated washers and bases with integrated saddles. These reduce loose parts, not height. They predate the current floor-mounted battery and Level shell; their separate downloads are comparison geometry, not replacements in the current print kit.

- The structural case uses three M2 × 6 and two M2 × 4 screws per half. Tap the 1.7 mm pilot holes to M2.
- Each installed frame uses three captive Ø2 × 3 mm magnets and three Ø2 × 4 mm ferromagnetic pins.
- Cavities, guides and screw holes belong to the CAD geometry. Plan insertion pauses for captive hardware before slicing.
- There is no clip variant yet. A color or theme does not change the joining method.

The ZIP includes the selected geometry, JSON and a manifest with quantities, source hashes, units, colors and joining details. STL coordinates are the unchanged native assembly coordinates, in millimetres. Prepare orientation, supports, tolerances and your actual filament in the slicer.

This is prototype geometry. Print [fit coupons](cases.md) before a complete set. Neither magnets, tapped threads nor the whole assembly have physical acceptance yet.

## Color 3MF status

Decorated frames export as **multipart 3MF assemblies**: one recessed shell and separate closed volumes for the three inlay colors. All parts share one transform, so the inlays stay registered to their pockets. All colors finish at the **13.59 mm** roof. The five approved R4 frames use 0.4 mm surface inlays with 1.0 mm backing outside the display relief, a 0.865 mm through-color collar and a 0.4 mm through-color pin cover. Rejected shapes are excluded from the active viewer and its print kit. Hanafuda uses its exact approved R8 paths with the same construction. See the [construction rules](frames-extra.md).

These are complementary volumes for **co-printing**, not separately printed press-fit inserts. Use compatible colors of the same material and qualify their bonding on a small sample. The kit also includes the original aligned material STLs and a fused single-material STL. The fused file has a plain surface and cannot reproduce the color pattern by geometry alone.

The generic files contain no printer or process profile. The manifest records the common bed translation, colors, material roles and source hashes.

**Check the filament assignments in Bambu Studio.** Map **body, detail, accent and secondary** to the manifest colors and keep the material volumes together as one multipart object. Automatic palette assignment and slicer GUI save/reopen remain unverified. Inspect the sliced inlay layers before printing.

Keycaps are included in global themes. For independent colors, row/column patterns and portable personal palettes, use [Caps → Colors](customize.md#keycap-colors). Selecting another keycap shape preserves its assigned color.

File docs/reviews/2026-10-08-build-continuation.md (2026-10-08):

# Build continuation

The original outcome is a buildable, slim, completely wireless 36-key split with the retained Piantor key poses, Choc hot-swap, removable electronics, nice!nano v2, low-power displays, both battery envelopes and printable KLP Lamé caps/cases/approved frames. Finishing the digital audit does not finish that outcome.

Source: Eduardo's continued build request, including “si no has terminado, por que vuelves a parar?” on 2026-10-08. Starting point: `fe8c7fdc1b13b8eac6383c3315af8e749b1b8d4c`.

Required outcomes:

1. **Electrical candidate:** preserve all component poses, holes and contours; reconcile schematic/PCB; route both halves; verify every physical pad, semantic matrix, ERC and DRC without disconnected nets. Preserve exact source-bound fabrication outputs.
2. **Firmware:** pinned and rebuildable ZMK; left central/right peripheral, custom SPI, 36 physical key mappings, both displays and the optional right without a display. Inspect compiled DTS/configuration and valid UF2 blocks.
3. **Build package:** concise English assembly, BOM/alternatives, exact files and acceptance procedure; no presentation that implies unperformed physical tests passed.
4. **Physical acceptance:** measured supplied connectors/packs, printed fit and retention, assembled continuity, all keys, display recovery, BLE, safe charging and measured sleep/active current. This remains separate from CAD, routing and compilation and requires actual parts.

Two independent read-only reviews agreed that the existing topology can proceed without moving components. Their principal conditions and source baseline are recorded in [the electrical decision](../../design/reviews/electronics-20261008/decision.json). Firmware uses the verified stable ZMK revision instead of inheriting an unpinned current branch.

Work stays in disposable `build/electronics-20261008/` candidates until the affected checks pass. Historical audit receipts remain historical; new routed-board evidence must identify its own source hashes. The canonical FreeCAD assembly, key positions and selected frame artwork are preserved.

## Verified delivery

Both canonical boards now pass KiCad 10.0.6 DRC, ERC and schematic parity with no unconnected items. Each has 247 physical pads checked, 18 key positions and two copper layers. All original footprint/pad geometry, model references and 676 outline/cutout segments per half match the baseline. The FreeCAD assembly remains unchanged.

The reviewed right-only MCU remap moves rows 0–3 to D21/D20/D19/D18 and column 0 to D15. This avoids routing five signals around the battery opening's 0.55 mm north bridge; it does not widen the case or weaken the original rules. D2–D6 are explicit NC on the right. The matching source and three firmware images use the same per-half pin map.

Independent readback also parsed the emitted Gerbers and drills: each half's 676 outline segments, 91 plated holes and 97 non-plated holes match the PCB; drill serialization is within 0.0005 mm. ZIP readback checks every member and its bound source. [Routing](../../validation/revI-routing.json) · [Fabrication](../../validation/revI-fabrication.json).

All three ZMK variants were rebuilt from 39 clean pinned repositories and the qualified compiler, with source checks before/after each build. Actual DTS/config/UF2 readback verifies the 36-position transform, half roles, GPIO, SPI, screen variants, sleep and firmware address bounds. [Firmware evidence](../../validation/revI-firmware.json) · [Two-reviewer disposition](../../design/reviews/electronics-20261008/firmware-final/decision.json).

## Bugs caught and prevention

- The old PCB values/net names and five mechanical-only footprints disagreed with schematic parity. They now match the authoritative netlist, including every duplicate physical pad. A deliberately wrong duplicate pad is rejected.
- Router import rounded four diode positions per half by at most 0.000046 mm. Exact baseline coordinates were restored and DRC rerun. Edge comparison ignores generated UUIDs and decimal formatting, while preserving exact numeric geometry.
- Initial routing reduced local neck widths and approached cutouts too closely. The accepted boards use at least 0.20 mm everywhere, original 0.20/0.50 mm clearances and no new exclusions. Independent DRC validates the serialized result, not the router's success message.
- Existing firmware validation could describe an old binary using current source hashes. Build-time attestations now bind sources, dependency/compiler identity and actual outputs. Both an edited key binding and a corrupted last-variant binary are rejected before publication.
- Current guides and viewer status now refer to routed candidates. Historical receipts retain their original hashes and observations.

[PCB negative controls](../../validation/revI-routing-negative.json) · [Firmware negative controls](../../validation/revI-firmware-negative.json). The existing Level viewer smoke check passed after the status-text update; its themes, native print bytes, 3MF and frame heights remain unchanged.

## Still required for the original outcome

Digital delivery is complete when its source and packages are synchronized and read back publicly. A buildable, physically accepted keyboard still requires measured supplied connectors/cells, printed fit/retention, assembled continuity and all keys/displays, BLE, charging and current tests. The exact next physical step and acceptance criteria are in [Build](../build.md#hardware-acceptance). No hardware test, purchase, flashing or physical printing is represented as completed here.

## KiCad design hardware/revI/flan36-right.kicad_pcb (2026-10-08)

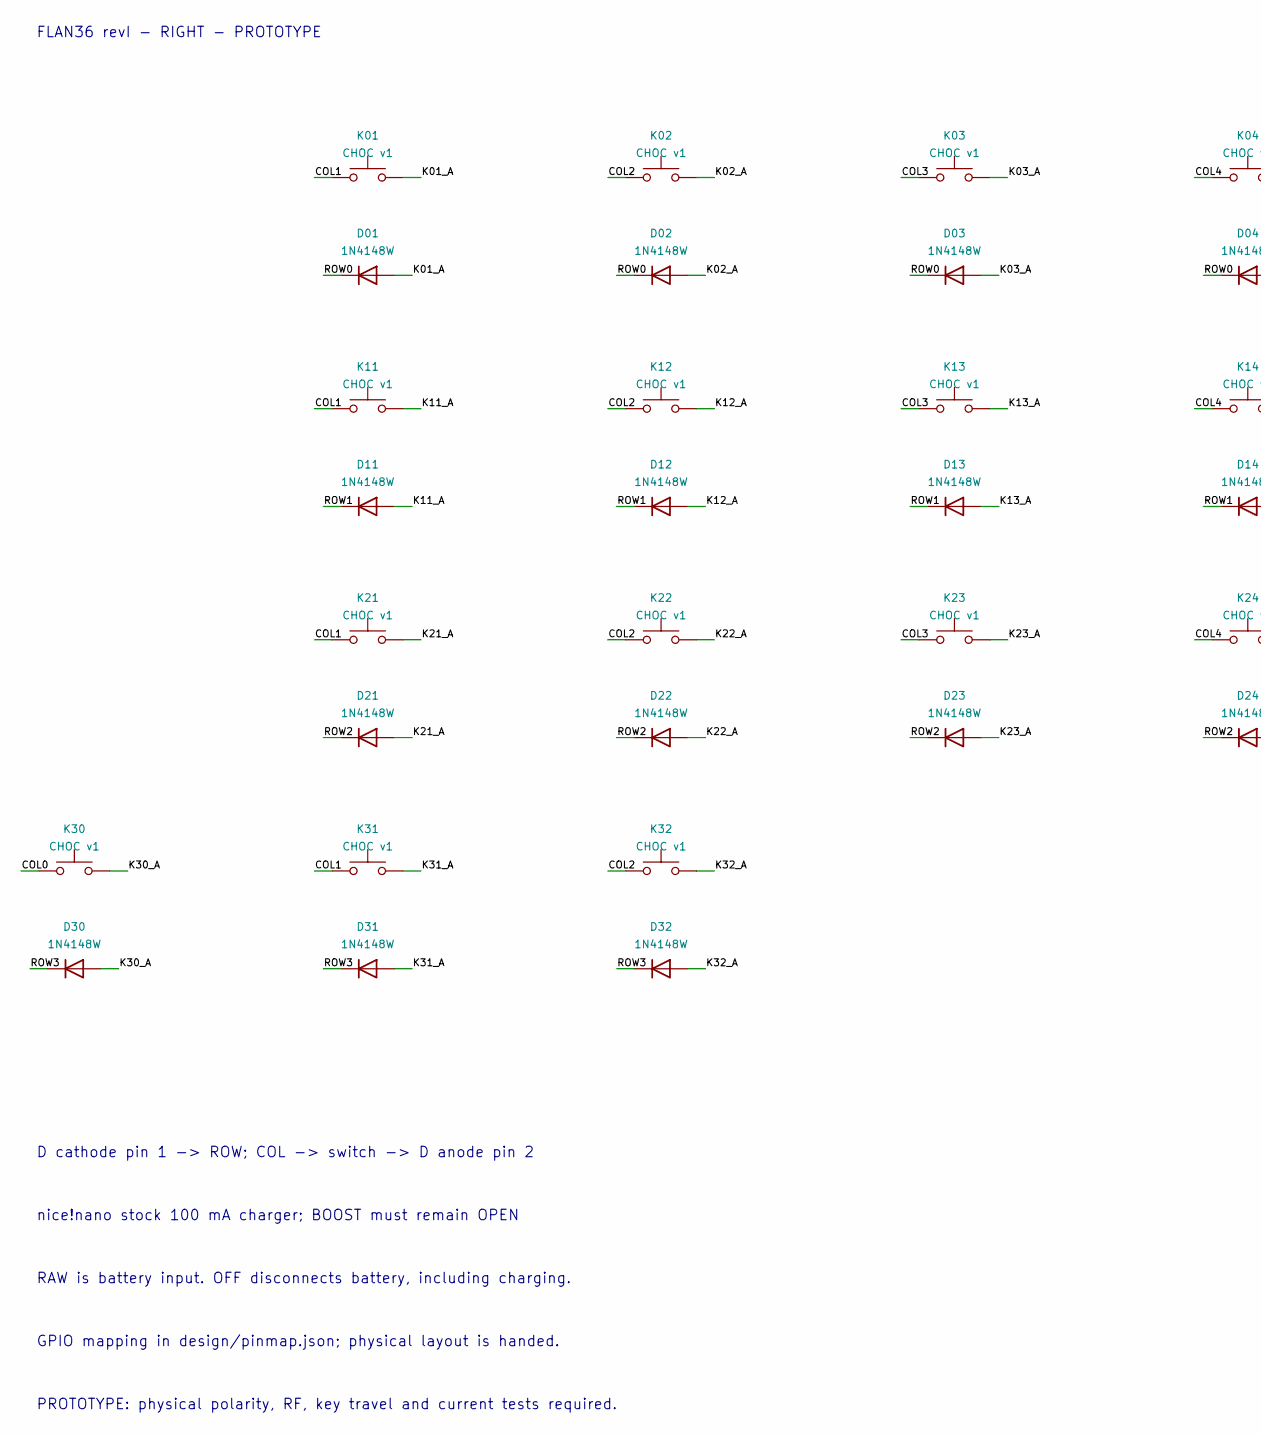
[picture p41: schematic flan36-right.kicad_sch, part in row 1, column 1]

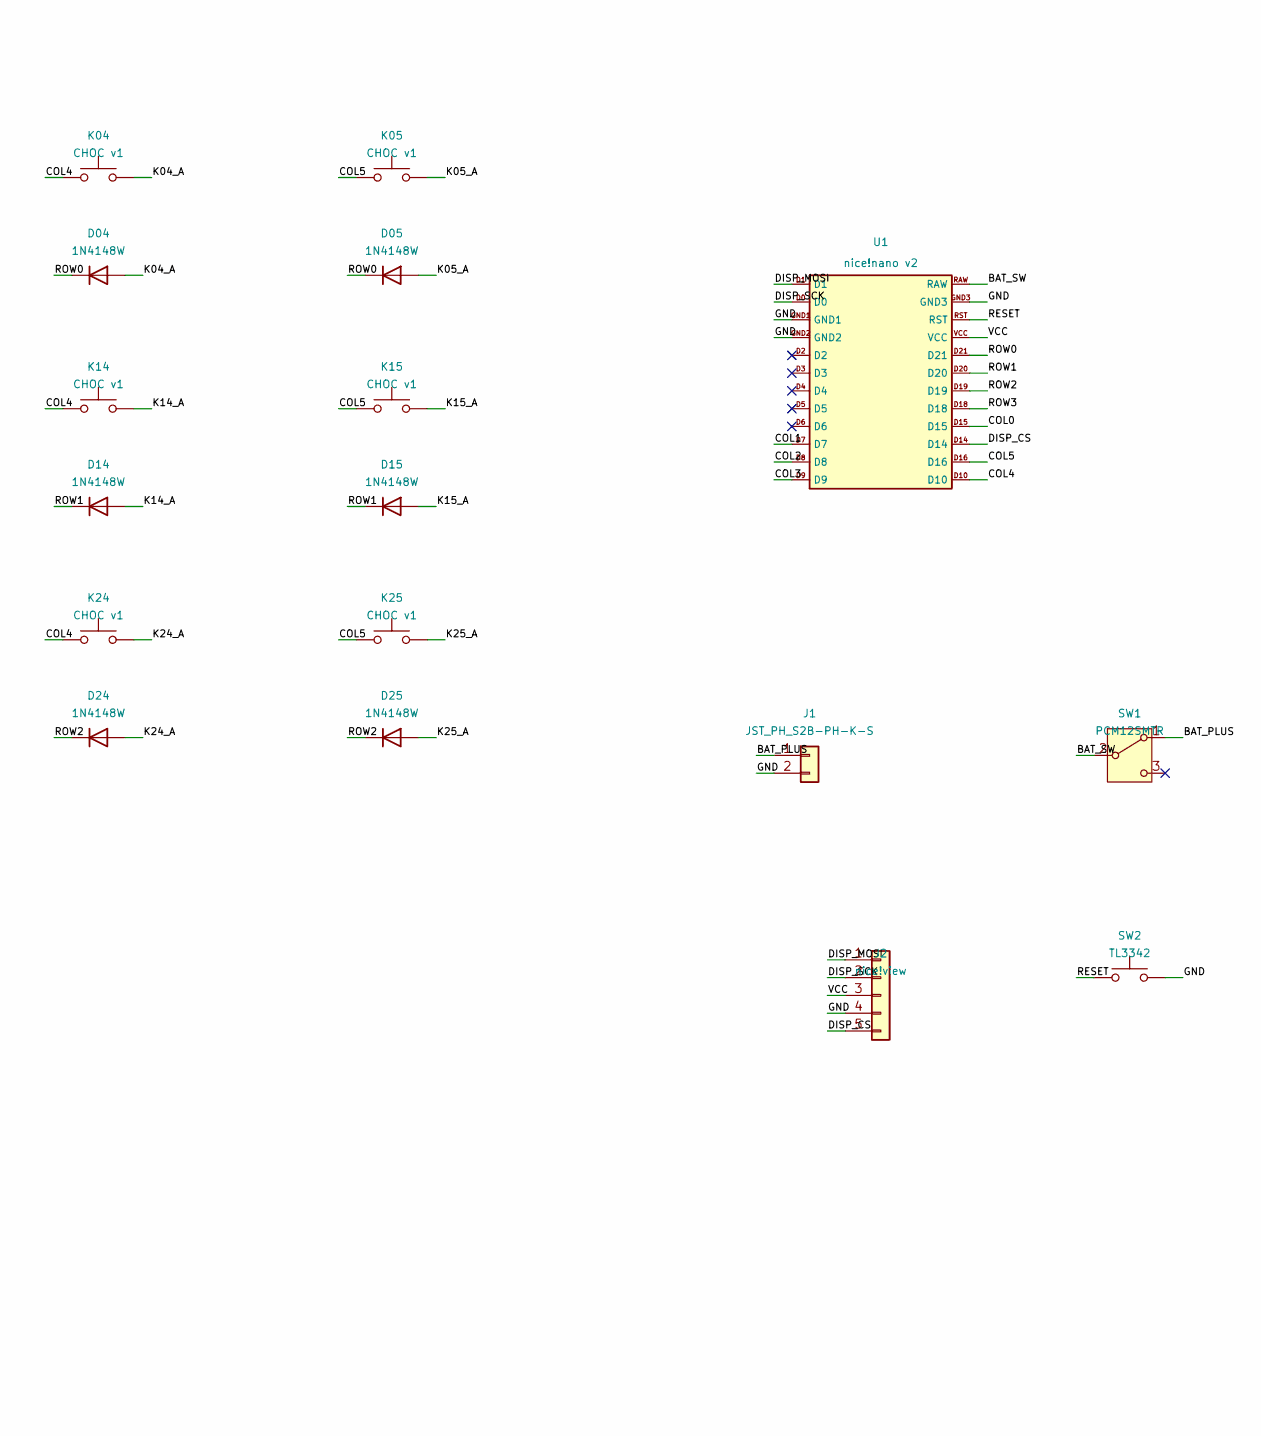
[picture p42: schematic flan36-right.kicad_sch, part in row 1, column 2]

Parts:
D01, D02, D03, D04, D05, D11, D12, D13, D14, D15, D21, D22, D23, D24, D25, D30, D31, D32: 1N4148W; D_SOD-123
J1: JST_PH_S2B-PH-K-S; JST_PH_S2B-PH-K_1x02_P2.00mm_Horizontal
J2: nice!view; nice_view_5pin
K01, K02, K03, K04, K05, K11, K12, K13, K14, K15, K21, K22, K23, K24, K25, K30, K31, K32: CHOC v1; Kailh_socket_PG1350_optional
SW1: PCM12SMTR; SW_SPDT_PCM12
SW2: TL3342; SW_SPST_TL3342
U1: nice!nano v2; nice_nano_v2_standard_edge

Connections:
/BAT_PLUS: J1.1, SW1.1 (A)
/BAT_SW: SW1.2 (B), U1.RAW
/COL0: K30.1, U1.D15
/COL1: K01.1, K11.1, K21.1, K31.1, U1.D7
/COL2: K02.1, K12.1, K22.1, K32.1, U1.D8
/COL3: K03.1, K13.1, K23.1, U1.D9
/COL4: K04.1, K14.1, K24.1, U1.D10
/COL5: K05.1, K15.1, K25.1, U1.D16
/DISP_CS: J2.5, U1.D14
/DISP_MOSI: J2.1, U1.D1
/DISP_SCK: J2.2, U1.D0
/GND: J1.2, J2.4, SW2.2, U1.GND1, U1.GND2, U1.GND3
/K01_A: D01.2 (A), K01.2
/K02_A: D02.2 (A), K02.2
/K03_A: D03.2 (A), K03.2
/K04_A: D04.2 (A), K04.2
/K05_A: D05.2 (A), K05.2
/K11_A: D11.2 (A), K11.2
/K12_A: D12.2 (A), K12.2
/K13_A: D13.2 (A), K13.2
/K14_A: D14.2 (A), K14.2
/K15_A: D15.2 (A), K15.2
/K21_A: D21.2 (A), K21.2
/K22_A: D22.2 (A), K22.2
/K23_A: D23.2 (A), K23.2
/K24_A: D24.2 (A), K24.2
/K25_A: D25.2 (A), K25.2
/K30_A: D30.2 (A), K30.2
/K31_A: D31.2 (A), K31.2
/K32_A: D32.2 (A), K32.2
/RESET: SW2.1, U1.RST
/ROW0: D01.1 (K), D02.1 (K), D03.1 (K), D04.1 (K), D05.1 (K), U1.D21
/ROW1: D11.1 (K), D12.1 (K), D13.1 (K), D14.1 (K), D15.1 (K), U1.D20
/ROW2: D21.1 (K), D22.1 (K), D23.1 (K), D24.1 (K), D25.1 (K), U1.D19
/ROW3: D30.1 (K), D31.1 (K), D32.1 (K), U1.D18
/VCC: J2.3, U1.VCC

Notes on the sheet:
FLAN36 revI - RIGHT - PROTOTYPE
D cathode pin 1 -> ROW; COL -> switch -> D anode pin 2
nice!nano stock 100 mA charger; BOOST must remain OPEN
RAW is battery input. OFF disconnects battery, including charging.
GPIO mapping in design/pinmap.json; physical layout is handed.
PROTOTYPE: physical polarity, RF, key travel and current tests required.

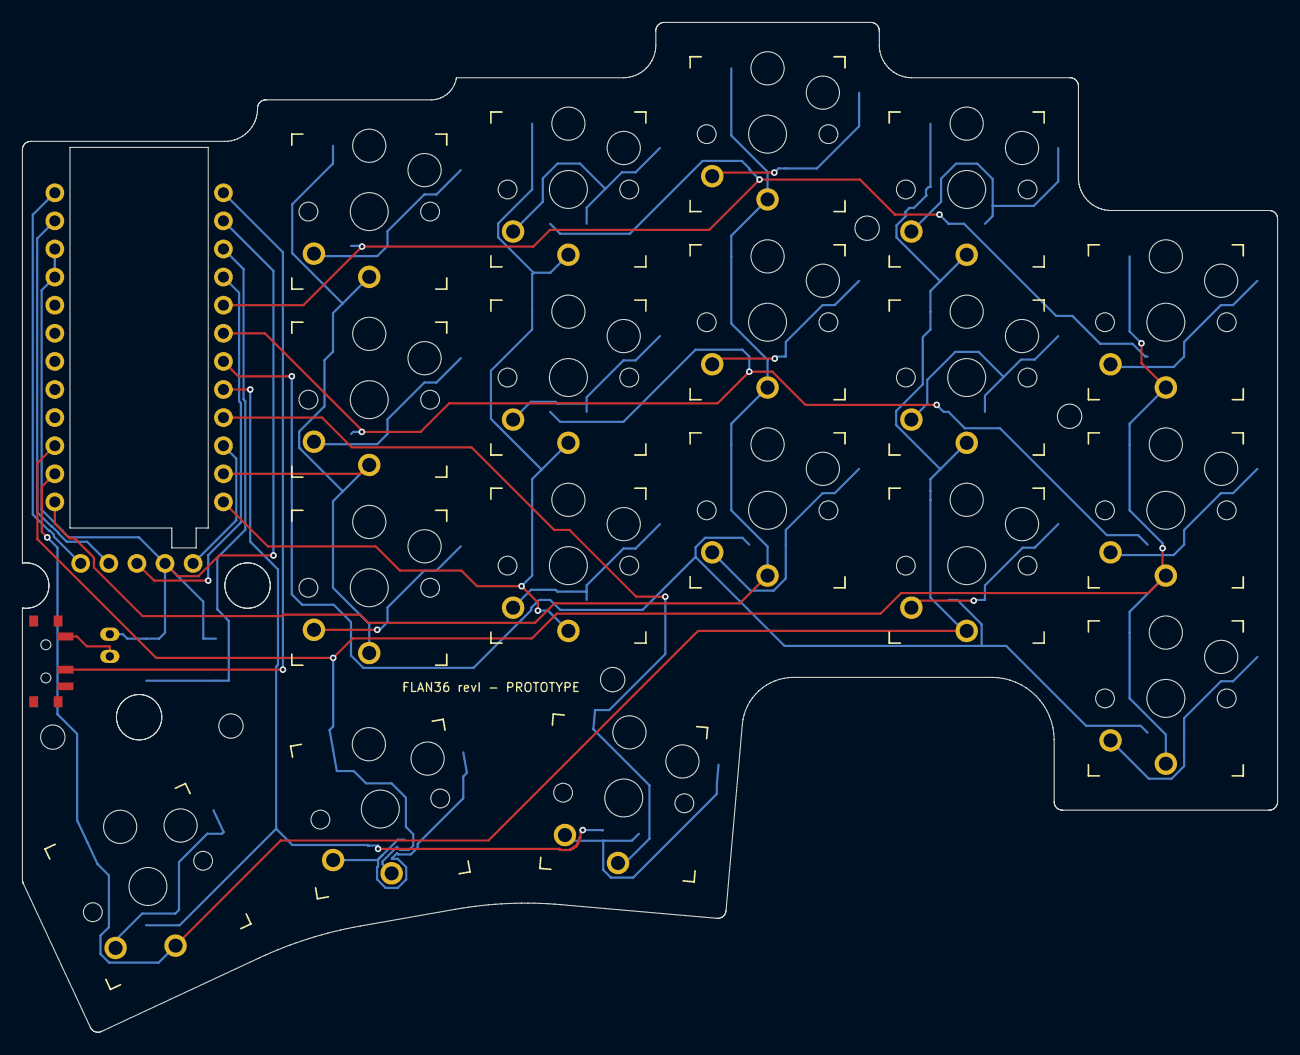
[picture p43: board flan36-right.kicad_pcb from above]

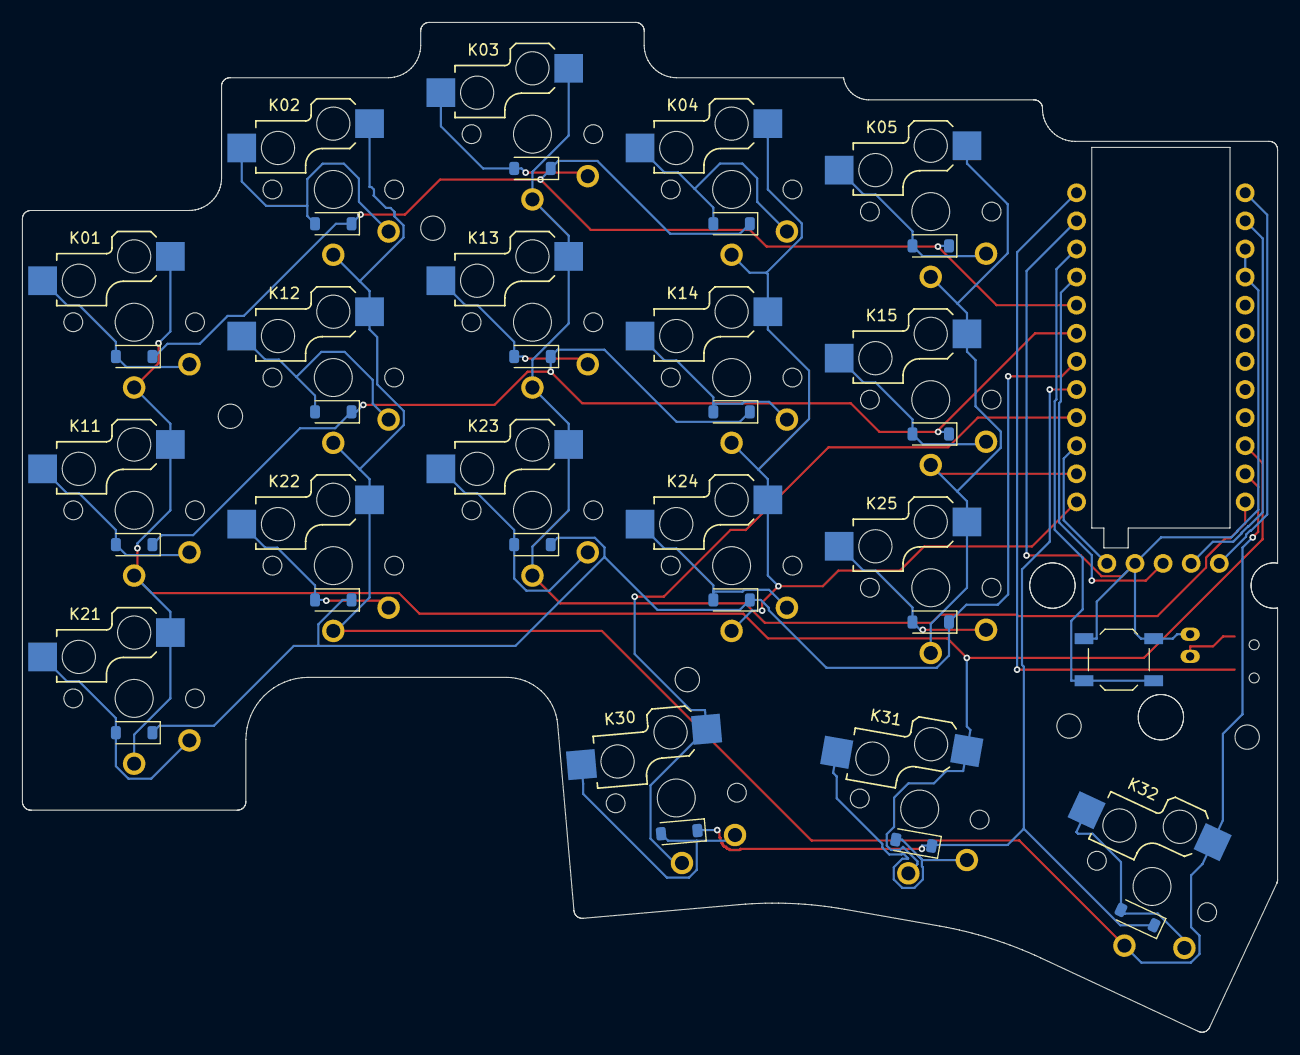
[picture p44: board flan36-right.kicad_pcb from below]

Board: 2 copper layers, 113.4 x 91.3 mm, 46 parts (19 on the bottom side), 36 nets.

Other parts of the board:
H1, H2, H3, H4, H5: MountingHole_2.2mm_M2

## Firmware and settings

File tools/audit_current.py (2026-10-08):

#!/usr/bin/env python3
"""Run the bounded October 2026 audit without rebuilding product artifacts.
SPDX-License-Identifier: GPL-3.0-or-later
"""
import concurrent.futures
import hashlib
import json
import os
from pathlib import Path
import subprocess
import time
import sys

ROOT = Path(__file__).resolve().parents[1]
OUT = ROOT / 'build/audit-20261007'
OUT.mkdir(parents=True, exist_ok=True)
KICAD = os.environ.get('FLAN36_KICAD_CLI', '/Applications/KiCad/KiCad.app/Contents/MacOS/kicad-cli')


def run(name, command):
    start = time.monotonic()
    with (OUT / (name + '.log')).open('w') as log:
        try:
            result = subprocess.run(command, cwd=ROOT, stdout=log, stderr=subprocess.STDOUT, timeout=360)
            status = result.returncode
        except subprocess.TimeoutExpired:
            status = 'timeout'
    record = dict(name=name, command=command, exit_code=status,
                  elapsed_seconds=round(time.monotonic()-start, 2))
    print(name, status, flush=True)
    return record


def browser_checks():
    names = ['reliability', 'frame-collection', 'frame-orientation', 'keycolors',
             'hex', 'cap-rows', 'battery-leads', 'display-seam']
    return [run(name, ['node', 'viewer/' + name + '-check.cjs']) for name in names]


def other_checks():
    results = [run('layout', ['python3', 'tools/check_layout.py'])]
    for name in ['config-contract', 'finishes', 'flush-print', 'level']:
        results.append(run(name, ['node', 'viewer/' + name + '-check.cjs']))
    for side in ['left', 'right']:
        for kind, verb, ext in [('pcb', 'drc', 'kicad_pcb'), ('sch', 'erc', 'kicad_sch')]:
            name = verb + '-' + side
            command = [KICAD, kind, verb, '--format', 'json', '--severity-all',
                       '--exit-code-violations', '--output', str(OUT / (name + '.json'))]
            if kind == 'pcb':
                command.append('--schematic-parity')
            results.append(run(name, command + ['hardware/revI/flan36-' + side + '.' + ext]))
    return results


if __name__ == '__main__':
    with concurrent.futures.ThreadPoolExecutor(max_workers=2) as pool:
        futures = [pool.submit(browser_checks), pool.submit(other_checks)]
        results = [r for future in futures for r in future.result()]
    report = dict(snapshot=subprocess.check_output(['git', 'rev-parse', 'HEAD'], cwd=ROOT, text=True).strip(),
                  runner_sha256=hashlib.sha256(Path(__file__).read_bytes()).hexdigest(),
                  results=results, physical_acceptance=False,
                  inputs=[{'path':p,'sha256':hashlib.sha256((ROOT/p).read_bytes()).hexdigest()}
                          for p in sorted({'docs/index.html','docs/offline.html','design/revI.json','mechanical/revI/Flan36.FCStd',
                                          *[r['command'][1] for r in results if len(r['command'])>1 and (ROOT/r['command'][1]).is_file()]} )])
    (OUT / 'checks.json').write_text(json.dumps(report, indent=2) + '\n')
    # An audit is not a green build merely because its JSON was written. The
    # any failed electrical or viewer check remains a failure. Physical acceptance is separate.
    sys.exit(0 if all(item['exit_code'] == 0 for item in results) else 1)

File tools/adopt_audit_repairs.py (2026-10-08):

#!/usr/bin/env python3
"""Adopt only verified audit-related CAD exports and preserve unrelated mesh bytes.
SPDX-License-Identifier: GPL-3.0-or-later
"""
import collections,hashlib,json,math,shutil,struct,sys
from pathlib import Path
ROOT=Path(__file__).resolve().parents[1]
sha=lambda p:hashlib.sha256(Path(p).read_bytes()).hexdigest()
read=lambda p:json.loads(Path(p).read_text())
ACTIVE={'talavera','gameboy','snes','phone','ipod','hanafuda'}
RETIRED_RECTANGLE_FILES={f'{side}-frame-{style}{suffix}.stl'
                       for side in ['left','right']
                       for style in ['flan','tape','orbit','manga','nes','walkman']
                       for suffix in ['', '-body']}
def mesh_signature(path):
    data=path.read_bytes();count=struct.unpack_from('<I',data,80)[0];assert len(data)==84+50*count,path
    result=collections.Counter()
    for start in range(84,len(data),50):
        v=struct.unpack_from('<9f',data,start+12)
        # Cyclic order is irrelevant; winding is retained and normals derive from it.
        xyz=[tuple(round(x,4) for x in v[i:i+3]) for i in (0,3,6)]
        result[min(tuple(xyz[i:]+xyz[:i]) for i in range(3))]+=1
    return result

def raw_triangles(path):
    """Retain the exact binary STL float32 coordinates and oriented winding."""
    data=path.read_bytes();count=struct.unpack_from('<I',data,80)[0]
    assert len(data)==84+50*count,path
    result=collections.Counter()
    for start in range(84,len(data),50):
        values=struct.unpack_from('<9f',data,start+12)
        assert all(math.isfinite(value) for value in values),('Nonfinite mesh vertex',path)
        points=[tuple(values[i:i+3]) for i in (0,3,6)]
        result[min(tuple(points[i:]+points[:i]) for i in range(3))]+=1
    return result

def vertical_rectangles(triangles):
    """Prove each unmatched pair tiles one vertical rectangle exactly once."""
    grouped=collections.defaultdict(list)
    for triangle,count in triangles.items():
        assert count==1 and len(set(triangle))==3,'Duplicate or degenerate unmatched triangle'
        xy=tuple(sorted({point[:2] for point in triangle}));z=tuple(sorted({point[2] for point in triangle}))
        assert len(xy)==2 and len(z)==2,'Unmatched face is not a vertical rectangle triangle'
        grouped[(xy,z)].append(triangle)
    rectangles={}
    for key,pair in grouped.items():
        assert len(pair)==2,'Rectangle must have exactly two triangles'
        first,second=pair;xy,z=key
        corners={(x,y,height) for x,y in xy for height in z}
        assert set(first)|set(second)==corners,'Rectangle corners do not match'
        shared=set(first)&set(second)
        assert len(shared)==2,'Rectangle triangles must share one diagonal'
        a,b=sorted(shared)
        assert a[:2]!=b[:2] and a[2]!=b[2],'Shared edge is not the rectangle diagonal'
        edges=collections.Counter((triangle[i],triangle[(i+1)%3])
                                  for triangle in pair for i in range(3))
        assert edges[(a,b)]==edges[(b,a)]==1,'Internal diagonal winding differs'
        del edges[(a,b)];del edges[(b,a)]
        assert len(edges)==4 and set(edges.values())=={1},'Overlapping rectangle faces'
        following={start:end for start,end in edges}
        assert len(following)==4 and len(set(following.values()))==4,'Broken oriented rectangle boundary'
        boundary=[min(corners)]
        for _ in range(3):boundary.append(following[boundary[-1]])
        assert len(set(boundary))==4 and following[boundary[-1]]==boundary[0],'Open rectangle boundary'
        rectangles[key]=(tuple(boundary),tuple(sorted(shared)))
    return rectangles

def rectangle_retriangulation(old,new):
    """Only opposite diagonals of identical raw, oriented rectangles may differ."""
    before,after=raw_triangles(old),raw_triangles(new)
    common=before&after
    left,right=vertical_rectangles(before-common),vertical_rectangles(after-common)
    assert left and left.keys()==right.keys(),'Rectangle inventories differ'
    for key,(boundary,diagonal) in left.items():
        assert boundary==right[key][0],'Oriented rectangle boundaries differ'
        assert diagonal!=right[key][1],'Retriangulation must use the opposite diagonal'
    return {'method':'raw_float32_vertical_rectangle_opposite_diagonal',
            'rectangles':len(left),'changed_triangles_per_mesh':2*len(left),
            'identical_raw_triangles':sum(common.values()),'coordinate_rounding':False,
            'preserved_sha256':sha(old),'candidate_sha256':sha(new)}
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

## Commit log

2026-09-28 Lower electronics stack and add flush multicolor frame inlays
    [choc-envelope.step, coupon-m2-thread.step, coupon-magnet-base.step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]
2026-09-28 Lower the removable stack and add a flush Level case
    [choc-envelope.step, coupon-m2-thread.step, coupon-magnet-base.step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]
2026-09-28 Correct sculpted cap row direction and preserve custom choices
    [build_viewer_revI.py, check_cap_rows_delivery.py]
2026-09-28 Preserve viewer context and recover designs across failed or concurrent saves
    [check_public_delivery.py, keycap_config.py]
2026-09-28 Replace frames with eleven flush solid-color designs and Flan default
    [left-assembly.step, left-electronics-lid.step, left-frame-arcade-accent.step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]
2026-09-28 Record verified public delivery of the new frame collection
2026-09-29 Restore frame reference compositions and reject clipped artwork
    [left-assembly.step, left-electronics-lid.step, left-electronics-lid.stl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]
2026-09-29 Record public frame fidelity and print download verification
2026-09-29 Prepare exact frame artwork and dimensioned approval masters
    [Artwork-R3.FCStd]
2026-09-29 Refine frame approval drawings with uniform bezels and selected height
    [Artwork-R4.FCStd]
2026-09-29 Implement five approved R4 frames with exact CAD and print geometry
    [flan36-left.kicad_pcb, flan36-right.kicad_pcb, left-assembly.step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]
2026-09-29 Refresh assembly renders from the approved R4 geometry
2026-09-29 Record public verification of approved R4 frames
2026-09-29 Prepare exact six-frame redesigns and verify the display seam candidate
    [Artwork-R5.FCStd, Seam-candidate.FCStd]
2026-09-29 Close display side gaps without changing the stack or deferred artwork
    [left-assembly.step, left-electronics-lid.step, left-electronics-lid.stl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]
2026-09-29 Record verified public seam correction and pending frame approvals
2026-09-29 Add six exact alternative frame concepts for approval
    [Artwork-R6.FCStd]
2026-09-29 Retain Hanafuda and propose three Mecha and Kumiko directions
    [Artwork-R7.FCStd]
2026-09-29 Keep approved frames and propose Evangelion with the M1 palette
    [Artwork-R8.FCStd]
2026-09-29 Limit delivered frames to the approved installed collection
2026-09-29 Record verified approved frames in the public viewer
2026-09-29 Keep right frame artwork in the same reading direction
    [right-assembly.step, right-electronics-lid.step, right-frame-gameboy-accent.step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]
2026-09-29 Record public readback of right frame orientation
2026-10-07 Audit Flan36 geometry, electronics and current validation
2026-10-08 Correct native parameter dependencies, component fit and audit delivery
    [choc-hotswap.step, component-hotswap-0.stl, component-hotswap-1.stl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]
2026-10-08 Record verified public audit delivery and prototype limits
2026-10-08 Route revI boards and ship verified ZMK prototype builds
    [flan36-left.kicad_pcb, flan36-left.kicad_sch, flan36-right.kicad_pcb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]
2026-10-08 Record public readback of routed PCB and firmware candidates
2026-10-09 Redesign mobile viewer navigation and correct original CAD authorship
